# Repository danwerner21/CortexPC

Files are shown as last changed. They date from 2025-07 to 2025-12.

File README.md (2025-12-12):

# CortexPC

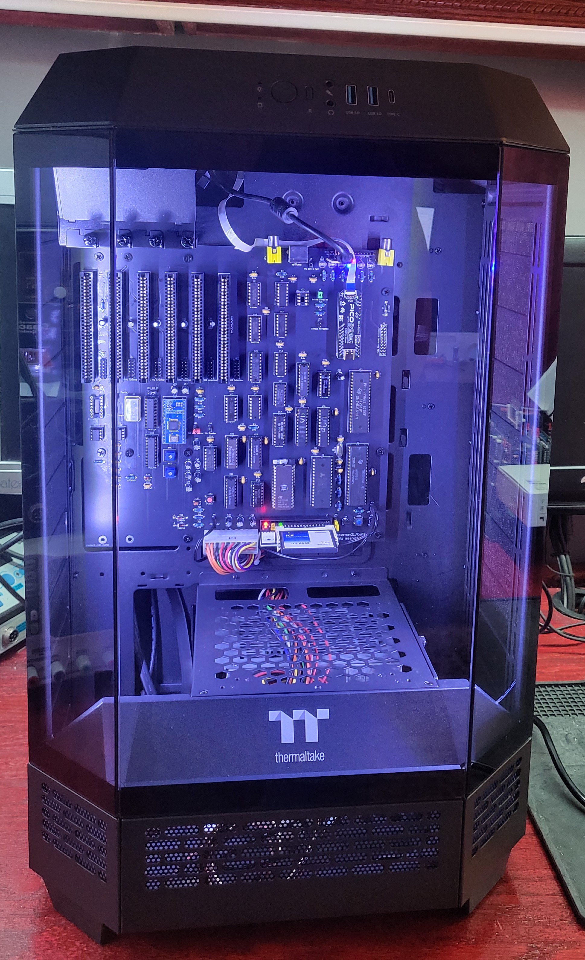
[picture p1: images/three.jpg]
CortexPC


This is an ATX format implimentation of the Mini-Cortex system by Paul Ruizendaal and Stuart Conner.  The Mini-Cortex system is a further development of a TMS 9995 breadboard project to produce a system similar to a Powertran Cortex, but using more modern components. The system is based around a TMS 9995 running at 3 MHz, with 32K byte EEPROM, and will use 512K bytes of RAM  accessed through a memory mapper. An on-board serial port and IDE interface exists on the card.  There is also provisions for a TMS9918 clone, a keyboard and some expansion slots -- these are not totally supported by the firmware at this time however.

The main EEPROM image provides a boot menu which enables the user to select between the EVMBUG system monitor from TI's TMS 9995 Evaluation Module, a port of the Powertran Cortex Power BASIC made for a TM 990 computer, the Marinchip Disk Executive (MDEX) operating system, and an implementation of V6 Unix including a C compiler.

[Much more information can be found at Stuart's site](https://www.stuartconner.me.uk/mini_cortex/mini_cortex.htm)

[Source code for the Cortex Version of Unix V6 and a ton more TI990 software (including cross development tools) can be found here on Dave Pitts' TI-990 web page.](https://www.cozx.com/dpitts/ti990.html)

## Memory Map
The memory map is shown in the table below.

```
Memory Address	Mapped To
>0000 - >7FFF	ROM when enabled, otherwise RAM
>8000 - >EFFF	RAM
>F000 - >F0FB	TMS 9995 internal RAM
>F0FC - >FDFF	RAM
>FE00 - >FE03	CF card ATA registers 
>FE08 - >FE08	SN76489 SOUND
>FE20 - >FE21	Video
>FE40 - >FE4F	Memory mapper registers 0-15 
>FE60 - >FE7F	SID Chip
>FE80 - >FEBF	Offboard IO (ports $80-$FF)
>FFF0 - >FFF9	RAM
>FFFA - >FFFF	TMS 9995 internal RAM

CRU Address	Mapped To
>0000 - >003F	TMS 9902 registers
>0040 - >007F	Control signal latch (further details here)
 	(Plus processor internal CRU bits)
    
(Note that in TI Speak ">" means Hexidecimal, so for the rest of us >FFFA is the same as $FFFA or 0xFFFA or FFFAH)
```
[for more information see Stuart's site](https://www.stuartconner.me.uk/mini_cortex/mini_cortex.htm)

## Creating CF card Image for MDEX and Unix

The CF card has to be newly formatted with an MBR (master boot record), a single partition formatted as FAT32, and a cluster size of 4096 bytes - the CF card needs to be at least 256 MB to support this. Not all brands/sizes of CF card seem to work - you may have more success with an older, low capacity card. A SanDisk 2.0GB card with a "SDCFB" marking on the back works well.

It can be problematic formatting a new card using Windows 10 as it does not always seem to write an MBR to the card. I use a formatting utility called Rufus [details and download here](https://rufus.ie/en/) with Boot selection==Non bootable, Partition Scheme==MBR, File System=FAT32, and Cluster Size= 4096 Bytes. Once the card is correctly formatted, use Windows to write the four files from the software folder ZIP filedirectly to the card.
[for more information see Stuart's site](https://www.stuartconner.me.uk/mini_cortex/mini_cortex.htm)

## Jumper Settings
```
  P6 - ATX Case Power Button
  JP1- ATX Case Reset Button
  JP3- SID Chip CS (Some SID replacement chips need 2-3, default 1-2)
  J21- Enable SID Audio Amp
  J20- SID Speaker Out
  J22- SN76489 Audio Amp
  J23- SN76489 Speaker Out
  J1 - F18A TANG NANO Connector 
  J4 - Serial Interrupt Enabled (Required for UNIX)
  J5 - TTL Serial Interface
  J6 - TTL Serial Power Enable
  JP2- Enable Keyboard Interface
  JP4- ATX Case IDE Led output
  JP5- IDE Power Enable (2-3 for VCC on IDE Pin 20)
  
```
## Powering up
The serial port on the TMS9995 board is configured for 9600 Baud, 7 data bits, even parity, one stop bit, no flow control.

The EVMBUG monitor and the boot loaders for MDEX and Unix, are stored on a single 32K byte EEPROM. The required application is selected from a boot menu. To display the boot menu, connect the board to a configured serial port on a PC, apply power then press any key.

You should then see:
```
  ___         _           ___  ___
 / __|___ _ _| |_ _____ _| _ \/ __|
| (__/ _ \ '_|  _/ -_) \ /  _/ (__
 \___\___/_|  \__\___/_\_\_|  \___|

TMS9995 COMPUTER SYSTEM
BIOS V1.0

PRESS 1 FOR EVMBUG MONITOR
PRESS 2 FOR MDEX
PRESS 3 FOR UNIX
```
To select a software application from the menu, press the corresponding numeric key.

## Useful Links
MDEX documentation is available on the site http://www.powertrancortex.com/documentation.html. The documentation and MDEX disks were recovered and made available by Dave Hunter, the owner of the www.powertrancortex.com site. Porting of the MDEX files to the Mini-Cortex was by Paul Ruizendaal. On the Mini-Cortex, the files are stored in two emulated disks on the CF card.

The first version of Unix ported was LSX Unix (https://www.mailcom.com/lsx/), which was designed to run with 40K byte RAM and two 256K byte floppies. LSX Unix was adapted from Unix V6 by Dr. Heinz Lycklama (https://www.60bits.net/msu/mycomp/terak/termubel.htm). This port has been further ported to the TI 990 minicomputer by Dave Pitts, who has also made improvements to the code build system.

[Dave Pitts' TI-990 web page.](https://www.cozx.com/dpitts/ti990.html)
[EVMBUG documentation](https://www.stuartconner.me.uk/tibug_evmbug/tibug_evmbug.htm#evmbug)

## Bugs/To Do
* No known bugs in V0.9
* Keyboard Firmware needs created and tested

## Troubleshooting

The first test image tests just the processor (TMS9995_test_1_eprom_image), the EPROM and the EPROM chip select logic. Program and fit the EPROM, power on, press the reset switch.  The CPU should execute a loop from ROM., then use the logic probe to check for a series of pulses on pin 20 of the EPROM every 2 seconds or so. 

If the first test passes, repeat with the second test image (TMS9995_test_2_eprom_image), which also tests the RAM and the RAM chip select logic. With the second test, a series of pulses should be seen on pin 20 of the EPROM every 6 seconds or so.

The third test image has two versions.   The first version configures the serial port to 9600 Baud, 7 bits/character, even parity, 2 stops bits, no flow control, and then loops continually sending the ASCII characters >21 ("!") to >7E .  This version tests most of the system including ROM and RAM.   The second version is a ROM only version. It also configures the serial port to 9600 Baud, 7 bits/character, even parity, 2 stops bits, no flow control, and then loops continually sending the ASCII characters >21 ("!") to >7E , but does not use any external RAM.

## Patches
* none needed for V0.9
 
## BOM
Reference|Value|Qty|Description
---------|-----|---|-----------
C1,C2,C3,C4,C5,C6,C7,C8,C9,C10,C11,C12,C13,C14,C15,C16,C17,C19,C21,C23,C25,C27,C29|0.1u|23|
C18,C20,C22,C24|10u|4|
C26|22u|1|
C28|47uF|1|
C30|1uF|1|Polarized capacitor
C31|10uF|1|Polarized capacitor
C32|0.1 uF|1|Unpolarized capacitor
C33|0.01 uF|1|Unpolarized capacitor
C34|100µF|1|
C35|0.1µF|1|
C40,C41|15pf|2|
D1|PWR|1|LED
D2|IDLE|1|LED
D3|MAP|1|LED
D5|1N5817|1|20V 1A Schottky Barrier Rectifier Diode, DO-41
D6|IDE ACT|1|LED
D8|Tx|1|LED
D9|Rx|1|LED
D10,D11|1N4148|2|100V 0.15A standard switching diode, DO-35
J1|F18A TANG NANO Connector|1|Generic connector, double row, 02x10, odd/even pin numbering scheme (row 1 odd numbers, row 2 even numbers), script generated (kicad-library-utils/schlib/autogen/connector/)
J2,J8,J11,J13,J15,J17|IRQ Selection|6|Generic connector, double row, 02x06, odd/even pin numbering scheme (row 1 odd numbers, row 2 even numbers), script generated (kicad-library-utils/schlib/autogen/connector/)
J3,J10,J12,J14,J16,J18|Bus_I_not_SA_8bit|6|8-bit ISA-PC bus connector
J4|Enable Serial Int|1|Generic connector, single row, 01x02, script generated
J5|TTL SERIAL 0|1|
J6|TTL SER 0 PWR|1|
J7|USER OUT|1|Generic connector, single row, 01x07, script generated
J9|AUDIO OUT|1|coaxial connector (BNC, SMA, SMB, SMC, Cinch/RCA, LEMO, ...)
J19|Parallel Keyboard IN|1|Generic connector, single row, 01x11, script generated
JP1|JUMPER|1|Generic connector, single row, 01x02, script generated (kicad-library-utils/schlib/autogen/connector/)
JP4|EXT IDE LED|1|
JP5|IDE PWR|1|
P1|14.31818 MHz CLK|1|
P4|8 BIT IDE (CF)|1|
P5|CONN_10X2|1|Generic connector, double row, 02x10, odd/even pin numbering scheme (row 1 odd numbers, row 2 even numbers), script generated (kicad-library-utils/schlib/autogen/connector/)
P6|POWER_SW|1|Generic connector, single row, 01x02, script generated (kicad-library-utils/schlib/autogen/connector/)
R1,R3,R6,R7,R11,R12,R13,R17|470|8|-- mixed values --
R2,R4,R8,R10,R14|10K|5|
R5|1000|1|Resistor
R9|10Ω|1|
R16,R18|10k|2|Resistor
SW1|RESET|1|Push button switch, generic, two pins
SW2|POWER|1|Push button switch, generic, two pins
U1|74LS14|1|
U2|74LS07|1|
U3|TMS9995-DIP_1|1|
U4|74LS04|1|
U5,U27|74LS74|2|-- mixed values --
U6|74LS112|1|
U7|SN76489|1|
U8|DS1233|1|
U9|SRAM_512K|1|512K x 8 Low Power CMOS RAM, DIP-32
U10|TMS9918 EMU|1|
U11,U30|GAL22V10|2|
U12,U13|74LS32|2|Quad 2-input OR
U14,U28,U29,U31|74LS244|4|Octal Buffer and Line Driver With 3-State Output, active-low enables, non-inverting outputs
U15|74LS138|1|
U17|74LS688|1|
U18|27C256|1|
U21|TMS9902A|1|
U22|74LS259|1|
U23|74LS612-DIP|1|
U25|74LS245|1|Octal BUS Transceivers, 3-State outputs
U26|74HCT14|1|Hex inverter schmitt trigger
Y1|12MHz|1|

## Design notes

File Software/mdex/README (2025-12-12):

Software originally from:  https://gitlab.com/marinchip/

INTRODUCTION

These are the recreated source files for the MDEX operating system. The drivers
are surviving from the 1980's and the kernel source was mostly recreated in
the mid-80's by Peter Buro. The recommenting was completed in 2024.

MARINCHIP DISC EXECUTIVE - MDEX

As John Walker was bootstrapping his software stack, he needed a simple OS.
This became MDEX. It is similar to early CP/M or RT11 in its structure. In
order to be forward compatible, the system call interface was chosen to be
a subset of the NOS/MT operating system that John was already designing.
This proved very successful: nearly all programs that run under NOS/MT also
run under MDEX.

The unintended result was that MDEX became more popular than NOS/MT, also
because it did not need a hard disk (NOS/MT can run from floppies, but is
comfortable with a hard disk).

Being only 8KB in size with a simple, easy to understand internal structure,
it is a good match for retro 9900 based projects, as it gives such a project
an instant software stack to work with. It was the first OS to run on the
mini-Cortex.

John Walker writes on his website: "MDEX (which was originally called
Sisyphus Junior) was written with the Univac assembler, downloaded and
tested on my S-100 prototype machine. Debugging was via the PROM monitor,
which allowed examining and changing registers and memory without the
need for a front panel. MDEX, the Assembler, Linker, Editor, and Debugger,
were all originally written on the Univac assembler in its syntax.

The [Marinchip] assembler, however, used the standard TI syntax for its
instructions. When I wrote of MDEX being rewritten as 'native', I was referring
to converting the syntax of the assembly code from that used by the Univac
cross-assembler to native TI syntax which my assembler used and moving the
development from the Univac to the 9900 machine itself. By some time in 1979,
all development had moved to the 9900 and the Univac was no longer used.

I had access to the Univac because I was working for a company that owned it
and used it moonlighting. I had to move development to the 9900 because I
couldn't quit my job and lose access to the Univac until I did so.

In parallel with this software development, Fred Camerer, who had joined the
company as an equal partner, redesigned my two-board S-100 prototype into the
single-board design which became the M9900 CPU. This was designed by hand and
drawn as a logic diagram, from which the board was laid out using red and blue
tape at 4X scale. Part of the final layout was done on my dining room table.

Once we got and debugged the first run of five printed circuit boards, I
replaced the two board wire wrapped prototype in my IMSAI chassis with the
first M9900 CPU. It was completely compatible from the software standpoint, but
also had the ability to use 16-bit memory through the handshake protocol Fred
Camerer invented, which eventually became part of the S-100 standard
(IEEE-696-1983). It also brought out the 9900's CRU peripheral interface to
unused pins on the S-100 bus (of which there were plenty), which allowed access
to the serial ports on the PROM/RAM and eventual Quad SIO cards."

BUILDING

The MDEX kernel is a single 2400 line assembler file. Its main parts are
the command loop, the system call library and the console line editor -
complemented by a few libraries for message formatting, memory management
and floating point emulation.

It has three device drivers: one for the console terminal, one for the
printer and one for the disk drives.

The combined kernel is built with the make.sh script in the root directory
of this repo.

RUNNING

The Cortex emulator can run MDEX. It needs to be provided with two floppy
disk images, mdex1.dsk and mdex2.dsk respectively. These will be drive
"1/" and dirve "2/" inside MDEX.

Two images are provided: the MDEX release disk ("1/") and the basic games
disk ("2/"). Other images of original 640KB MDEX disks (for instance from
the www.powertrancortex.com website) can be used instead, such as the
QBasic, Pascal and SPL compiler disks.

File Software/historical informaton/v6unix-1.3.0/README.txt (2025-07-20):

V6 Unix 1.3.0
Date: 2020/10/01

I. Introduction

The V6 Unix distribution supports the TI-990 line of minicomputers. The models
supported are 990/10, 990/10A and 990/12 with a minimum of 512K of memory.
Also, supported is the Powertran Cortex using the TI TMS9995 chip with extended
memory.

The devices support in the version:

   DISK      - Any 10MB or larger TILINE disk. Address >F800 interrupt 13.
   TAPE      - TILINE attached tape drive. Address >F880 interrupt 9.
   Printer   - Serial printer on CRU >60 interrupt 14.
   Console   - Serial terminals:
      TTYEIA: TTY/EIA Card:
         tty0 - CRU >0 interrupt 6
      TTY9902: TMS9902 console port:
         tty0 - 990/10A CRU >1700 interrupt 8, Cortex CRU >0 interrupt 4.
   Terminals   - Serial terminals:
      VDT911: 911 VDT, runs as a "glass" tty:
         tty1 - port 0, CRU >100 interrupt 10
         tty2 - port 1, CRU >120 interrupt 8
      TTY403: CI 403 serial multiplexor, Address >F980 interrupt 11:
         tty3 - port 0.
         tty4 - port 1.
         tty5 - port 2.
         tty6 - port 3.

II. Build the System

To build the V6 Unix you need to download and extract the source tarball:

   $ tar xzf v6unix-1.3.0-source.tar.gz
   $ cd v6unix

Then run make:

   $ make [MODEL=model] [DISK=disk] [CONSOLE=console] [MAXSIZE=maxsize]

Where:

   model   - TI990, TI990_10A, TI990_12 or TI_CTX, Default = TI990.
             TI990     - Standard TI-990.
             TI990_10A - /10A support, console port and Extended instructions.
             TI990_12  - /12 support, Extended instructions.
	     TI_CTX    - Powertran Cortex using a TMS9995 chip.

   disk    - DS10, DS25, DS50, DS80, DS200, DS300 or larger disk,
	     Default = DS50.

   console - TTYEIA or TTY9902, Default = TTYEIA.
             TTYEIA  - TTYEIA cards.
             TTY9902 - TMS9902 console port. Only on TI990_10A and TI_CTX.

   maxsize - Size of / filesystem in bytes. Default = 33024000 (64500 blocks).
             DS10 = 3643000 (7115 blocks)
	     DS25 = 19301000 (37697 blocks)

The swap area, 1024 blocks, limits the size of the / file system to 33024000
bytes or 64500 blocks. V6 Unix limits the size of filesystems to a mximum of
65535 blocks. On smaller devices the root partition on the primary device will
be the size of the device minus the swap area.

III. Run the System

To run the system as shown here you will need to download, build and install 
the sim990 simulator. The Powertran Cortex is not supported by sim990.

1. To run under sim990, with the default build, place the following into a
   configuration file (v6unix.cfg):

   a ce >0 6 TTY
   a pe >60 14 print.out
   a v0 >100 10 2011
   a v1 >120  8 2012
   a a30 >F980 11 LOOP
   a a31/t >F980 11 2013
   a a32/t >F980 11 2014
   a m0 >F880 9 NULL
   a d0 >F800 13 v6unix.dsk
   b d0

   The terminal tty0 is the console and the additional terminals tty1, tty2,
   tty4 and tty5 are accessible using telnet on ports 2011, 2012, 2013 and 2014.

   The terminals tty1 and tty2 are 911 VDTs. The terminals tty4 and tty5 are 
   CI403 connected serial terminals.

   The terminals have the login process started on them based upon the
   /etc/ttys file (man 5 ttys). As a default only the console (/dev/tty0) has
   a login process.

   tty3 is allocated to the network process as SLIP device sl0. The
   configuration file, above, is set to loopback. For a real serial connection
   you can configure the device for example:

   a a30/r >F980 11 /dev/tty1

2. Start sim990

   $ sim990 -msc 12 1m v6unix.cfg
   TI 990 simulator 3.5.6: /12 CPU 1024K

   Mem................1024KB
   Initialize Date/Time
      Year: 2020
     Month: 8
       Day: 6
      Hour: 8
    Minute: 49
   Thu Aug 06 08:49:00 2020
   Booting V6 Unix
   Network process running.

   login: 

3. Login

   Two accounts have been provided for user:

   Username: root	Password: root
   Username: guest	Password: guest 

   For example:

   login: guest
   Password: 
   ***********************************
   *   Running Unix V6 on a TI-990   *
   ***********************************

   $ ls
   hello.c        makefile       romans.l       
   $ make
   cc -o hello hello.c
   lex -t romans.l >romans.c
   cc -o romans romans.c -L/lib -lln
   $ hello
   Hello World!
   $ romans
   MMXIV IX
   2014 + 9 = 2023
   $ exit

   login:

IV. Disk Partitions

This implementation supports a maximum of 16 partitions of a maximum of 65535
blocks per partition. When the system is booted it probes the disk geometry and 
creates a table in the kernel of active drives and paritions. Then /dev entries
are created for each active disk and partition. The boot disk partition, if on
unit 0, is /dev/dsk0. Additional, as needed, partitions on the drive are
/dev/dsk0p1 through /dev/dsk0p15. On smaller disks you may only have the root
partition. This works out to a maximum supported disk size of 512MB.

For example on the default DS50 disk there are only two partitions:

   /dev/dsk0   - Root/boot partition (64500 blocks, 1024 blocks swap).
   /dev/dsk0p1 - 11836 blocks.

For a DS200 the partitions are:

   /dev/dsk0   - Root/boot partition (64500 blocks, 1024 blocks swap).
   /dev/dsk0p1 - 65535 blocks.
   /dev/dsk0p2 - 65535 blocks.
   /dev/dsk0p3 - 65535 blocks.
   /dev/dsk0p4 - 31368 blocks.

For a DS10 only the root partition, less the swap area.

   /dev/dsk0   - Root/boot partition (7115 blocks, 1024 blocks swap).

The mkfs program, /etc/mkfs, will probe the size of the partition, as default,
and create the filesystem to the maximum size for that partition. For example
on the default DS50 disk:

   # /etc/mkfs /dev/dsk0p1
   # /etc/mount /dev/dsk0p1 /mnt
   # df
   Filesystem    512B-blocks       Used  Available Use% Mount
   /dev/dsk0           64500       4107      60393   6% /
   /dev/dsk0p1         11836        222      11614   1% /mnt

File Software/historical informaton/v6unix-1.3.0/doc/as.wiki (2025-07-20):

<b>AN INTRODUCTION TO THE TI990 UNIX ASSEMBLER</b>

This document describes the usage and input syntax of the ancient Unix TI990 assembler <b>as</b>.
The details of the TI990 architecture are not described.
The input syntax of this assembler is generally similar to that of the original Ritchie PDP-11 assembler.
The actual code is a derivative of Richard Miller's assembler for the port of Unix to the Interdata 7/32.
This document is a derivative of the Ritchie file note on the Unix assembler. 

The <b>as</b> assembler is a rather ordinary assembler without macro capabilities.
It produces an output file that contains relocation information and a complete symbol table;
thus the output is acceptable to the Unix link-editor <b>ld</b>, which may be used to combine the outputs
of several assembler runs and to obtain object programs from libraries.
The output format has been designed so that if a program contains no unresolved references to external
symbols, it is executable without further processing.

<br>
<b>1. Usage</b>

The command line syntax for <b>as</b> as follows:
<verbatim>
  as [−u] [-l] [−o outfile] infile [,infile]...
</verbatim>
If the optional "−u" argument is given, all undefined symbols in the current assembly will be made
<i>undefined-external</i>. Also see the .globl directive below.
If the optional "-l" argument is given, a listing file is printed to the standard output.
The output of the assembler is by default placed on the file a.out in the current directory;
the optional "−o" flag causes the output to be placed on the named file.
If there were no unresolved external references, and no errors detected, the output file is marked executable;
otherwise, if it is produced at all, it is made non-executable.
The other arguments name files which are concatenated and assembled. Thus programs may be written in
several pieces and assembled together.

<br>
<br>
<b>2. Lexical conventions</b>

Assembler tokens include identifiers (alternatively, "symbols" or "names"), temporary symbols, constants, and operators.

<u>2.1 Identifiers</u>

An identifier consists of a sequence of alphanumeric characters (including period ".", underscore "_",
and tilde " ̃" as alphanumeric) of which the first may not be numeric. Only the first eight characters are significant.
When a name begins with a tilde, the tilde is discarded and that occurrence of the identifier generates a unique entry
in the symbol table which can match no other occurrence of the identifier. This feature is used by the C compiler to
place names of local variables in the output symbol table without having to worry about making them unique.

<u>2.2 Temporary symbols</u>

A temporary symbol consists of a single digit followed by "f" or "b". Temporary symbols are discussed fully in section 5.1.

<u>2.3 Constants</u>

Constants are 16 bit quantities and can have one of four forms:
  *  a constant starting with the sequence "0x" is a hexadecimal number constant.
  *  a constant starting with the digit "0" is an octal constant. A digit larger than 7 terminates the constant.
  *  a constant starting with one of the other digits (i.e. "1" through "9") is a decimal constant
  *  a constant starting with a single quote (') initiates a character constant.

Numeric constants can have any number of digits, but the value is truncated to the lower 16 bits of the resulting number.
The constant is interpreted as a two’s complement value: -1 and 65535 both denote a constant with 16 "1" bits.

A single-character constant consists of a quote followed by an ASCII character not a new-line, followed by another
single quote. Certain dual-character escape sequences are acceptable in place of the ASCII character to represent
new-line and other non-graphics (see String statements, section 5.5). The constant’s value has the code for the
given character in the least significant byte of the word and is null-padded on the left. It is permissible to have
a second ASCII character following the first, to make up a word sized constant. In that case the constant’s value has
the code for the first given character in the least significant byte and that for the second character in the most
significant byte. Character constants with either zero or more than 2 ASCII characters occuring between the opening
and closing quote constitute a syntax error.

<u>2.4 Operators</u>

There are several single character operators; see section 6.

<u>2.5 Blanks</u>

Blank and tab characters may be interspersed freely between tokens, but may not be used within tokens
(except character constants). A blank or tab is required to separate adjacent identifiers or constants not
otherwise separated.

<u>2.6 Comments</u>

The two character sequence "//" (slash-slash) introduces a comment, which extends through the end of the line on
which it appears. Comments are ignored by the assembler.

<br>
<b>3. Segments</b>

Assembled code and data fall into three segments: the text segment, the data segment, and the bss segment.

  *  The text segment is the one in which the assembler begins, and it is the one into which instructions
are typically placed. The UNIX system will, if desired, enforce the purity of the text segment of programs
by trapping write operations into it. Object programs produced by the assembler must be processed by the
link-editor <b>ld</b> (using its "−n" flag) if the text segment is to be write-protected. A single copy of
the text segment is shared among all processes executing such a program.

  *  The data segment is available for placing data or instructions which will be modified during execution.
Anything which may go in the text segment may also be put into the data segment. In programs with write-protected,
sharable text segments, data segment contains the initialized but variable parts of a program. If the text segment
is not pure, the data segment begins immediately after the text segment; if the text segment is pure, the data
segment begins at the lowest 8K byte boundary after the text segment.

  *  The bss segment may not contain any explicitly initialized code or data. The length of the bss segment
(like that of text or data) is determined by the high-water mark of the location counter within it. The bss segment
is actually an extension of the data segment and begins immediately after it. At the start of execution of a
program, the bss segment is set to 0. Typically the bss segment is set up by statements exemplified by
<verbatim>
lab: . = .+10
</verbatim>
The advantage in using the bss segment for storage that starts off empty is that the initialization information
need not be stored in the output file.

The assembler switches between the three segments through the pseudo statements <b>.text</b>, <b>.data</b> and
<b>.bss</b>, which are discussed in section 7.6, 7.7 and 7.8.

Each segment has its own location counter during assembly and the segments are relocated to their sequential
positions at the very end of the assembly process (and possibly again by the link-loader <b>ld</b>). See also
section 4, Location counter and section 5.4, Assignment statements.

<br>
<b>4. The location counter</b>

One special symbol, ".", refers to the location counter of the current segment. Its value at any time is
the offset within the appropriate segment of the start of the statement in which it appears. The location
counter may be assigned to, with the restriction that the current segment may not change.

<br>
<b>5. Statements</b>

A source program is composed of a sequence of statements. Statements are separated either by newlines or by
semicolons. There are five kinds of statements:
  *  null statements
  *  expression statements
  *  assignment statements
  *  string statements
  *  keyword statements.

Any kind of statement may be preceded by one or more labels.

<u>5.1 Labels</u>

There are two kinds of label: name labels and numeric labels. A name label consists of a name followed by
a colon (":"). The effect of a name label is to assign the current value and type of the location counter (".")
to the name. An error is indicated in the first pass if the name is already defined; an error is indicated in
subsequent passes if the (".") value assigned changes the definition of the label.

A numeric label consists of a digit 0 to 9 followed by a colon (":"). Such a label serves to define temporary
symbols of the form "<i>n</i>b" and "<i>n</i>f", where <i>n</i> is the digit of the label. As in the case of
name labels, a numeric label assigns the current value and type of "." to the temporary symbol. However, several
numeric labels with the same digit may be used within the same assembly. References of the form "<i>n</i>f" refer
to the first numeric label "<i>n</i>:" <u>f</u>orward from the reference;
"<i>n</i>b" symbols refer to the first "<i>n</i>:" label <u>b</u>ackward from the reference. This sort of temporary
label was introduced by Knuth in "The Art of Computer Programming, Vol I: Fundamental Algorithms". Such labels
tend to conserve both the symbol table space of the assembler and the inventive powers of the programmer.

<u>5.2 Null statements</u>

A null statement is an empty statement (which may, however, have labels). A null statement is ignored by the
assembler. Common examples of null statements are empty lines or lines containing only a label.

<u>5.3 Expression statements</u>

An expression statement consists of an arithmetic expression not beginning with a keyword. The assembler computes
its (16-bit) value and places it in the output stream, together with the appropriate relocation bits.

<u>5.4 Assignment statements</u>

An assignment statement consists of an identifier, an equals sign ( = ), and an expression. The value and type of
the expression are assigned to the identifier. It is not required that the type or value be the same in pass 2 as
in pass 1, nor is it an error to redefine any symbol by assignment.

Any external attribute of the expression is lost across an assignment. This means that it is not possible to declare
a global symbol by assigning to it, and that it is impossible to define a symbol to be offset from a non-locally
defined global symbol.

As mentioned, it is permissible to assign to the location counter ".". It is required, however, that the type of
the expression assigned be of the same type as ".", and it is forbidden to decrease the value of ".".
In practice, the most common assignment to "." has the form ". = . + n" for some number n; this has the effect
of generating n null bytes.

<u>5.5 String statements</u>

A string statement generates a sequence of bytes containing ASCII characters. A string statement consists of a double
quote <b>"</b> followed by a sequence of ASCII characters not including newline, followed by a closing double quote
<b>"</b>. Any of the ASCII characters may be replaced by a two-character escape sequence to represent certain
non-graphic characters, as follows:
<table>
<tr><td><u>Escape</u></td><td><u>Hex</u>&nbsp;&nbsp;&nbsp;</td><td><u>Meaning</u></td></tr></b>
<tr><td>\n</td><td>0x0a</td><td>newline</td></tr>
<tr><td>\r</td><td>0x0d</td><td>carriage return</td></tr>
<tr><td>\t</td><td>0x0b</td><td>horizontal tab</td></tr>
<tr><td>\v</td><td>0x0c</td><td>vertical tab</td></tr>
<tr><td>\0</td><td>0x00</td><td>null</td></tr>
</table>

All other characters following a \ represent themself, i.e. \\ denotes a single backslash and \" denotes a double quote.
The latter does not terminate the string, but becomes a character of the string. The same escape sequences may also be
used within singlea nd double-character constants (see section 2.3 above).

<u>5.6 Keyword statements</u>

Keyword statements are numerically the most common type, since machine instructions are of this sort. A keyword
statement begins with one of the many predefined keywords of the assembler; the syntax of the remainder depends on
the keyword. Section 8 discusses machine instructions and their syntax in more detail.

<br>
<b>6. Expressions</b>

An expression is a sequence of symbols representing a value. Its constituents are identifiers, constants,
temporary symbols, operators, and brackets. Each expression has a type.
All operators in expressions are fundamentally binary in nature; if an operand is missing on the left,
a 0 of absolute type is assumed. Arithmetic is two’s complement and has 16 bits of precision. All
operators have equal precedence, and expressions are evaluated strictly left to right; parentheses are
reserved for addressing modes and cannot be used for expression grouping.

<u>6.1 Expression operators</u>

The operators are:
<table>
<tr><td>+</td><td>addition</td></tr>
<tr><td>-</td><td>subtraction</td></tr>
<tr><td>*</td><td>multiplication</td></tr>
<tr><td>/</td><td>division</td></tr>
<tr><td>|</td><td>bitwise or</td></tr>
<tr><td>&</td><td>bitwise and</td></tr>
</table>
All operators work on 16 bit two's complement words and overflow is not detected.

<u>6.2 Types</u>

The assembler deals with a number of types of expressions. Most types are attached to keywords and used
to select the routine which treats that keyword. The types likely to be met explicitly are:
  *  <u>undefined</u>: Upon first encounter, each symbol is undefined. It may become undefined if it is
assigned an undefined expression. It is an error to attempt to assemble an undefined expression in pass 2;
in pass 1, it is not (except that certain keywords require operands which are not undefined).

  *  <u>undefined external</u>: A symbol which is declared <b>.globl</b> but not defined in the current
assembly is an undefined external. If such a symbol is declared, the link editor <b>ld</b> must be used to
load the assembler’s output with another routine that defines the undefined reference.

  *  <u>absolute</u>: An absolute symbol is defined ultimately from a constant. Its value is unaffected
by any possible future applications of the link-editor to the output file.

The value of a text symbol is measured with respect to the beginning of the text segment of the program. 
  *  <u>text</u>: The value of a text symbol is measured with respect to the beginning of the text segment
of the program. If the assembler output is link-edited, its text symbols may change in value since the
program need not be the first in the link editor’s output. Most text symbols are defined by appearing
as labels. At the start of an assembly, the value of "." is text 0.

  *  <u>data</u>: The value of a data symbol is measured with respect to the origin of the data segment of a program.
Like text symbols, the value of a data symbol may change during a subsequent link-editor run since previously
loaded programs may have data segments. After the first .data statement, the value of "." is data 0.

  *  <u>bss</u>: The value of a bss symbol is measured from the beginning of the bss segment of a program.
Like text and data symbols, the value of a bss symbol may change during a subsequent link-editor run,
since previously loaded programs may have bss segments. After the first .bss statement, the value of "." is bss 0.

  *  <u>external absolute, text, data, or bss</u>: Symbols declared .globl but defined within an assembly
as absolute, text, data, or bss symbols may be used exactly as if they were not declared .globl; however,
their value and type are available to the link editor so that the program may be loaded with others that
reference these symbols.

The assembler does not have a separate type for registers: these are refered to by an absolute value in
the range 0 to 15. The assembler predefines the symbols <b>r0</b> through to <b>r15</b> with these values
to make source code easier to read. As a consequence, one can refer to r3 as "r0+3".
<b>sp</b> is a synonym for <b>r15</b> and <b>bp</b> is a synonym for <b>r14</b>.

Each keyword known to the assembler has a type which is used to select the routine which processes the
associated keyword statement. The behavior of such symbols when not used as keywords is the same as if
they were absolute.

<u>6.3 Type propagation in expressions</u>

When operands are combined by expression operators, the result has a type which depends on the types of
the operands and on the operator. The rules involved are complex to state but were intended to be sensible
and predictable. For purposes of expression evaluation the important types are
  *  undefined
  *  absolute
  *  text
  *  data
  *  bss
  *  undefined external
  *  other

The combination rules are then:
  *  If one of the operands is undefined, the result is undefined.
  *  If both operands are absolute, the result is absolute. If an absolute is combined with one of
the "other types" mentioned above, the result has the other type.
  *  If two operands of "other type" are combined, the result has the numerically larger type
  *  An "other type" combined with an explicitly discussed type other than absolute acts like an absolute.

Further rules applying to particular operators are:
  *  "+": If one operand is text-, data-, or bss-segment relocatable, or is an undefined external,
the result has the postulated type and the other operand must be absolute.
  *  "−": If the first operand is a relocatable text-, data-, or bss-segment symbol, the second operand
may be absolute (in which case the result has the type of the first operand); or the second operand may
have the same type as the first (in which case the result is absolute). If the first operand is external
undefined, the second must be absolute. All other combinations are illegal.

<br>
<b>7. Pseudo-operations</b>

The keywords listed below introduce statements that generate data in unusual forms or influence the later
operations of the assembler. The meta notation "<nowiki>[stuff]...</nowiki>"
means that zero or more instances of the given stuff may appear. Also, boldface tokens are literals,
italic words are substitutable.

<b>7.1 .byte</b> <i>expression <nowiki>[ ,expression]...</nowiki></i>

The expressions in the comma-separated list are truncated to 8 bits and assembled in successive bytes. The
expressions must be absolute. This statement and the string statement above are the only ones that
assemble data one byte at at time.

<b>7.2 .even</b>

If the location counter "." is odd, it is advanced by one so the next statement will be assembled at a word
boundary.

<b>7.3 .if</b> <i>expression</i>

The <i>expression</i> must be absolute and defined in pass 1. If its value is nonzero, the <b>.if</b> is
ignored; if zero, the statements between the <b>.if</b> and the matching <b>.endif</b> (below) are ignored.
<b>.if</b> may be nested. The effect of <b>.if</b> cannot extend beyond the end of the input file in which
it appears.

<b>7.4 .endif</b>

This statement marks the end of a conditionally-assembled section of code. See <b>.if</b> above.

<b>7.5 .globl</b> <i><nowiki>name [, name]...</nowiki></i>

This statement makes the names external. If they are otherwise defined (by assignment or appearance as a
label) they act within the assembly exactly as if the <b>.globl</b> statement were not given; however, the link
editor <b>ld</b> may be used to combine this routine with other routines that refer these symbols.

Conversely, if the given symbols are not defined within the current assembly, the link editor can combine
the output of this assembly with that of others which define the symbols. As discussed in section 1, it is
possible to force the assembler to make all otherwise undefined symbols external.

<b>7.6 .text</b>

<b>7.7 .data</b>

<b>7.8 .bss</b>

These three pseudo-operations cause the assembler to begin assembling into the text, data, or bss segment
respectively. The location counter is made even, i.e. after sitching segment, an <b>.even</b> statement is
implied. Assembly starts in the text segment. It is forbidden to assemble any code or data into the
bss segment, but symbols may be defined and "." moved about by assignment.

<b>7.9 .comm</b> <i>name , expression</i>

Defines and external symbol of size <i>expression</i>. In effect, <i>name</i> behaves in the current assembly
just like an undefined external. However, the link-editor <b>ld</b> has been special-cased so that all external
symbols which are not otherwise defined, and which have a non-zero value, are defined to lie in the bss segment,
and enough space is left after the symbol to hold expression bytes. All symbols which become defined in this way
are located before all the explicitly defined bss-segment locations.

<br>
<b>8. Machine instructions</b>

The assembler implements all instructions of the TMS9995 processor and several synthetic instructions. The latter
can be thought of as built-in macro's.

<u>8.1 Instruction mnemonics</u>

All the standard mnemonics of the TMS9995 processor are supported. The mnemonics must be in lowercase in order
to be recognised, i.e. "lwpi" is an instruction mnemonic, "LWPI" is an undefined symbol.

<u>8.2 Operands</u>

The assembler uses a different operand syntax than the standard Texas Instruments syntax for the TI990. The
relationship is shown below:
<table>
<tr><td><b>Mode</b></td><td><b>as syntax</b></td><td><b>TI syntax</b></td><td><b>Example</b></td><tr>
<tr><td>register</td><td>rn</td><td>RN</td><td>mov r0,r1</td><tr>
<tr><td>indirect</td><td>(rn)</td><td>*RN</td><td>dec (r1)</td><tr>
<tr><td>auto increment&nbsp;&nbsp;&nbsp;</td><td>(rn)+</td><td>*RN+</td><td>clr (r1)+</td><tr>
<tr><td>direct</td><td>@name</td><td>@NAME</td><td>s r0,@var</td><tr>
<tr><td>indexed</td><td>@name(rn)&nbsp;&nbsp;&nbsp;&nbsp;</td><td>@NAME(RN)&nbsp;&nbsp;&nbsp;&nbsp;</td><td>mov @table(r1),r0</td><tr>
<tr><td>immediate</td><td>expr</td><td>expr</td><td>lwpi len+1</td><tr>
<tr><td>relative</td><td>expr</td><td>expr</td><td>jmp .+2</td><tr>
</table>

Note that an absolute expression evaluating to a number between 0 and 15 is acceptable whereever a register is
required and that names could be offset by an absolute constant. Relative expressions in jumps must be within
-128 to +127 words from "." in the current segment. Relative expressions in CRU instructions must be absolute
and lie between -128 and +127.

<u>8.3 Extended branch instructions</u>

The assembler accepts a set of synthetic instructions for conditional branches that work both with near (within
-128 to +127 words) and far (all other) destinations:
<table>
<tr><td><b>Mnemonic&nbsp;&nbsp;&nbsp;</b></td><td><b>Meaning</b></td></tr>
<tr><td>bjmp</td><td>branch or jump unconditionally</td></tr>
<tr><td>bjeq</td><td>branch or jump on equal</td></tr>
<tr><td>bjne</td><td>branch or jump on not equal</td></tr>
<tr><td>bjlt</td><td>branch or jump on signed less than</td></tr>
<tr><td>bjls</td><td>branch or jump on signed less or same</td></tr>
<tr><td>bjgt</td><td>branch or jump on signed greater</td></tr>
<tr><td>bjgs</td><td>branch or jump on signed greater or same</td></tr>
<tr><td>bjl</td><td>branch or jump on unsigned lower</td></tr>
<tr><td>bjle</td><td>branch or jump on unsigned lower or equal</td></tr>
<tr><td>bjh</td><td>branch or jump on unsigned higher</td></tr>
<tr><td>bjhe</td><td>branch or jump on unsigned higher or equal</td></tr>
</table>

These instructions are either implemented as one or two conditional jump instructions, or as the reverse
conditional jump(s) over an unconditional branch condition. The "bjmp" instruction expands to either "jmp" or
"b" depending on the destination distance.

<u>8.4 Other instructions</u>

The assembler accepts one special instruction mnemonic, "sys". This instruction takes a single, unadorned
argument and currently expands to a "xop 1" instruction:

  *  "sys 23" expands to "xop @23,1"

This instruction is used to trap into the operating system. It has been added a macro to make it easy to
vary the trap mechanism for various implementations of the TI990 architecture. An alternative trap
mechanism could work with external instructions.

<br>
<b>9. Errors</b>

When an input file cannot be read, its name followed by a question mark is typed and assembly ceases.
When syntactic or semantic errors occur, a diagnostic is typed out together with the line number and
the file name in which it occurred. Errors in pass 1 cause cancellation of pass 2.
The possible errors are:

  *  "Previously defined absolute value required"
  *  "Short branch out of range"
  *  "Illegal or missing opcode"
  *  "Illegal data in .bss segement"
  *  "EOF or END within .if"
  *  "Garbage character"
  *  "Word value too large"
  *  "Improper nesting of .if and .endif"
  *  "Missing label"
  *  "Multiply defined symbol"
  *  "Number syntax"
  *  "Cannot move location counter backwards"
  *  "Symbol value changed between passes"
  *  "Missing quote"
  *  "Relocation error"
  *  "Missing symbol"
  *  "Undefined symbol"
  *  "Illegal value (e.g. register >15)"
  *  "Syntax error"
  *  "Division by zero"
  *  "Too many numeric labels"

<br>
<b>10. Example</b>

The following assembler program prints out "Hello, world!" to the standard output on a Unix system.
<verbatim>
reset:	0xf000; start

start:	stwp	sp
	ai	sp,-6
	mov	@len,@4(sp)
	mov	@str,@2(sp)
	mov	@one,(sp)
	sys	4
	ai	sp,6
	idle

	.data
one:	1		// stdout
str:	1f		// &str
len:	strend - 1f	// len

1:	"Hello, world!\n"
	strend = .
</verbatim>

The assembler list output for the above program is:
<verbatim>
0000t                    00001  
0000t F000a 0004t        00002  reset:	0xf000; start
0004t                    00003  
0004t 02AFa              00004  start:	stwp	sp
0006t 022Fa FFFAa        00005  	ai	sp,-6
000At CBE0a 0028d 0004a  00006  	mov	@len,@4(sp)
0010t CBE0a 0026d 0002a  00007  	mov	@str,@2(sp)
0016t C7E0a 0024d        00008  	mov	@one,(sp)
001At 2C60a 0004a        00009  	sys	4
001Et 022Fa 0006a        00010  	ai	sp,6
0022t 0340a              00011  	idle
0024t                    00012  
0024t                    00013  	.data
0024d 0001a              00014  one:	1		// stdout
0026d 002Ad              00015  str:	1f		// &str
0028d 000Ea              00016  len:	strend - 1f	// len
002Ad                    00017  
002Ad 48656C6C6F2C2077a> 00018  1:	"Hello, world!\n"
0038d                    00019  	strend = .
0038d                    00020
</verbatim>

The suffix letter "t", "d" or "b" after the location denotes the segment that location is associated with.
The suffix letters for the assembled code denote the relocatability of that word:
  *  a = absolute, no relocation
  *  t = relocated with text segment
  *  d = relocated with data segment
  *  b = relacated with bss segment
  *  u = undefined
  *  U = undefined external
  
If the last word or byte value is followed by an angle bracket (">"), there are more words or bytes generated
for that particular line than shown.

The column preceding the source text in the listing is the (decimal) line number.

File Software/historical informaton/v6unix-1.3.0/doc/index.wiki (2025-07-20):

This repository contains a port of the "Ritchie C compiler" to the TI990 series processors, in particular the 9995 and 99105 chips. The port is currently fairly complete; only floating point operations remain unported. Other tool chain components (assembler, linker, etc.) are also provided.

The long term goal is to run ancient unix on these chips. As a first stepping stone on that journey, a port of the original 1983 version of the Xinu system has already been completed. The source for that is also in this repository.

"Ancient Unix" is a term refering to the research versions of the late 70's and early 80's, and typically includes all version intended for 16 bit processors. The last version of this lineage is 2.11BSD, which was maintained until the mid-90's. The source code for ancient unix is generally available under the 3-clause BSD license and can be downloaded from TUHS:
http://www.tuhs.org/

For a contemporary report on porting Unix and its C compiler to new hardware, see the paper [/doc/tip/doc/old-firstport.pdf|"The first Unix port"] by Richard Miller. Apparently it can be done in 6 months using only rudimentary tools! More recently, the BK Unix project has ported LSX Unix (a minimal edition based on Version 6) to a Russian single chip version of the pdp-11/02.

This C compiler is the original compiler for the C language and was written by Dennis Ritchie. It is probably one of the best 16-bit compilers available (along with BLISS-11). In part this compiler can work on such restricted hardware because it separates the compilation process in many steps:
<verbatim>
cc --+
     |
     +-- cpp   C preprocessor
     |
     +-- c0    Syntax and semantic analysis, intermediate code generation
     |
     +-- c1    Intermediate code to assembly conversion
     |
     +-- c2    Assembly level optimiser (optional)
     |
     +-- as    Assembler to object code conversion
     |
     +-- ld    Linker/loader, combine object files into single executable
</verbatim>
The cc program is nothing more than a simple orchestra conductor that hands out work to a series of specialized programs. The preprocessor and 3 compiler phases used in this repository builds on the version included with 2.11BSD and handles nearly all C89 constructs. The assembler is based on Richard Miller's assembler for the Interdata 7/32 and ld on the code in Unix Version 6.

The key part of porting the compiler is porting the 'c1' compiler phase. This phase is described by Dennis Ritchie himself in a paper called [/doc/tip/doc/old-ctour.pdf|"A tour of the C Compiler"]. Note that this document refers to the version of the compiler that was included with Version 6 Unix and predates the one in this repository, but it still gives a good introduction. There is more documentation about the 'c1' code [/doc/tip/doc/toc.wiki|here]

Enjoy!

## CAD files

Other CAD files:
Software/historical informaton/Cortex_BASIC_source/vdpdsr.obj
Software/historical informaton/Cortex_BASIC_source/text.obj
Software/historical informaton/Cortex_BASIC_source/relops.obj
Software/historical informaton/Cortex_BASIC_source/rndf.obj
Software/historical informaton/Cortex_BASIC_source/random.obj
Software/historical informaton/Cortex_BASIC_source/ticf.obj
Software/historical informaton/Cortex_BASIC_source/logops.obj
Software/historical informaton/Cortex_BASIC_source/mwdf.obj
Software/historical informaton/Cortex_BASIC_source/run.obj
Software/historical informaton/Cortex_BASIC_source/move.obj
Software/historical informaton/Cortex_BASIC_source/monitor.obj
Software/historical informaton/Cortex_BASIC_source/cvdb.obj
Software/historical informaton/Cortex_BASIC_source/def.obj
Software/historical informaton/Cortex_BASIC_source/dsr02.obj
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

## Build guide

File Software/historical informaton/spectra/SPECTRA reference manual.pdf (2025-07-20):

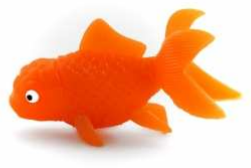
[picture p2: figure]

1 | Spectra 0.1.5 – August 2009

_____ _____ ______ _____ _______ _____
/ ____| __ \| ____/ ____|__ | __| __ \ | /\
| (___ | |__) | |__ | | | | | | |__) | | / \
\___ \| ___/| __|| | | | | | _ / | / /\ \
____) | | | | |___| |____ | | | | | \ \ / ____ \
|_____/|_| | |______\_____| |_| |_| \_\/_/ | \_\
by Retroclouds

## TMS9900 Arcade Game Library

## for the

## Texas Instruments TI-99/4A

## REFERENCE MANUAL

## August 2009

## version 0.1.5

## REVISION

Date | Author | Revision
August 1st 2009 | Filip Van Vooren (Retroclouds) | Initial version SPECTRA version 0.1.5 (“Small Fish”)

## TABLE OF CONTENTS

# Introduction

### What I need to know

Below you find some details regarding SPECTRA you definitely should know about before you start programming your next favourite assembler game.

### License

This program is free software: you can redistribute it and/or modify it under the terms of the GNU General Public License as published by the Free Software Foundation, either version 3 of the License, or at your option any later version.

This program is distributed in the hope that it will be useful, but WITHOUT ANY WARRANTY; without even the implied warranty of MERCHANTABILITY or FITNESS FOR A PARTICULAR PURPOSE. See the GNU General Public License for more details.

You should have received a copy of the GNU General Public License along with this program. If not, see <http://www.gnu.org/licenses/>.

### License EPSGMOD player

Below I’ve included Tursi’s conditions dated July 14

th 2009 for the usage of the EPSGMOD tracker in SPECTRA:

You may use my version of the EPSGMod tracker, and any future versions I release for the TI-99/4A and compatible machines, in your library, with
any license of your choice (including any version of the GPL), subject to the following conditions:
1) You must get permission from KonTechs - you'll find his contact form on the webpage I linked above. If you can't reach him let me know and I'll forward a note on your behalf. You may include this acceptance on my part.
2) This does not license KonTech's own code, tracker, or any property not created by myself personally or HarmlessLion LLC.
3) You keep a credit to both myself and KonTechs, with web links, in your distribution both in documentation and source.
4) It is always free to download and use your library, and to distribute software based on said library.
5) I have the right to cancel this permission for future releases of the
code, if I have to, by including a note in the distribution to that
effect.

I also got the permission from Martin Konrad (Kontechs) for the usage of Tursi’s EPSGMOD tracker in SPECTRA. I received the below at July 16th 2009:

You have my permission for including Tursi’s EPSGMOD-player in your distribution, as long as the distribution is free. But please inform me about further usages of the player. I’ve sent a copy of this to Tursi, too.

### How it all started

The idea for the implementation of SPECTRA was born while I was working on Pitfall!, my first homebrew game for the Texas Instruments TI-99/4A.

During that time I was studying the Colecovision disassembly of Pitfall! very closely and I learned that the game called some subroutines that are stored in the console’s built-in ROM. Doing some research in the internet revealed that the built-in Colecovision ROM contains a BIOS; in this case a collection of game routines called OS7.

Thanks to the wonderful work of Daniel Bienvenu who documented most of these subroutines, I was able to understand what they were actually for. Surprisingly the OS7 functions are not used that often in homebrew Colecovision games, as they are reported to be slow.

Nonetheless, it inspired me to start working on a similar library for the TI-99/4A. I wanted an open-source library that allows me to concentrate on the actual homebrew game without having to start writing all subroutines from scratch over and over again.

I believe in free software and therefore it is my wish that SPECTRA is free and stays free in the future. This is the reason I opted for distribution with a GPL license.

### One size doesn’t fit all

SPECTRA is perhaps a bit different compared to already existing libraries. First of all I believe in source code. As a matter of fact I don’t like libraries where I don’t have any access to the source code. For sure I’m not pretending to understand all, but at least I want to have the option to take a peek in the source code if something isn’t working the way I expect it.

So the concept behind SPECTRA is that instead of loading the full library, you just include the subroutines that you need for getting the job done. It will save you some memory….

The library is targeted for cross-development on a PC. Even on an old PC assembly times are so fast that I don’t see a big benefit in only using the already assembled object files. Actually there are some big benefits on programming TMS9900 assembly games on a PC. Besides the fact that you can always have your DEV environment with you, the biggest advantage is that there are actually some cool emulators around, with at least one having a good debugger. Last but not least I’m planning on writing a new TMS9900 cross-assembler especially for writing games on the TI-99/4A supporting SPECTRA.

### Compatibility

The source code in SPECTRA is compatible with Burrsofts’ Asm994A Assembler V3.008 This great cross-assembler for Windows is not part of the SPECTRA library, but can be obtained directly at BurrSoft (http://www.99er.net/win994a.shtml).

The assembler is part of the Win994A emulator package and is considered freeware by the author. For further details and verification please check the license conditions at the mentioned BurrSoft page.

### Serviceable parts inside

The library has been tested to some extend, but comes without any warranties whatsoever. There are still plenty of bugs inside and if you find any, let me know and I’ll try to fix them. Better still, why don’t you fix them yourself and send me the updated version.

This not only counts for corrections: I would like to see SPECTRA become a community project. So if you find this library useful, then why don’t you contribute by adding some new functionality. We can then all benefit from it.

Visit the project home page at sourceforge (http://spectra99,sourceforge.net) for obtaining the newest version. You can also report bugs there, discuss SPECTRA in the forum and bring in some new ideas.

### Graphics

Writing a homebrew game is not only about programming, a really big part has to do with implementing graphics and sound effects. For creating graphics I have bundled SPECTRA with a small utility called “Tile Studio Converter” that allows you to easily generate sprite and character patterns of graphics created with Tile Studio.

Tile Studio (http://tilestudio.sourceforge.net) by Wiering Software is a very powerful open source development utility for graphics of tile-based games.
This windows software is NOT included in SPECTRA, but is available for free via the mentioned web link.

### Sound

With the kind permission of both Tursi and Kontechs I have included a slightly modified version of Tursi’s EPSGMOD (http://www.harmlesslion.com) for playing sophisticated sounds and tunes on the TI-99/4A.

Basically the idea is that you create the tune using Kontechs Mod2PSG2 (http://mod2psg2.kontechs.de). Mod2PSG2 is a very powerful music tracker for the SN76489 sound chip that is used in the TI-99/4A, Colecovision, SEGA Master System, …
This windows software is NOT included in SPECTRA, but is available for free via the mentioned web link.

See section “Sound & Speech” for details about the player and refer to the license section for further details on the EPSGMOD usage conditions.

# Base

## BASE

### What I need to know

Below you find some details you definitely should know about before you start programming your next favourite assembler game.

### Required files

The idea is that you only include those parts of SPECTRA that are useful in your game implementation . However, there is one file called spectra_base.a99 that always must be included in your source code. Reason is that it contains a header section that is used for setting up memory and stack, has some basic equates, etc.
As such this file is a prerequisite for all of the subroutines in the library.

Below is the preferred order for including SPECTRA in your game source.

your_game_header.a99
your_game1.a99
your_game2.a99
….
spectra_base.a99 | Always required
spectra_memcpy.a99
spectra_vdp.a99
spectra_tiles.a99
spectra_sprites.a99 | Optional. Depends on your
| game requirements
spectra_timers.a99
spectra_epsgmod.a99
spectra_ctrl_virtkb.a99
your_game_end.a99

### Stack

All subroutines in SPECTRA are called via the branch-and-link (BL) instruction. When a subroutine is called, it first pushes the registers it is about to change on the stack. On subroutine exit they are then popped from the stack again by branching to the appropriate utility routines (POPRGx or POPRXx).
This means that your registers will NOT be destroyed after calling any of the subroutines in the library.
STACK equate | Now for sure you already know that there is no hardware stack pointer in a TMS9900 CPU. As a workaround the stack pointer is simulated by using one of the 16 registers in the workspace.
| In the default configuration SPECTRA uses register R8 as stack pointer.
| You can use another register for this purpose by changing the STACK equate in spectra_base.a99. However, keep in mind to store/restore the correct values when fiddling with this register.
| Be aware that the stack in SPECTRA grows from low memory towards high memory.
STKBUF equate | This equate must contain the address of the memory location that is at the bottom of the stack. The value for this equate depends on the used SPECTRA memory layout. When using the default configuration this will be BLOCK 4 in scratch-pad memory.
| By changing STKBUF in spectra_base.a99 you can decide where the stack will be allocated in memory.

Make sure that on program start STKBUF points to a memory area that is properly initialized. The stack size can grow to 64 bytes when using the default memory configuration.

### Memory layout

The memory layout used by SPECTRA is quite flexible. By default it uses all of scratchpad memory. However you could reconfigure it in such way that none or only part of the scratchpad memory is used. That could be helpful if you want to setup your own ISR hook.

Memory configuration is done in spectra_base.a99 and is basically divided in 5 blocks:

| Block 1: Contains the main workspace (R0-R15)
| Block 2: Contains all variables used by SPECTRA
| Block 3: Free for own use
| Block 4: Subroutine stack
| Block 5: Contains second workspace (R0-R15). Is normally not used but is available as workspace for your BLWP subroutines. Keep in mind however that block 4 can grow into block 5 so you will have to check subroutine dependencies first when using block 5 (*)

Note that blocks 1, 2 and 4 are crucial for SPECTRA to work properly.

SBLOC1
>8300 | BLOCK 1
| 1st workspace

32 bytes

SBLOC2
>8300 + >20 | BLOCK 2
SPECTRA variables

32 bytes

SBLOC3
>8300 + >40 | BLOCK 3

Free for own use
(128 bytes)

128 bytes

SBLOC4
>8300 + >C0 | BLOCK 4
STACK
(can extend into block 5!)

32-64 bytes (*)

SBLOC5
>8300 + >D0 | BLOCK 5
2nd workspace

32 bytes (*)

Below you find the memory header section as included in the file spectra_base.a99

*//////////////////////////////////////////////////////////////
* | SPECTRA SCRATCH-PAD MEMORY USAGE
*//////////////////////////////////////////////////////////////
SCRPAD | EQU | >8300 | ; | 256 bytes scratch-pad
SPCMEM | EQU | SCRPAD
SBLOC1 | EQU | SPCMEM | ; | \ Length | 32 | bytes
SBLOC2 | EQU | SPCMEM+>20 | ; | | Length | 32 | bytes
SBLOC3 | EQU | SPCMEM+>40 | ; | | Length | 128 | bytes | | -> FREE FOR OWN USE
SBLOC4 | EQU | SPCMEM+>C0 | ; | | Length | 32 | bytes | \ | -> SBLOC4 can extend
SBLOC5 | EQU | SPCMEM+>D0 | ; | / Length | 32 | bytes | / | to 64 bytes
*//////////////////////////////////////////////////////////////
* | BLOCK 1
*//////////////////////////////////////////////////////////////
WSSPC1 | EQU | SPCMEM | ; | 32: SPECTRA workspace 1
*//////////////////////////////////////////////////////////////
* | BLOCK 2
*//////////////////////////////////////////////////////////////
VIRTKB | EQU | SBLOC2 | ; | 2: Virtual keyboard
VDPREG | EQU | SBLOC2+2 | ; | 16: VDP shadow registers
VDPSTA | EQU | SBLOC2+18 | ; | 2: VDP shadow status register
VDPCOL | EQU | SBLOC2+20 | ; | 2: VDP screen columns
TCOUNT | EQU | SBLOC2+22 | ; | 2: Timer Tick counter
THIGH | EQU | SBLOC2+24 | ; | 2: Timer highest slot in use
OUTP0 | EQU | SBLOC2+26 | ; | 2: Return parameter 0
FUTU1 | EQU | SBLOC2+28 | ; | 2: RESERVED FOR FUTURE USE
FUTU2 | EQU | SBLOC2+30 | ; | 2: RESERVED FOR FUTURE USE
*//////////////////////////////////////////////////////////////
* | BLOCK 3
*//////////////////////////////////////////////////////////////
FREE | EQU | SBLOC3 | ; | 128: Free for own use
*//////////////////////////////////////////////////////////////
* | | | BLOCK 4 - 5
*//////////////////////////////////////////////////////////////
STKBUF | EQU | SBLOC4 | ; | 32: Stack (extends to 64!)
WSSPC2 | EQU | SBLOC5 | ; | 32: SPECTRA workspace 2

### Variables in block 2

Please keep in mind that the SPECTRA memory layout is subject to change in future versions. This particularly applies to the variables used in block 2 (SBLOC2).

EQUATE | SIZE (bytes) | Description / Used by …
VIRTKB | 2 | Virtual keyboard controller - Virtual keyboard status spectra_ctrl_keyb.a99
VDPREG | 16 | VDP shadow registers (VDP#R0-R7) spectra_vdp.a99, spectra_tiles.a99, spectra_sprites.a99
VDPSTA | 2 | VDP shadow status register spectra_vdp.a99, spectra_tiles.a99, spectra_sprites.a99
VDPCOL | 2 | Number of columns in a row spectra_vdp.a99, spectra_tiles.a99, spectra_sprites.a99
TCOUNT | 2 | Timer Manager - Internal tick counter spectra_timers.a99
THIGH | 2 | Timer Manager - Highest timer slot in use spectra_timers.a99
OUTP0 | 2 | Subroutine output parameter 0
FUTU1 | 2 | RESERVED FOR FUTURE USE
FUTU2 | 2 | RESERVED FOR FUTURE USE

## BASE

## POPRG(0-9)

### Pop registers & return to caller

Main Category: | RAM
File | spectra_base.a99
Keywords | RAM, LOW-LEVEL
Call format | MYTEST B @POPRG2
Input | -
Output | -
Stack usage | -

Description:

These routines pop the specified registers from the stack and then returns to the caller. It expects that the return address (R11) is at the bottom.

Note that –by default- STACK is an equate for R8.
See the “what I need to know – Stack” section for details on stack usage.

Example:

Suppose you have a subroutine MYTEST defined that changes R0-R2 and you want to make sure that when you call MYTEST upon return R0-R2 have their original values again.

MAIN | LI | R0,15
LI | R1,22
LI | R2,8
BL | @MYTEST | ; Upon return R0=15, R1=22 and R2=8
JMP | $ | ; Soft halt
MYTEST | INCT | STACK
MOV | R11,*STACK+ | ; Push R11 (return address)
MOV | R0,*STACK+ | ; Push R0
MOV | R1,*STACK+ | ; Push R1
MOV | R2,*STACK | ; Push R2
LI | R0,99
MOV | @MYVAR,R1
CLR | R2
B | @POPRG2 | ; Pop R2,R1,R0,R11 from stack and return
Remarks:

You don’t want to do this if you are changing too many registers. In that case a LWPI will be more effective.

## BASE

## POPRX(0-9)

### Pop registers & return to caller (R11 already set)

Main Category: | RAM
File | spectra_base.a99
Keywords | RAM, LOW-LEVEL
Call format | MYTEST B @POPRX2
Input | -
Output | -
Stack Usage | -

Description:

These routines are similar to the POPRG(0-9) subroutines in that they pop the specified registers from the stack and then returns to the caller.
This version expects that R11 is already set in the subroutine itself.
This is useful if passing parameters to the subroutine via DATA statements

Note that –by default- STACK is an equate for R8.
See the “what I need to know – Stack” section for details on stack usage.

Example:

Suppose you have a subroutine MYTEST defined that changes R0-R2 and you want to make sure that when you call MYTEST upon return R0-R2 have their original values again.

MAIN | LI | R0,15
LI | R1,22
LI | R2,8
BL | @MYTEST
DATA | 4711 | ; Upon return R0=15, R1=22 and R2=8
JMP | $ | ; Soft halt
MYTEST | INCT | STACK
MOV | R0,*STACK+ | ; Push R0
MOV | R1,*STACK+ | ; Push R1
MOV | R2,*STACK | ; Push R2
MOV | *R11+,R0 | ; Get 4711 from caller and put in R0
MOV | @MYVAR,R1
CLR | R2
B | @POPRX2 | ; Pop R2,R1,R0 from stack and return

Remarks:

You don’t want to do this if you are changing too many registers. In that case a LWPI will be more effective.

# Memory / Copy

## MEMORY/COPY

## FILMEM

### Fill RAM memory range with byte

Main Category: | RAM
File | spectra_memcpy.a99
Keywords | RAM, LOW-LEVEL, data-variant
Call format | MYTEST BL @FILMEM DATA P0,P1,P2
Input | P0 = Memory start address P1 = Memory end address P2 = LSB must contain byte to fill
Output | -
Stack Usage | 6 bytes (R0,R1,R2)

Description:

This routine is used to fill a memory range with the specified byte.

Example:

Fill memory >6000 until >7FFF with value >FF

MAIN | BL | @FILMEM
DATA | >6000,>7FFF,>00FF
JMP | $ | ; Soft halt

Remarks:

## MEMORY/COPY

## FILMEX

### Fill RAM memory range with byte (register variant)

Main Category: | RAM
File | spectra_memcpy.a99
Keywords | RAM, LOW-LEVEL, register-variant
Call format | MYTEST BL @FILMEM
Input | R0 = Memory start address R1 = Memory end address R2 = LSB must contain byte to fill
Output | -
Stack Usage

Description:

This routine is used to fill a memory range with the specified byte. Parameters are passed via registers.

Example:

Fill memory >6000 until >7FFF with value >FF

MAIN | LI | R0,>6000 | ; Start
| LI | R1,>7FFF | ; End
| LI | R2,>00FF
| BL | @FILMEM
| JMP | $ | ; Soft halt

Remarks:

NOT YET IMPLEMENTED

## MEMORY/COPY

## CPYM

### Copy ROM/RAM memory range

Main Category: | RAM
File | spectra_memcpy.a99
Keywords | RAM, LOW-LEVEL, data-variant
Call format | MYTEST BL @CPYM DATA P0,P1,P2
Input | P0 = Memory source address P1 = Memory target address P2 = Number of bytes to copy
Output | -
Stack Usage | 6 bytes (R0,R1,R2)

Description:

This routine is used to copy a ROM/RAM memory range to RAM. Parameters are passed via registers.

Example:

Copy 500 bytes from high-memory >A000 to low-memory >8000

MAIN | BL | @CPYM
DATA | >A000,>8000,500
JMP | $ | ; Soft halt
Remarks:

## MEMORY/COPY

## CPYMX

### Copy ROM/RAM memory range (register variant)

Main Category: | RAM
File | spectra_memcpy.a99
Keywords | RAM, LOW-LEVEL, register-variant
Call format | MYTEST BL @CPYMX
Input | R0 = Memory source address R1 = Memory target address R2 = Number of bytes to copy
Output | -
Stack Usage | 8 bytes (R0,R1,R2,R11)

Description:

This routine is used to copy a ROM/RAM memory range to RAM. Parameters are passed via registers.

Example:

Copy 500 bytes from high-memory >A000 to low-memory >8000

MAIN | LI | R0,>A000 | ; Start RAM
| LI | R1,>8000 | ; Start VDP RAM
| LI | R2,500
| BL | @CPYM
| JMP | $ | ; Soft halt

Remarks:

## MEMORY/COPY

## G2VDP

### Copy GROM memory range to VDP memory

Main Category: | GROM
File | spectra_memcpy.a99
Keywords | GROM, VDP, LOW-LEVEL, data-variant
Call format | MYTEST BL @G2VDP DATA P0,P1,P2
Input | P0 = GROM source address P1 = VDP target address P2 = Number of bytes to copy
Output | -
Stack Usage | 6 bytes (R0,R1,R2)

Description:

This routine is used to copy a memory range from GROM memory directly into VDP memory.

Example:

Copy 300 bytes from GROM >0200 to VDP >0000

MAIN | BL | @G2VDP
DATA | >0200,>0000,300
JMP | $ | ; Soft halt

Remarks:

This subroutine overwrites the current GROM address.

## MEMORY/COPY

## G2VDPX

### Copy GROM memory range to VDP memory (register variant)

Main Category: | GROM
File | spectra_memcpy.a99
Keywords | GROM, VDP, LOW-LEVEL, register-variant
Call format | MYTEST BL @G2VDPX
Input | R0 = GROM source address R1 = VDP target address R2 = Number of bytes to copy
Output | -
Stack usage | 6 bytes (R0,R1,R2)

Description:

This routine is used to copy a memory range from GROM memory directly into VDP memory. Parameters are passed via registers

Example:

Copy 300 bytes from GROM >0200 to VDP >0000

MAIN | LI | R0,>0200 | ; GROM start
| CLR | R1 | ; VDP start
| LI | R2,300
| BL | @G2VDPX
| JMP | $ | ; Soft halt

Remarks:

This subroutine overwrites the current GROM address.

## MEMORY/COPY

## G2MEM

### Copy GROM memory range to RAM memory

Main Category: | GROM
File | spectra_memcpy.a99
Keywords | GROM, RAM, LOW-LEVEL, data-variant
Call format | MYTEST BL @G2MEM DATA P0,P1,P2
Input | P0 = GROM source address P1 = RAM target address P2 = Number of bytes to copy
Output | -
Stack usage | 6 bytes (R0,R1,R2)

Description:

This routine is used to copy a memory range from GROM memory to RAM memory.

Example:

Copy 300 bytes from GROM >0200 to RAM >6000

MAIN | BL | @G2MEM
DATA | >0200,>6000,300
JMP | $ | ; Soft halt

Remarks:

This subroutine overwrites the current GROM address.

## MEMORY/COPY

## G2MEMX

### Copy GROM memory range to RAM memory (register variant)

Main Category: | GROM
File | spectra_memcpy.a99
Keywords | GROM, RAM, LOW-LEVEL, register-variant
Call format | MYTEST BL @G2MEMX
Input | R0 = GROM source address R1 = RAM target address R2 = Number of bytes to copy
Output | -
Stack usage | 6 bytes (R0,R1,R2)

Description:

This routine is used to copy a memory range from GROM memory to RAM memory. Parameters are passed via registers.

Example:

Copy 300 bytes from GROM >0200 to RAM >6000

MAIN | LI | R0,>0200 | ; GROM start
| LI | R1,>6000 | ; RAM start
| LI | R2,300
| BL | @G2MEMX
| JMP | $ | ; Soft halt

Remarks:

This subroutine overwrites the current GROM address.

# VDP low-level

## VDP LOW-LEVEL

## FVRAM

### Fill VDP memory with byte

Main Category: | VDP
File | spectra_vdp.a99
Keywords | VDP, LOW-LEVEL, data-variant
Call format | MYTEST BL @FVRAM DATA P0,P1,P2
Input | P0 = VDP start address P1 = Byte to fill P2 = Number of bytes to fill
Output | -
Stack usage | 8 bytes (R0,R1,R2,R11)

Description:

This routine fill the specified VDP range with the specified byte

Example:

Fill memory range VDP >0000 - >0300 with ASCII character 32.
This example clears the screen assuming that (VDP#2 PNT pointer is set to >00) and graphics mode 1 is active.
MAIN | BL | @FVRAM
DATA | >0000,>20,768
JMP | $ | ; Soft halt
Remarks:

## VDP LOW-LEVEL

## FVRAMX

### Fill VDP memory with byte (register variant)

Main Category: | VDP
File | spectra_vdp.a99
Keywords | VDP, LOW-LEVEL, register-variant
Call format | MYTEST BL @FVRAMX
Input | R0 = VDP start address R1 = Byte to fill R2 = Number of bytes to fill
Output | -
Stack usage | 8 bytes (R0,R1,R2,R11)

Description:

This routine fill the specified VDP range with the specified byte Parameters are passed via registers.

Example:

Fill memory range VDP >0000 - >0300 with ASCII character 32.
This example clears the screen assuming that VDP#2 PNT register is set to >00 and graphics mode 1 is active.
MAIN | CLR | R0 | ; VDP start
| LI | R1,>20 | ; ASCII character 32
| LI | R2,768 | ; Bytes to fill
| BL | @FVRAMX
| JMP | $ | ; Soft halt
Remarks:

## VDP LOW-LEVEL

## PVRAM

### Copy memory range to VDP memory

Main Category: | VDP
File | spectra_vdp.a99
Keywords | RAM, VDP, LOW-LEVEL, data-variant
Call format | MYTEST BL @PVRAM DATA P0,P1,P2
Input | P0 = VDP start address P1 = RAM/ROM start address P2 = Number of bytes to copy
Output | -
Stack usage | 6 bytes (R0,R1,R2)

Description:

This routine copies the specified memory range (RAM or ROM) to VDP memory. Same functionality as the VMBW command.

Example:

Copy 15 sprites (16x16 size) from RAM address with label FGHT1 to VDP >0400
This example assumes that VDP#6 SPT (Sprite Pattern Table) register is set to >80 and graphics mode 1 is active.
MAIN | BL | @PVRAM
DATA | >0400,FGHT1,15 * 32
JMP | $ | ; Soft halt
Remarks:
There is no PVRAMX routine. You have to use VMBW for this.

## VDP LOW-LEVEL

## VSBR

### Read single byte from VDP

Main Category: | VDP
File | spectra_vdp.a99
Keywords | RAM, VDP, LOW-LEVEL, register-variant
Call format | MYTEST BL @VSBR
Input | R0 = VDP source address
Output | R1 = MSB, the byte read from VDP
Stack usage | -

Description:

This routine reads a single byte from VDP memory and stores it in the Most-Significant Byte of register R1.

Parameters are passed via registers.

Example:

The below example reads the character displayed on row 0 column 0 from VDP screen table assuming that VDP#2 PNT (Pattern Name Table) register is set to >00
After the routine is executed the Most-Significant Byte of register R1 contains the character value.
MAIN | CLR | R0
BL | @VSBR | ; Upon return MSB of R1 contains character value
JMP | $ | ; Soft halt

Remarks:

Same functionality as in the Editor Assembler module.

## VDP LOW-LEVEL

## VSBW

### Write single byte to VDP

Main Category: | VDP
File | spectra_vdp.a99
Keywords | RAM, VDP, LOW-LEVEL, register-variant
Call format | MYTEST BL @VSBW
Input | R0 = VDP target address R1 = MSB, the byte to write to VDP
Output | -
Stack usage | 4 bytes (R0,R11)

Description:

This routine writes a single byte to VDP memory.
The byte to write must be set as Most-Significant Byte of register R1.

Parameters are passed via registers.

Example:

The below example writes the character A (>41) to row 0 column 0 in VDP screen table assuming that VDP#2 PNT (Pattern Name Table) register is set to >00

MAIN | CLR | R0 | ; VDP start
| LI | R1,>4100 | ; Hex value >41 (=ASCII 65) in MSB
| BL | @VSBW
| JMP | $ | ; Soft halt

Remarks:

Same functionality as in the Editor Assembler module.

## VDP LOW-LEVEL

## VMBR

### Read multiple bytes from VDP

Main Category: | VDP
File | spectra_vdp.a99
Keywords | RAM, VDP, LOW-LEVEL, register-variant
Call format | MYTEST BL @VMBR
Input | R0 = VDP source address R1 = RAM target address R2 = Number of bytes to read
Output | -
Stack usage | 8 bytes (R0,R1,R2,R11)

Description:

This routine reads the specified amount of bytes from VDP memory into RAM memory

Parameters are passed via registers.

Example:

The below example reads 10 characters from VDP screen table starting at row 0 column 0 assuming that VDP#2 PNT (Pattern Name Table) register is set to >00.
The bytes read will be stored in RAM memory in the memory buffer labelled MYBUFF.
MAIN | CLR | R0 | ; VDP start
| LI | R1,MYBUFF | ; buffer in RAM
| LI | R2,10 | ; amount of bytes to read
| BL | @VMBR
| JMP | $ | ; Soft halt
MYBUFF | BSS | 10 | ; Buffer in RAM for storing 10 chars
Remarks:

Same functionality as in the Editor Assembler module.

## VDP LOW-LEVEL

## VMBW

### Write multiple bytes to VDP

Main Category: | VDP
File | spectra_vdp.a99
Keywords | RAM, VDP, LOW-LEVEL, register-variant
Call format | MYTEST BL @VMBW
Input | R0 = VDP target address R1 = RAM/ROM source address R2 = Number of bytes to write
Output | -
Stack usage | 8 bytes (R0,R1,R2,R11)

Description:

This routine writes the specified amount of bytes from RAM/ROM memory to VDP memory.

Parameters are passed via registers.

Example:

The below example writes 11 characters from RAM address with label MYTXT to VDP screen table starting at row 0 column 0 assuming that VDP#2 PNT (Pattern Name Table) register is set to >00.

MAIN | CLR | R0 | ; VDP start
| LI | R1,MYTXT | ; Text in RAM/ROM
| LI | R2,11 | ; Number of bytes to write
| BL | @VMBW
| JMP | $ | ; Soft halt
MYTXT | TEXT | “HELLO WORLD”

Remarks:

Same functionality as in the Editor Assembler module.

## VDP LOW-LEVEL

## VWTR

### Write to VDP register

Main Category: | VDP
File | spectra_vdp.a99
Keywords | RAM, VDP, LOW-LEVEL, register-variant
Call format | MYTEST BL @VWTR
Input | R0 = MSB is the VDP target register LSB is the value to write
Output | -
Stack usage | 4 bytes (R0,R11)

Description:

This routine writes the value in the least-significant byte of R0 to the VDP write-only register addressed by the most-significant byte of R0.

Parameters are passed via registers.

Example:

The below example sets the SPT (Sprite Pattern Table) pointer in VDP#6 to address >3000.

MAIN | LI | R0,>0606 | ; Note that >06 * >800 = >3000
| MOV | R0,@VDPR6 | ; Sync shadow register
| BL | @VWTR
| JMP | $ | ; Soft halt

Remarks:

Same functionality as in the Editor Assembler module.

The SPECTRA library knows the concept of VDP shadow registers in RAM.
If you use VWTR you need to make sure the shadow registers are up-to-date as well.

For details check out functions LVDPSH (Load VDP shadow registers) and WVDPSH (Write shadow registers to VDP).

## VDP LOW-LEVEL

## LVDPSH

### Load VDP shadow registers in RAM with video mode table

Main Category: | VDP
File | spectra_vdp.a99
Keywords | RAM, VDP, LOW-LEVEL, register-variant
Call format | MYTEST BL @LVDPSH
Input | R0 = Address of video mode table
Output | -
Stack usage | 8 bytes (R0,R1,R2,R11)

Description:

The SPECTRA library knows the concept of VDP shadow registers in RAM.
They are basically a copy of the write-only VDP registers.
This concept allows some more flexibility (e.g. read register value or set certain bits in the copy).

The LVDPSH subroutine is used to load all shadow registers (@VDPREG0-@VDPREG7) with the values of the specified video mode table.

Additionally it writes the amount of columns in a row (32, 40, 64) to the memory location @VDPCOL and clears the shadow status register (@VDPSTA).

Note that LVDPSH itself does not dump the registers to the VDP. You have to use the WVDPSH subroutine for that.

See section “APPENDIX – Overview video mode tables” for the default video mode tables provided with SPECTRA.

See section “BASE – What I need to know” for details about SPECTRA memory layout.

Example:

The below example sets up the VDP for dealing with graphics mode 1. The table VMODE1 is already provided as part of the SPECTRA library (spectra_vdp.a99) and is included in this example for reference purposes only.

MAIN | LI | R0,VMODE1 | ; "graphics mode 1"
| BL | @LVDPSH | ; Load shadow registers
| BL | @WVDPSH | ; Write shadow registers to VDP
| JMP | $ | ; Soft halt
VMODE1 | DATA | >0000,>01E2,>0200,>030E,>0401,>0506,>0680,>0700,32
***************************************************************
* VDP#0 Control bits
* | bit 6=0: M3 | Graphics 1 mode
* | bit 7=0: Disable external VDP input
* VDP#1 Control bits
* | bit 0=1: 16K selection
* | bit 1=1: Enable display
* | bit 2=1: Enable VDP interrupt
* | bit 3=0: M1 \ Graphics 1 mode
* | bit 4=0: M2 /
* | bit 5=0: reserved
* | bit 6=1: 16x16 sprites
* | bit 7=0: Sprite magnification (1x)
* VDP#2 PNT (Pattern name table) | at >0000 | (>00 * >400)
* VDP#3 PCT (Pattern color table) | at >0380 | (>0E * >040)
* VDP#4 PDT (Pattern descriptor table) at >0800 | (>01 * >800)
* VDP#5 SAT (sprite attribute list) | at >0300 | (>06 * >080)
* VDP#6 SPT (Sprite pattern table) | at >0400 | (>80 * >008)
* VDP#7 Set Background color to black
*
* 32 Columns in a row
***************************************************************

Remarks:

## VDP LOW-LEVEL

## WVDPSH

### Write VDP shadow registers from RAM to VDP write-only registers

Main Category: | VDP
File | spectra_vdp.a99
Keywords | RAM, VDP, LOW-LEVEL, register-variant
Call format | MYTEST BL @LVDPSH
Input | R0 = Address of video mode table
Output | -
Stack usage | 8 bytes (R0,R1,R2,R11)

Description:

The SPECTRA library knows the concept of VDP shadow registers in RAM.
They are basically a copy of the write-only VDP registers. This concept allows some more flexibility (e.g. read register value or set certain bits in the copy).

The WVDPSH subroutine itself is used to dump all shadow registers (@VDPREG0-@VDPREG7) to the VDP write-only registers after they have been loaded from a video mode table by the LVDPSH subroutine.

See section “APPENDIX – Overview video mode tables” for the default video mode tables provided with SPECTRA.

See section “BASE – What I need to know” for details about SPECTRA memory layout.

Example:

The below example sets up the VDP for dealing with graphics mode 1. The table VMODE1 is provided as part of the SPECTRA library.

MAIN | LI | R0,VMODE1 | ; "graphics mode 1"
| BL | @LVDPSH | ; Load shadow registers
| BL | @WVDPSH | ; Write shadow registers to VDP
| JMP | $ | ; Soft halt
VMODE1 | DATA | >0000,>01E2,>0200,>030E,>0401,>0506,>0680,>0700,32

Remarks:

## VDP LOW-LEVEL

## VDPADR

### Calculate VDP table start address

Main Category: | VDP
File | spectra_vdp.a99
Keywords | RAM, VDP, LOW-LEVEL, register-variant
Call format | MYTEST BL @VDPADR DATA P0
Input | P0 = Table identifier
Output | @OUTP0 = VDP address of table
Stack usage | 10 bytes (R0,R1,R2,R3,R11)

Description:

This subroutine calculates the start address of the specified table based on the value stored in the corresponding VDP shadow register and returns it in the memory location OUTP0.

Please refer to subroutines LVDPSH and WVDPSH for details about what shadow registers are.

Below are the valid values (equates) available for input register R0:

GETPNT | (Pattern name table)
GETPCT | (Pattern color table)
GETPDT | (Pattern descriptor table)
GETSAT | (Sprite attribute table)
GETSPT | (Sprite pattern table)

Example:

The below example determines the start address of the Pattern descriptor table and then copies 10 character patterns to that table, starting with character 0

MAIN | BL | @VDPADR | ; Get start address of Pattern descriptor table
DATA | GETPDT | ; Result is in @OUTP0
MOV | @OUTP0,R0
LI | R1,DIGITS
LI | R2,10*8 | ; For displaying score
BL | @VMBW
JMP | $ | ; Soft halt
DIGITS | BYTE | >00,>1C,>22,>63,>63,>63,>22,>1C | ; 0
BYTE | >00,>18,>38,>18,>18,>18,>18,>7E | ; 1

Remarks:

## VDP LOW-LEVEL

## VIDOFF

### Disable screen display

Main Category: | VDP
File | spectra_vdp.a99
Keywords | RAM, VDP, LOW-LEVEL, register-variant
Call format | MYTEST BL @VIDOFF
Input | -
Output | -
Stack usage | -

Description:

This subroutine sets bit 1 in VDP shadow register #1 to 0 which means that the VDP stops displaying the screen image and opens a permanent window (interval) for CPU access.

Note that VIDOFF only sets the VDP shadow register, you still need to write it to the VDP using the WVDPSH subroutine or a similar command.

You normally use this command at the start of a game if a new screen is to be displayed once it is completely built.

Example:

The below example loads video mode1, disables the screen display and writes the shadow registers to VDP. Then you have a permanent window for accessing VDP memory. Finally the screen display is enabled again by VIDON and with writing all shadow registers to the VDP.

MAIN | LI | R0,VMODE1 | ; "graphics mode 1"
| BL | @LVDPSH | ; Load shadow registers
| BL | @VIDOFF | ; Disable screen display
| BL | @WVDPSH | ; Write shadow registers to VDP
| .... | | ; Your VDP commands here
| BL | @VIDON | ; Enable screen display
| BL | @WVDPSH | ; Write shadow registers to VDP
| JMP | $ | ; Soft halt

Remarks:

In performance crucial code, you can achieve the same by doing an inline:

SZCB @BIT1,@VDPR1 ; bit 1=0 (Disable screen display)

## VDP LOW-LEVEL

## VIDON

### Enable screen display

Main Category: | VDP
File | spectra_vdp.a99
Keywords | RAM, VDP, LOW-LEVEL, register-variant
Call format | MYTEST BL @VIDON
Input | -
Output | -
Stack usage | -

Description:

This subroutine sets bit 1 in VDP shadow register #1 to 1 which means that the VDP starts displaying the screen image again. This closes the permanent window (interval) that was available for CPU access (see VIDOF subroutine)

Note that VIDON only sets the VDP shadow register, you still need to write it to the VDP using the WVDPSH subroutine or a similar command.

You normally use this command at the start of a game if a new screen is to be displayed once it is completely built.

Example:

The below example loads video mode1, disables the screen display and writes shadow registers to VDP. Then you have an unlimited window for doing all your VDP stuff . Finally the screen display is enabled again by VIDON and with writing all shadow registers to the VDP.

MAIN | LI | R0,VMODE1 | ; "graphics mode 1"
| BL | @LVDPSH | ; Load shadow registers
| BL | @VIDOFF | ; Disable screen display
| BL | @WVDPSH | ; Write shadow registers to VDP
| .... | | ; Your VDP commands here
| BL | @VIDON | ; Enable screen display
| BL | @WVDPSH | ; Write shadow registers to VDP
| JMP | $ | ; Soft halt

Remarks:

In performance crucial code, you can achieve the same by doing an inline:

SOCB @BIT1,@VDPR1 ; bit 1=1 (Enable screen display)

## VDP LOW-LEVEL

## XY2OF

### Calculate screen offset of X/Y character position

Main Category: | VDP
File | spectra_vdp.a99
Keywords | RAM, VDP, LOW-LEVEL, register-variant
Call format | MYTEST BL @XY2OF
Input | R0 = X Column (0-31, 0-39 for text-mode) R1 = Y row (0-23) or R0 = MSB X Column (0-31, 0-39 for text-mode) LSB Y row (0-23)
Output | @OUTP0 = Calculated screen offset
Stack usage | 10 bytes (R0,R1,R2,R3,R11)

Description:

This subroutine calculates the VDP screen offset based on the provided XY coordinates by using the formula offset = (ROWS * @VDPCOL + COL)

Note that the memory location @VDPCOL holds the numbers of columns in a row and is normally set by the @LVDPSH subroutine.

Be aware that you must add the PNT base address to the offset yourself to get the proper VDP target address.

Example:

The below example puts the text ‘HELLO WORLD’ at row 4, column 11 assuming that the Pattern Name Table (PNT) is located at address >0000.

MAIN | LI | R0,>0A03 | ; X=11 Y=4
| BL | @XY2OF | ; Result is in @OUTP0
| MOV | @OUTP0,R0
| LI | R1,HELLO
| LI | R2,11 | ; Text length
| BL | @VMBW
| JMP | $ | ; Soft halt
HELLO | TEXT | ‘HELLO WORLD’

Remarks:

# VDP Sprites

## VDP SPRITES – MEMORY SETUP

### What I need to know

Below you find some information that may be helpful when using sprites in SPECTRA.

### Copy of Sprite Attribute Table in RAM (Shadow SAT)

Before using the SPECTRA sprite functionality, you need to allocate 128 bytes of RAM. This is required for maintaining a work copy of the Sprite Attribute Table (SAT). Basically it allows you to easily do sprite manipulation in memory and then dump the SAT to the VDP with a single call (PUTSAT).

Label | RAMSAT
Size | 128 bytes
Remarks | Allocate in scratch-pad for optimal speed

For most sprite handling subroutines you can specify the address of the shadow SAT. For easy sprite manipulation it is advised to define the shadow SAT with the label RAMSAT. It will allow you to use the pre-defined sprite equates (See reference table).

It is advised to store the shadow SAT in scratch-pad RAM for getting optimal speed.

Example 1:

In the main program you define that SPECTRA will be using 128 bytes of scratch-pad memory for maintaining a work copy of the Sprite Attribute Table.

RAMSAT | EQU | >8340 | ; 128 bytes in scratch-pad RAM

Example 2:

If scratch-pad memory is not available for use, you would need to allocate it in normal memory, e.g. high-memory

RAMSAT | BSS | 128 | ; 128 bytes in RAM

Remarks:

SPECTRA has a set of equates (SPR1-SPR32) that allows easy sprite manipulation in memory.

SPR1 | EQU | RAMSAT | ; Sprite 1
SPR2 | EQU | RAMSAT+4 | ; Sprite 2
SPR3 | EQU | RAMSAT+8 | ; Sprite 3
SPR4 | EQU | RAMSAT+12 | ; Sprite 4
SPR5 | EQU | RAMSAT+16 | ; Sprite 5
SPR6 | EQU | RAMSAT+20 | ; Sprite 6
SPR7 | EQU | RAMSAT+24 | ; Sprite 7
SPR8 | EQU | RAMSAT+28 | ; Sprite 8
……
SPR29 | EQU | RAMSAT+112 | ; Sprite 29
SPR30 | EQU | RAMSAT+116 | ; Sprite 30
SPR31 | EQU | RAMSAT+120 | ; Sprite 31
SPR32 | EQU | RAMSAT+124 | ; Sprite 32

Format of Sprite Attribute Table Entry:

BYTE 0 | BYTE 1 | BYTE 2 | BYTE 3
Vertical position | Horizontal position | Sprite name pointer | Color & Early clock flag

## VDP SPRITES

## PUTSAT

### Write shadow SAT (Sprite Attribute Table) from RAM to VDP memory

Main Category: | VDP
File | spectra_sprites.a99
Keywords | RAM, VDP, LOW-LEVEL, SPRITE, register-variant
Call format | MYTEST BL @PUTSAT
Input | R0=VDP target address or >FFFF if address must be calculated R1=Address of shadow SAT in RAM/ROM R2=Address of sprite order table in RAM/ROM or >FFFF for default 0..31 order
Output | -
Stack usage | 8 bytes (R0,R1,R2,R11)

Description:

For increased speed and more easy sprite manipulation, SPECTRA can use one or more shadow SAT tables in memory. The goal is to minimize the amount of read & writes from/to the VDP by first doing the appropriate manipulation in memory and then doing a block write to VDP.

You have to set R0 with the SAT address in VDP or you let the system calculate the address by setting R0 to >FFFF. In that case the VDP SAT address is automatically calculated, based on the value in VDP shadow register VDPR5.

SPECTRA expects you to define a shadow SAT (128 bytes) in RAM. It is advised that this memory gets the label RAMSAT. So normally you would do a “LI R1,RAMSAT” first.

If R2 is set to >FFFF then the SAT will be written using the default sprite order 0..31
If you want to use a rotating custom sprite order table (32 bytes), e.g. for avoiding invisible 5th sprite, you can do so by setting R2 to the address of that table.

Example:

The next example, assumes that you have a game cartridge with a SAT dumped in ROM at address >6200. The example basically does the following steps:

| Setup graphics mode 1
| Load shadow SAT in RAM from SAT stored in a game ROM.
| Put sprite 5 at Y=100,X=30
| Dump shadow SAT to VDP using the default sprite order 0..31

RAMSAT | BSS | 128
MAIN | LI | R0,VMODE1 | ; "graphics mode 1"
| BL | @LVDPSH | ; Load shadow registers
| BL | @WVDPSH | ; Dump it to the VDP
| BL | @CPYM
| DATA | >6200,RAMSAT,32*4 | ; Put sprites from ROM in shadow SAT
| LI | R0,>641E
| MOV | R0,@SPR5 | ; Set Y=100, X=30
| SETO | R0 | ; Let SPECTRA calculate VDP SAT address
| LI | R1,RAMSAT
| SETO | R1 | ; >FFFF - No sprite order table
| BL | @PUTSAT
| JMP | $ | ; Soft halt
Remarks:

There is no custom sprite order table provided with SPECTRA. You have to set it up yourself.

## VDP SPRITES

## SPRORD

### Initialize sprite order table to default sprite order 0..31

Main Category: | VDP
File | spectra_sprites.a99
Keywords | RAM, VDP, SPRITE, register-variant
Call format | MYTEST BL @SPRORD
Input | R0=Address of sprite order table in RAM
Output | -
Stack usage | 8 bytes (R0,R1,R2,R11)

Description:

When writing the shadow SAT to VDP memory using the PUTSAT subroutine one can set the order in which the entries are written. This allows you to for example have a rotating sprite list for avoiding an invisible 5th sprite, however this comes with the cost of “flickering”.

There is no sprite order table provided with SPECTRA, you have to set it up yourself (32 bytes).

The SPRORD subroutine fills the sprite order table with the values 0..31 which in other words is the default sprite order

Example:

The below example assumes that shadow SAT RAMSAT is already is setup and that it needs to be written to VDP with default sprite order 0..31, but this time with possibility of having rotating sprite order.

VDPSAT | EQU | >0300
MAIN | LI | R0,MYORDR
| BL | @SPRORD | ; Setup Sprite Order Table with values 0..31
| LI | R0,VDPSAT
| LI | R1,RAMSAT
| LI | R2,MYORDR | ; Custom Sprite Order Table
| BL | @PUTSAT
| JMP | $ | ; Soft halt
MYORDR | BSS | 32 | ; Custom sprite order

Remarks:

There is no custom sprite order table provided with SPECTRA. You have to set it up yourself .

## VDP SPRITES

S8X8

### Sprites with 8 x 8 pattern

Main Category: | VDP
File | spectra_sprites.a99
Keywords | RAM, VDP, SPRITE
Call format | MYTEST BL @S8X8
Input | -
Output | -
Stack usage | -

Description:

This subroutine resets bit 6 in VDP shadow register #1 to 0 which means that the sprite size is 8 x 8. In other words you need 8 bytes for defining a sprite pattern.

Note that S8X8 only set the VDP shadow register, you still need to write it to the VDP using the WVDPSH subroutine or a similar command.

Example:

The below example loads video mode1, set sprite size to 8x8 and sets all VDP read-only registers.

MAIN | LI | R0,VMODE1 | ; "graphics mode 1"
| BL | @LVDPSH | ; Load shadow registers
| BL | @8X8 | ; Set sprite size 8x8
| BL | @WVDPSH | ; Write shadow registers to VDP
| JMP | $ | ; Soft halt

Remarks:

In performance crucial code, you can achieve the same by doing an inline:

SZCB | @PLS2+1,@VDPR1 ; bit 6=0 (Sprite size 8x8)
| BL | @WVDPSH | ; Write shadow registers to VDP

## VDP SPRITES

S16X16

### Sprites with 16 x 16 pattern

Main Category: | VDP
File | spectra_sprites.a99
Keywords | RAM, VDP, SPRITE
Call format | MYTEST BL @S16X16
Input | -
Output | -
Stack usage | -

Description:

This subroutine sets bit 6 in VDP shadow register #1 to 1 which means that the sprite size is 16 x 16. In other words you need 32 bytes for defining a sprite pattern.

Note that S16X16 only sets the VDP shadow register, you still need to write it to the VDP using the WVDPSH subroutine or a similar command.

Example:

The below example loads video mode1, set sprite size to 16x16 and sets all VDP write-only registers.

MAIN | LI | R0,VMODE1 | ; "graphics mode 1"
| BL | @LVDPSH | ; Load shadow registers
| BL | @16X16 | ; Set sprite size 16X16
| BL | @WVDPSH | ; Write shadow registers to VDP
| JMP | $ | ; Soft halt

Remarks:

In performance crucial code, you can achieve the same by only dumping VDP shadow register 1 after doing an inline:

SOCB @PLS2+1,@VDPR1 ; bit 6=1 (Sprite size 16x16)

## VDP SPRITES

## SMAG1X

### Sprite magnification 1X

Main Category: | VDP
File | spectra_sprites.a99
Keywords | RAM, VDP, SPRITE
Call format | MYTEST BL @SMAG1X
Input | -
Output | -
Stack usage | -

Description:

This subroutine resets bit 7 in VDP shadow register #1 to 0 which means that the sprite magnification is 1. In other words sprites are not magnified..

Note that SMAG1X only sets the VDP shadow register, you still need to write it to the VDP using the WVDPSH subroutine or a similar command.

Example:

The below example loads video mode1, set sprite magnification to 1X and sets all VDP write-only registers.

MAIN | LI | R0,VMODE1 | ; "graphics mode 1"
| BL | @LVDPSH | ; Load shadow registers
| BL | @SMAG1X | ; Set sprite magnification 1X
| BL | @WVDPSH | ; Write shadow registers to VDP
| JMP | $ | ; Soft halt

Remarks:

In performance crucial code, you can achieve the same by only dumping VDP shadow register 1 after doing an inline:

SZCB @BIT7,@VDPR1 ; bit 7=0 (Sprite magnification 1x)

## VDP SPRITES

## SMAG2X

### Sprite magnification 2X

Main Category: | VDP
File | spectra_sprites.a99
Keywords | RAM, VDP, SPRITE
Call format | MYTEST BL @SMAG2X
Input | -
Output | -
Stack usage | -

Description:

This subroutine sets bit 7 in VDP shadow register #1 to 1 which means that the sprite magnification is 2x. In other words sprites are twice the size they would normally be

Note that SMAG2X only sets the VDP shadow register, you still need to write it to the VDP using the WVDPSH subroutine or a similar command.

Example:

The below example loads video mode1, set sprite magnification to 2X and sets all VDP write-only registers.

MAIN | LI | R0,VMODE1 | ; "graphics mode 1"
| BL | @LVDPSH | ; Load shadow registers
| BL | @SMAG2X | ; Set sprite magnification 2X
| BL | @WVDPSH | ; Write shadow registers to VDP
| JMP | $ | ; Soft halt

Remarks:

In performance crucial code, you can achieve the same by only dumping VDP shadow register 1 after doing an inline:

SOCB @BIT7,@VDPR1 ; bit 7=1 (Sprite magnification 2x)

## VDP SPRITES

## SPRITE

### Create new sprite

Main Category: | VDP
File | spectra_sprites.a99
Keywords | RAM, VDP, SPRITE
Call format | MYTEST BL @SPRITE
Input | R0=Pointer to sprite table entry in ROM/RAM ----------------------------------------------------------------------------------------------Format for sprite table entry: DATA P0,P1,P2,P3,P4 P0=VDP target address for entry in VDP SAT or shadow SAT P1=MSB is Y pixel position LSB is X pixel position P2=MSB is sprite character code LSB is sprite colour P3=ROM/RAM source address of sprite pattern data P4=Address of subroutine to call via BL @statement.
Output | -
Stack usage | ????

Description:

This subroutine is used to create a new sprite.

MSB (Most Significant Byte) of P1 is the Y pixel position LSB (Least Significant Byte) of P2 is the X pixel position

MSB of P2 is the sprite character code
LSB of P2 is the sprite colour.

P3 is a pointer to the memory location that holds the sprite pattern data.
Set P3 to >0000 (equate NULL) if no pattern data is to be defined.

You can set P4 with the address of the subroutine that initializes the control logic for this particular sprite. Normally this subroutine is then used to do things like variable initialisation, set sprite order & create a timer slot using (BL @MKSLOT) for handling the sprite animation (movement, etc.).
Set P4 to >0000 (equate NULL) if no setup subroutine needs to be called.

## VDP SPRITES

Example:

Assuming that location SCORP1 holds the pattern data for a scorpion, the below example will load the pattern data (character >A4) and put a white scorpion sprite on screen at Y position >A2 and X position >80. It then calls the subroutine MYSUB using (BL @MYSUB)

MAIN | LI | R0,ABC | ; Sprite table entry
| BL | @SPRITE | ; Put sprite on screen
| JMP | $ | ; Soft halt
MYSUB | CLR | @BLABLA | ; Do something
| RET | | ; Exit
ABC | DATA | VDPSAT+40,>A280,>A40F,SCORP1,MYSUB

Remarks:

# VDP Tiles & Patterns

## VDP TILES & PATTERNS

## FILLSCR

### Fill screen with character

Main Category: | VDP
File | spectra_tiles.a99
Keywords | RAM, VDP, TILES, PATTERNS
Call format | MYTEST BL @FILLSCR
Input | R0=Character to fill
Output | -
Stack usage | 8 bytes (R0,R1,R2,R11)

Description:

Fill the screen with the character specified in R0.

The subroutine uses the VDPADR subroutine to determine the address of the PNT table. Uses memory location @VDPCOL (columns in a row) which is set by the LVDPSH subroutine. In other words, it also works in text mode, etc.

Example:

Fill the screen with letter A.

MAIN | LI | R0,65 | ; ASCII of letter A
| BL | @FILLSCR | ; Fill screen
| JMP | $ | ; Soft halt
Remarks:

## VDP TILES & PATTERNS

## FIBOX

### Fill rectangular area with character

Main Category: | VDP
File | spectra_tiles.a99
Keywords | RAM, VDP, TILES, PATTERNS
Call format | MYTEST BL @FIBOX DATA P0,P1,P2,P3,P4
Input | P0 = Upper left corner X P1 = Upper left corner Y P2 = Width P3 = Height P4 = Character to fill
Output | -
Stack usage | 8 bytes (R0,R1,R2,R11)

Description:

Fill the rectangular screen area (box) with the character specified in P4.

The subroutine uses the VDPADR subroutine to determine the address of the PNT table. Uses memory location @VDPCOL (columns in a row) which is set by the LVDPSH subroutine. In other words, it also works in text mode, etc.

A right screen-column boundary check is done to prevent that the box spans the right and left part of the screen.

Example:

Fill a box with the letter ‘A’. The box is 15 columns wide and 4 rows long and is positioned at row 8 column 10.

MAIN | BL | @FIBOX
DATA | 10,8,15,4,65 ; Fill box with letter A
JMP | $ | ; Soft-halt

Remarks:

## VDP TILES & PATTERNS

## FIBOXX

### Fill rectangular area with character (register variant)

Main Category: | VDP
File | spectra_tiles.a99
Keywords | RAM, VDP, TILES, PATTERNS
Call format | MYTEST BL @FIBOXX
Input | R0 = Upper left corner X R1 = Upper left corner Y R2 = Width R3 = Height R4 = Character to fill
Output | -
Stack usage | 8 bytes (R0,R1,R2,R11)

Description:

Fill the rectangular screen area (box) with the character specified in P4.
Parameters are passed via registers.

The subroutine uses the VDPADR subroutine to determine the address of the PNT table. Uses memory location @VDPCOL (columns in a row) which is set by the LVDPSH subroutine. In other words, it also works in text mode, etc.

A right screen-column boundary check is done to prevent that the box spans the right and left part of the screen.

Example:

Fill a box with the letter ‘A’. The box is 15 columns wide and 4 rows long and is positioned at row 8 column 10.

MAIN | LI | R0,10 | ; left corner X
| LI | R1,8 | ; left corner Y
| LI | R2,15 | ; width
| LI | R3,4 | ; height
| LI | R4,65 | ; letter ‘A’
| BL | @FIBOXX | ; Fill box with letter A
| JMP | $ | ; Soft-halt

Remarks:

## VDP TILES & PATTERNS

## PUTTX

### Put length-byte prefixed string on screen

Main Category: | VDP
File | spectra_tiles.a99
Keywords | RAM, VDP, TILES, PATTERNS
Call format | MYTEST BL @PUTTX DATA P0,P1,P2 ----------------------------------------------------------------------------------------------MYTEST BL @PUTTX DATA P0,P1
Input | P0 = X column (0-31, 0-39, ...) P1 = Y column (0-23) P2 = Pointer to string ----------------------------------------------------------------------------------------------P0 = MSB (X column 0-31, 0-39, ...) LSB (Y column 0-23) P1 = Pointer to string
Output | -
Stack usage | 8 bytes (R0,R1,R2,R3)

Description:

Display string specified in P2 on screen at column P0 and row P1.
Display string specified in P1 on screen at column (HI-byte P0) and row (LO-byte P0).

The first byte of the string to display must contain the string length.

The subroutine uses the VDPADR subroutine so it knows where the PNT table is in VDP memory. No need to add offset.

Example:

Assuming that the video mode table is already setup, this example displays the text HELLO WORLD on row 12, column 10.

MAIN | BL | @PUTTX
DATA | >0A0C,TXT1 ; X=10 Y=12
JMP | $ | ; Soft-halt
TXT1 | BYTE | 11
TEXT | ‘HELLO WORLD’
Remarks:

## VDP TILES & PATTERNS

## MIRRV

### Mirror tile/sprite patterns in RAM memory buffer around vertical axis

Main Category: | VDP
File | spectra_tiles.a99
Keywords | RAM, VDP, TILES, PATTERNS
Call format | MYTEST BL @MIRRV DATA P0,P1,P2
Input | P0 = Pointer to pattern data in RAM P1 = Number of bytes to mirror P2 = ‘SWAP’ or ‘NOSWAP’
Output | -
Stack usage | 16 bytes (R0,R1,R2,R3,R4,R5,R6,R7)

Description:

Mirror tile/sprite patterns in RAM around the vertical axis.

P0 is a pointer to the memory location in RAM that is holding the actual pattern data.

P1 is the number of bytes that need to be mirrored.

P2 should be set to the pre-defined equates SWAP or NOSWAP.
SWAP means that the pattern sequence 0123 will be swapped to 2301.
This is useful for mirroring sprites having 16 x 16 pattern.

Note that this subroutine overwrites the original patterns while mirroring.

Example:

Assuming that the video mode table is already setup, this example mirrors the sprite patterns of a 16x16 space ship (SHIP) around the vertical axis. In this example the space ship is made out of 3 overlapping sprites (one 16x16 sprite for each colour, 3 * 32 bytes = 96 bytes). Finally the sprite pattern data gets dumped to the VDP by the @PVRAM subroutine.

MAIN | BL | @CPYM
DATA | SHIP,RAMBUF,96 | ; Copy sprite patterns to RAM
BL | @MIRRV
DATA | RAMBUF,96,SWAP | ; Mirror patterns around vertical axis
BL | @PVRAM
DATA | >0400,RAMBUF,96 | ; Dump the pattern data to the VDP
JMP | $ | ; Soft-halt
RAMBUF | BSS | 96 | ; Work buffer
SHIP | BYTE | >00,>01,>01,>01,>01,>01,>00,>00 | ; RED
BYTE | >00,>00,>08,>19,>3D,>01,>01,>00
BYTE | >00,>00,>00,>80,>80,>80,>C0,>C0
BYTE | >40,>40,>F0,>B8,>8C,>80,>00,>00
.... | ; GREEN
.... | ; WHITE

# Sound & Speech

## SOUND & SPEECH

## EPSGMD

### Setup memory for playing EPSGMOD tune

Main Category: | SOUND
File | spectra_epsgmod.a99
Keywords | RAM, SOUND, EPSGMOD
Call format | MYTEST BL @EPSGMD
Input | R0 = Address of tune
Output | -
Stack usage | 8 bytes (R0,R1,R2,R11)

Description:

This subroutine is the interface to the built-in EPSGMOD player from Tursi (http://www.harmlesslion.com). The version included in SPECTRA is slightly modified so that the player runs as a task (PSGTCK) along with your game tasks. Other than that no modifications were done.

Note that the actual player requires 128 bytes of RAM which are allocated in spectra_epsgmod.a99

Basically the idea is that you create the tune using Kontechs Mod2PSG2 (http://mod2psg2.kontechs.de). Mod2PSG2 is a very powerful music tracker for the SN76489 sound chip that is used in the TI-99/4A, Colecovision, SEGA Master System, …
This windows software is NOT included in SPECTRA, but is available for free via the mentioned web link.

After exporting the tune from Mod2PSG2, you can use the included PERL conversion utility for generating the required BYTE source statements you then include in your source code. PERL itself is a well-known open source script programming language that you can download from http://www.perl.org

Don’t forget to start the PSGTCK controller that is responsible for playing the tune (see example for details).

Example:

The below example is taken from Time Pilot, my new homebrew game for the TI-99/4A. It assumes that the byte data with label SND1 was already exported from the MOD2PSG2 Tracker and converted using the little PERL conversion utility.

MAIN | ....
MOV | @PLS2,@THIGH ; Highest slot in use
BL | @MKSLOT
DATA | 0,2,KBSCAN | ; Controller 0 - Keyboard
BL | @MKSLOT
DATA | 1,1,PSGTCK | ; Controller 1 - Play PSG sound
LI | R0,TUNE
BL | @EPSGMD | ; Setup memory for playing tune
B | @TMGR | ; Start Task Scheduler
*************************************************************** * Game introduction tune
********@*****@************************************************ SND1 BYTE >0D,>00,>FF,>00,>08,>80,>00,>08,>80,>00,>08,>80 BYTE >00,>08,>80,>00,>FF,>80,>FF,>00,>08,>80,>00,>08 BYTE >FF,>80,>FF,>00,>08,>80,>00,>08,>80,>00,>08,>80 ...

Conversion utility:

You can use the below PERL script for converting the exported tune from the Mod2PSG2 tracker into assembly BYTE statements:

open (FH,"<","your_file.epsgmod") | || die("Couldn't open file!\n");
binmode(FH) | || die("Don't know but something went wrong\n");
my $cnt | = 0;
my $label = ' | BYTE ';
my $data | = '';
while (read(FH,$buf,2)) {
if ($cnt % 6 == 0) {
$data .= "\n$label";
} else {
$data .= ",";
}
my $val = sprintf("%04X", unpack("n",$buf)); $data .= ">" . substr($val,0,2) . ","; $data .= ">" . substr($val,2,2);
#printf ("%X",unpack("n",$buf));

$cnt++;
};
print "RUNSIZ EQU ", $cnt, "\n"; print "RUN $data\n";
close(FH);

Remarks:

See the license section for the conditions on using the EPSGMOD player in your game.
Also big thanks to Tursi and Kontechs for their permission on including the player.

Note that an optimized version of the EPSGMOD player and a decent conversion utility is planned for the next release of SPECTRA.

# Timers

## TIMERS

### What I need to know

Below you find some information that may be helpful when creating tasks in SPECTRA.

### Timer table

The timer table is used by the Timer Manager (TMGR) for executing subroutines at a specified interval. It is the game programmers’ responsibility to allocate the amount of required memory and to assign the label TIMER to it.

A timer table consists of 1 to X timer slots. See Timer slot format for further details. Make sure to set the SPECTRA memory location @THIGH to the number of the highest slot in use.

Label | TIMER
Size | Depends on amount of slots to use. 1 slot requires 8 bytes.
Remarks | THIGH must contain the number of the highest slot in use

Example:

Allocate 20 timer slots in your main program.

TIMER | BSS | 160 | ; Space for 20 timer slots
MAIN | LI | R0,19
| MOV | R0,@THIGH | ; Highest slot in use

### Timer slot format

A timer slot consists of 8 bytes (4 words) and the initial setup is normally done by using the MKSLOT subroutine. However manual manipulation is also easily possible and often useful when changing certain slot aspects on-the-fly.

BYTE 0-1 | BYTE 2-3 | BYTE 4-5 | BYTE 6-7
Interval (Target tick count) | Controller (address of routine to call) | Internal tick counter | Private area (available for personal use)
Interval | Determines at what interval the slot should be fired. This interval must be specified in ticks per second.
| On an American TI-99/4A console there are 60 ticks per second. On an European TI-99/4A console there are 50 ticks per second.

Controller | This is the address of the subroutine that will be called by the Timer Manager when the slot is fired. In SPECTRA such subroutine is called a “controller”. The Timer Manager calls the controller using the BL @xxx statement.
Internal counter | Is an internal counter used by the timer manager to keep track about when the slot should be fired. Do not modify.
Private Area | This area is available for personal use. You would normally use this area to store some flags related to your controller, as a pointer to a memory area you allocate, etc.

### Highest slot in use

The timer manager TMGR must know how many slots it needs to handle. Therefore the SPECTRA library has a memory location @THIGH that must contain the number of the highest slot in use.
See section “SPECTRA – memory layout” for the exact location of @THIGH.

Example:

Set highest slot in use to 4 (which is the 5th slot)

MAIN | LI | R0,4
| MOV | R0,@THIGH | ; Highest slot in use

### Equates for accessing timer slots

For doing easy slot manipulation SPECTRA delivers a set of equates in spectra_timers.a99 for accessing 20 timer slots:

TSLOTx | Byte 0-1 : Timer interval (byte 0-1) of specified slot
TSUBx | Byte 2-3 : Controller address of specified slot
TPRVx | Byte 6-7 : Private area of specified slot

* x=number between 0 and 19

Example:

Assuming you have a controller ZBLNK that runs in slot 10, the below example will use the private area of that slot to store a game counter, cycling from 0-3.

ZBLNK | INC | @TPRV10 | ; Increase counter (private variable slot 10)
C @TPRV10,@PLS3
| JNE | ZBLNKZ
| CLR | @TPRV10 | ; Reset counter (private variable slot 10)
ZBLNKZ | RET

## TIMERS

## MKSLOT

### Allocate specified timer slot

Main Category: | TIMERS
File | spectra_timers.a99
Keywords | RAM, TIMERS, ANIMATIONS
Call format | MYTEST BL @MKSLOT DATA P0,P1,P2
Input | P0 = Slot number P1 = Run slot every P1 ticks P2 = Controller (subroutine to call via BL @P2 when slot is fired)
Output | -
Stack usage | 8 bytes (R0,R1,R2,R11)

Description:

This subroutine is used for allocating the specified timer slot.

P0 is the slot number to use. The amount of available slots is determined by the size of the slot table in RAM memory. See section “Timer layout” and the timer manager subroutine TMGR for details.

P1 determines the interval at which the task scheduler should run the subroutine specified in parameter P2. The value for the interval is defined in ticks per second.

On an American TI-99/4A console there are 60 ticks per second. On an European TI-99/4A console there are 50 ticks per second.

P2 contains the address of the subroutine to call via BL @P2 when the slot is fired.
We call this type of subroutine a “controller”.

Note that the MKSLOT subroutine only allocates the timer, it does not process it.
Processing of all timer slots is done by the timer manager, so you have to make sure that it is running. See subroutine TMGR for details.

Example:

See TMGR – Timer Manager

Remarks:

Spectra already provides some basic controllers. See section “Default Controllers” for further details.

## TIMERS

## TMGR

### Timer Manager – the Spectra task scheduler

Main Category: | TIMERS
File | spectra_timers.a99
Keywords | RAM, TIMERS, ANIMATIONS
Call format | MAIN B @TMGR
Input | -
Output | -
Stack usage | 0 bytes

Description:

This subroutine is used for running the timer manager, the task scheduler that is provided with SPECTRA. It should be called after doing the program initialisation (setting up memory, allocating timer slots, etc).

TMGR acts as the main loop of your program and requires that VDP interrupts are disabled, so it first does a “LIMI 0”. The subroutine then basically synchronizes with the VDP by continuously checking the interrupt flag (BIT0) of the VDP status register.

If the flag is switched on (VDP memory access window open), the subroutine will first save a copy of the VDP status in the VDP status shadow register @VDPSTA and will then loop over all defined slots.
For each slot it first updates the internal counter TCOUNT, compares with the target interval defined in the slot and if it matches it calls the corresponding subroutine via BL @xxxx.

Make sure that you always properly initialize the TIMER table with >00 value. If you have junk in the table it can happen that the Timer Manager interprets it as a slot that needs to be fired and locks up.

You also need to set @THIGH to the highest slot currently in use.

See the MKSLOT subroutine for details on allocating a new timer slot.
See section “TIMERS – MEMORY SETUP” for details on the timer memory structure.

Be aware that an American TI-99/4A console (9918VDP) there are 60 ticks (interrupts) per second. On an European TI-99/4A console (9928VDP) there are 50 ticks (interrupts) per second.

Example:

The below example uses a controller to fill the screen with a character and sets the border colour. It starts with an interval of 1 second and then gets faster until it resets to an interval of 1 second again. Each time the controller is fired, it fills with the next character and next border colour.

********@*****@*********************@**************************
| IDT | 'TI'
| TITL | 'TEST1'
| DEF | SFIRST, SLAST, SLOAD
| AORG | >A000 | ; High-memory. Use >6000 for super-cart
SFIRST | EQU | $
SLOAD | EQU | $
TIMER | EQU | >8340 | ; Allocate timer table in scratchpad memory
***************************************************************
* Main program
********@*****@*********************@**************************
MAIN | LWPI | WSSPC1 | ; Load main workspace
| LIMI | 0
| LI | STACK,STKBUF | ; Setup simulated stack
| BL | @FILMEM
| DATA | >8320,>83FF,>00 | ; Clear scratchpad memory (except workspace)
*--------------------------------------------------------------
* VDP setup
*--------------------------------------------------------------
| LI | R0,VMODE1 | ; "graphics mode 1"
| BL | @LVDPSH | ; Load shadow registers
| LI | R0,>0700 | ; Background "black"
| MOV | R0,@VDPR7 | ; Put in shadow register 7
| BL | @VIDOFF | ; Disable screen updates
| BL | @WVDPSH | ; Write shadow registers to VDP
| LI | R0,32
| BL | @FILSCR | ; Clear screen
| BL | @VIDON | ; Enable screen updates again
| BL | @WVDPSH | ; Write shadow registers to VDP
*--------------------------------------------------------------
* Setup controller
*--------------------------------------------------------------
| CLR | @THIGH | ; Highest slot is 0
| BL | @MKSLOT
| DATA | 0,60,ZCYCLE
| MOV | @CHAR,@TPRV0 | ; Store in private area slot 0
| B | @TMGR | ; Start task scheduler

*--------------------------------------------------------------
* Controller: Cycle screen background *--------------------------------------------------------------
ZCYCLE | INCT | STACK
| MOV | R11,*STACK+
| MOV | R0,*STACK+
| MOV | R1,*STACK | ; Just push/pop some registers for testing
*--------------------------------------------------------------
* Fill screen with character *--------------------------------------------------------------
| INC | @TPRV0 | ; char = char + 1
| MOV | @TPRV0,R0
| CI | R0,143 | ; Character with ASC
| JLE | ZCYCLF
| MOV | @CHAR,@TPRV0 | ; Reset character in private area slot 0
ZCYCLF | BL | @FILSCR | ; Fill screen with character
*--------------------------------------------------------------
* Cycle screen background
*--------------------------------------------------------------
| MOV | @VDPR7,R0
| BL | @VWTR | ; Write shadow register
| INC | R0 | ; Increase color
| CI | R0,>070F | ; Last color reached ?
| JLE | ZCYCLG
| LI | R0,>0700 | ; Reset color
ZCYCLG | MOV | R0,@VDPR7 | ; Sync shadow register
| DECT | @TSLT0 | ; interval = interval - 2
| JNE | ZCYCLH
| LI | R0,60 | ; Reset interval
| MOV | R0,@TSLT0 | ; Update interval
ZCYCLH | B | @POPRG1
CHAR | DATA | 32 | ; White space - ASCII 32

# Default Controllers

## DEFAULT CONTROLLERS

## KBSCAN

### Scan the virtual TI-99/4A keyboard

Main Category: | TIMERS
File | spectra_ctrl_keyb.a99
Keywords | RAM, KEYBOARD, CONTROLLER
Call format | MYTEST BL @MKSLOT DATA P0,P1,KBSCAN
Input | P0 = Slot number P1 = Repeat interval
Output | @VIRTKB
Stack usage | 8 bytes (R11,R0,R1,R2)

Description:

This controller implements a simple virtual TI-99/4A game keyboard. It basically scans the keyboard and joystick 1 and maps the result as bit flags on a virtual keyboard mask.

The controller stores the resulting bit-flags in the memory word @VIRTKB.
See section SPECTRA memory layout for details on memory location.

Benefit is that your game controller does not specifically need to check both keyboard and joystick. If you for example press ‘S’ on the keyboard, it reacts the same as if you pull joystick 1 to the left. They will both set the bit for the virtual key ‘KLEFT’ in @VIRTKB to 1.

Note that this controller does not support all keys, but does handle enough for supporting an arcade game.
The controller itself also checks for FNCTN-QUIT and exits to the TI-99/4A title screen when pressed.

The controller needs a 6 byte memory buffer for storing the keyboard/joystick column results. Be default this is @RAMBUF

Example:

The below example starts the keyboard controller and a game controller that checks for up and down.

MAIN | ...
| BL | @MKSLOT
| DATA | 0,2,KBSCAN | ; Setup virtual-keyboard controller
| BL | @MKSLOT
| DATA | 1,2,GAME | ; Setup your game controller
| MOV | @PLS1,@THIGH | ; Highest slot is 1
| B | @TMGR | ; Start task scheduler
*--------------------------------------------------------------* Controller: Check game moves *--------------------------------------------------------------
GAME | INCT | STACK
| MOV | R0,*STACK
| MOV | @VIRTKB,R0 | ; Get virtual keyboard
| COC | KUP,R0 | ; ‘E’ pressed or joystick 1 moved up ?
| JNE | GAME1 | ; No, continue checking
| ... | | ; Yes, your stuff here
GAME1 | COC | @KDN,R0 | ; ‘X’ pressed or joystick 1 moved down ?
| B | @POPRG0 | ; Exit

### Overview @VIRTKB flags

Below are the bit flags currently used by the @VIRTKB memory word (see section “SPECTRA – memory layout” for RAM location of this word.

BIT | Description | Meaning
0 | Left | 0=no 1=yes
1 | Right | 0=no 1=yes
2 | Up | 0=no 1=yes
3 | Down | 0=no 1=yes
4 | Space / Fire / Q | 0=no 1=yes
5 | ALPHA LOCK down | 0=no 1=yes
6 | Pause | 0=no 1=yes
7 | -not used- | 0=no 1=yes
8 | REDO | 0=no 1=yes
9 | BACK | 0=no 1=yes
10 | QUIT | 0=no 1=yes
11 | -not used- | 0=no 1=yes
12 | -not used- | 0=no 1=yes
13 | -not-used- | 0=no 1=yes
14 | -not-used- | 0=no 1=yes
15 | -not-used- | 0=no 1=yes

### Equates for controller

Below is an overview of the equates that are delivered with the KBSCAN controller.
They can be used for doing bit comparison against @VIRTKB.
Equate | Virtual key | Real keyboard | Joystick 1 | BIT in @VIRTKB | Equate value
KLFT | left | S | Left | 0 | >8000
KRGT | Right | D | Right | 1 | >4000
KUP | Up | E | Up | 2 | >2000
KDN | Down | X | Down | 3 | >1000
KUPLFT | Up and left | E+S | Up and left | 2 and 0 | >A000
KUPRGHT | Up and right | E+D | Up and right | 2 and 1 | >6000
KDNLFT | Down and left | X+S | Down and left | 3 and 0 | >9000
KDNRGT | Down and right | X+D | Down and right | 3 and 1 | >5000
KFIRE | Fire | Q or space | Fire | 4 | >800
KALPHA | Alpha lock down | Alpha lock down | - | 5 | >400
KPAUSE | Pause | P | - | 6 | >200
KREDO | REDO | 8 | - | 8 | >80
KBACK | BACK | 9 | - | 9 | >40
KQUIT | Quit | FCTN + 0 | - | 10 | >20

### TI-99/4A keyboard 8x8 matrix

Below is an overview of the keyboard mapping that can be checked by reading the 6 byte memory buffer @RAMBUF.

### Keyboard 8x8 matrix: If 0 then key is down Keyboard 8x8 matrix: If 0 then key is down

COLUMN | 0 | 1 | 2 | 3 | 4 | 5 | 6 | 7
+---------------------------------+------+
ROW 7 | | | = | . | , | M | N | / | JS1 JS2 | Fire |
ROW 6 | | SPACE | L | K | J | H | ; | JS1 JS2 | Left |
ROW 5 | | ENTER | O | I | U | Y | P | JS1 JS2 | Right|
ROW 4 | | | 9 | 8 | 7 | 6 | 0 | JS1 JS2 | Down |
ROW 3 | | FCTN | 2 | 3 | 4 | 5 | 1 | JS1 JS2 | Up | |
ROW 2 | | SHIFT | S | D | F | G | A | +------|
ROW 1 | | CTRL | W | E | R | T | Q | |
ROW 0 | | | X | C | V | B | Z | |
+----------------------------------------+

See MG smart programmer 1986
September/Page 15 and November/Page 6

Remarks:

It is advised that the virtual keyboard runs as slot 0. You can then implement your game controller as slot 1 and all game animations as separate controllers starting slot 2.
To pause the game you would just check @VIRTKB for KPAUSE. If it is pressed you then do some preparation (e.g. mute sound chip), set @THIGH to slot 1 and all animations will stop.

See section “TIMERS – Memory setup” for details on @THIGH.

# Appendix

### Overview video mode tables

Below you find the list of default video mode tables provided in the file spectra_vdp.a99 See section “VDP LOW LEVEL” for details on shadow register usage

Mode | PNT VDP#2 | PCT VDP#3 | PDT VDP#4 | SAT VDP#5 | SPT VDP#6 | FG/BG VDP#7 | COL | Description
VMODE1 | >0000 | >0380 | >0800 | >0300 | >0400 | -/Black | 32 | Graphics mode 1
VMODET | >0000 | >0380 | >0800 | >0300 | >0400 | White/ Black | 40 | Text mode

PNT = Pattern Name Table
PCT = Pattern Color Table
PDT = Pattern Descriptor Table SAT = Sprite Attribute Table
SPT = Sprite Pattern Table

************************************************************** * ROM: VDP graphics mode 1 (values for shadow registers) ********@*****@*********************@************************** * VDP#0 Control bits
* | bit 6=0: M3 | Graphics 1 mode
* | bit 7=0: Disable external VDP input
* VDP#1 Control bits
* | bit 0=1: 16K selection
* | bit 1=1: Enable display
* | bit 2=1: Enable VDP interrupt
* | bit 3=0: M1 \ Graphics 1 mode
* | bit 4=0: M2 /
* | bit 5=0: reserved
* | bit 6=1: 16x16 sprites
* | bit 7=0: Sprite magnification (1x)
*
* VDP#2 PNT (Pattern name table) | at >0000 | (>00 * >400)
* VDP#3 PCT (Pattern color table) | at >0380 | (>0E * >040)
* VDP#4 PDT (Pattern descriptor table) at >0800 | (>01 * >800)
* VDP#5 SAT (sprite attribute list) | at >0300 | (>06 * >080)
* VDP#6 SPT (Sprite pattern table) | at >0400 | (>80 * >008)
* VDP#7 Set background color to black ***************************************************************
VMODE1 | DATA | >0000,>01E2,>0200,>030E,>0401,>0506,>0680,>0700,32

*************************************************************** * ROM: VDP text mode (values for shadow registers) ********@*****@*********************@************************** * VDP#0 Control bits
* | bit 6=0: M3 | Graphics 1 mode
* | bit 7=0: Disable external VDP input
* VDP#1 Control bits
* | bit 0=1: 16K selection
* | bit 1=1: Enable display
* | bit 2=1: Enable VDP interrupt
* | bit 3=1: M1 \ TEXT MODE
* | bit 4=0: M2 /
* | bit 5=0: reserved
* | bit 6=1: 16x16 sprites
* | bit 7=0: Sprite magnification (1x)
*
* VDP#2 PNT (Pattern name table) | at >0000 | (>00 * >400)
* VDP#3 PCT (Pattern color table) | at >0380 | (>0E * >040)
* VDP#4 PDT (Pattern descriptor table) at >0800 | (>01 * >800)
* VDP#5 SAT (sprite attribute list) | at >0300 | (>06 * >080)
* VDP#6 SPT (Sprite pattern table) | at >0400 | (>80 * >008)
* VDP#7 Set foreground color to white/Background color to black ***************************************************************
VMODET | DATA | >0000,>01F2,>0200,>030E,>0401,>0506,>0680,>07F0,40

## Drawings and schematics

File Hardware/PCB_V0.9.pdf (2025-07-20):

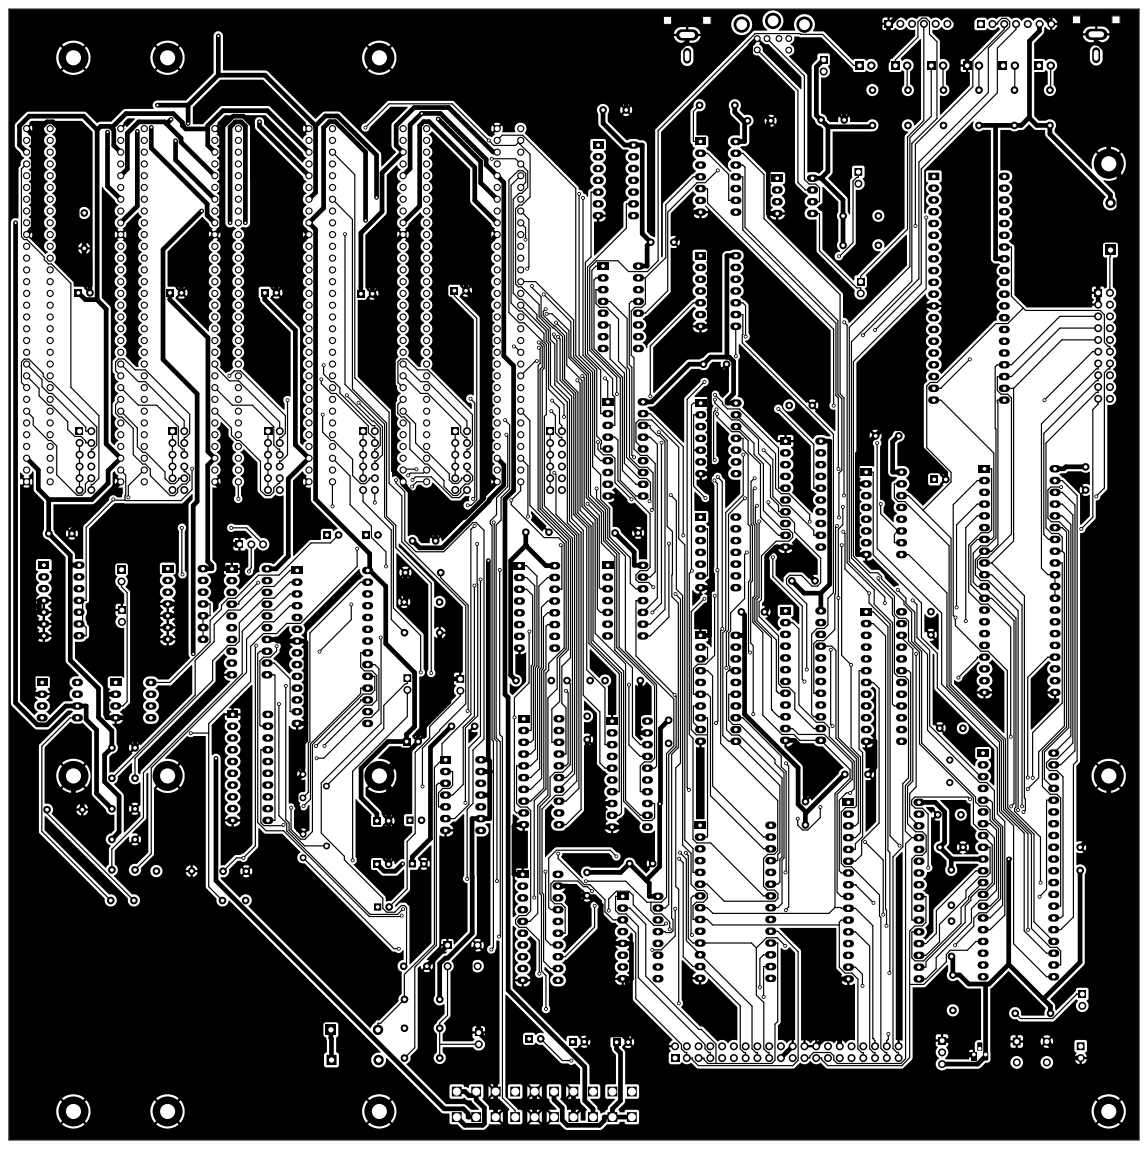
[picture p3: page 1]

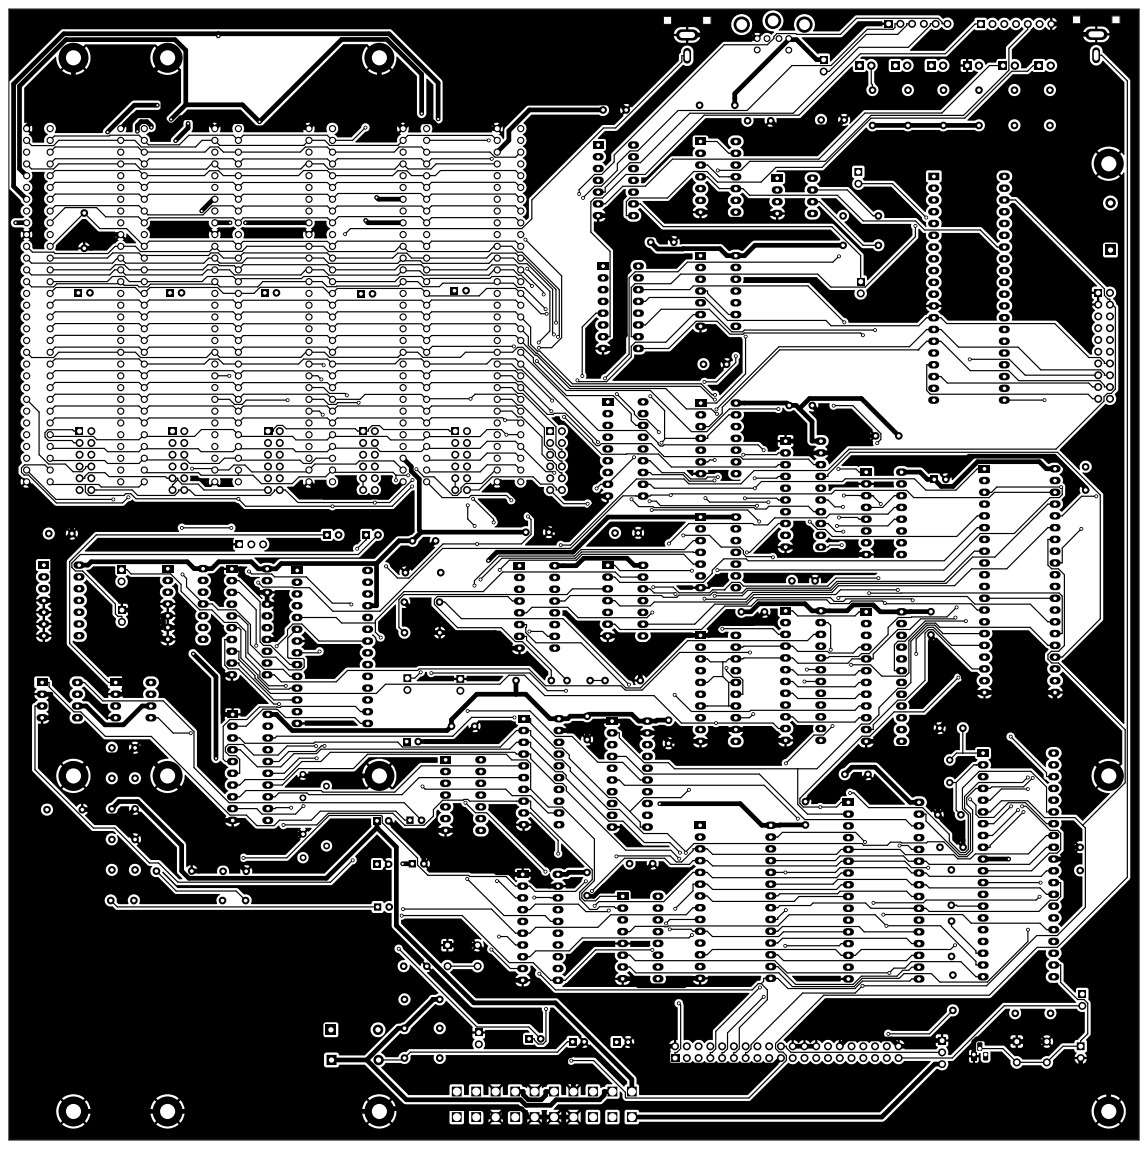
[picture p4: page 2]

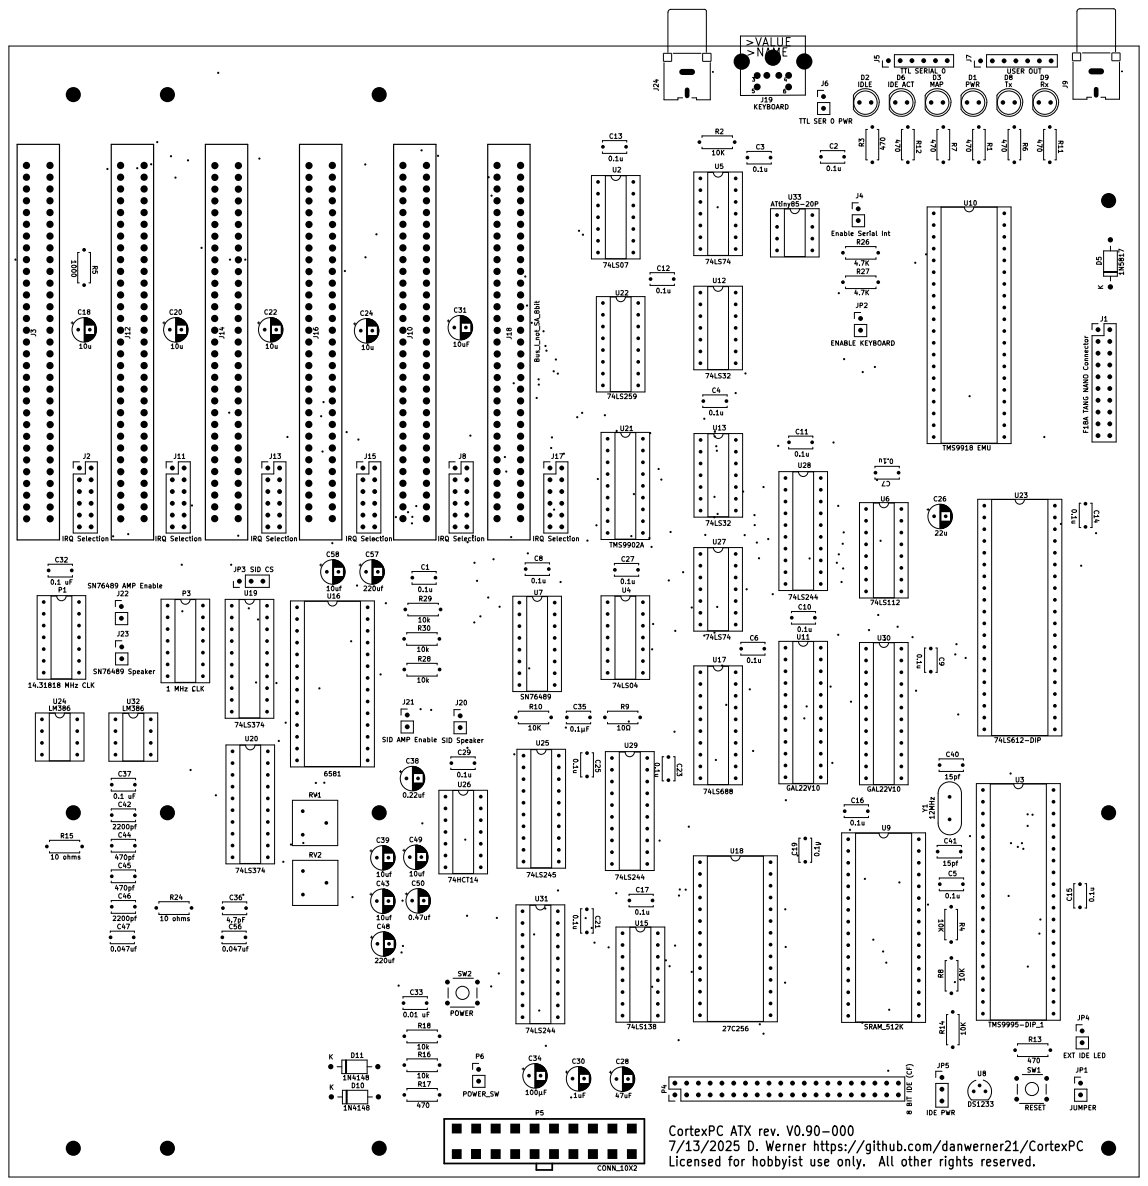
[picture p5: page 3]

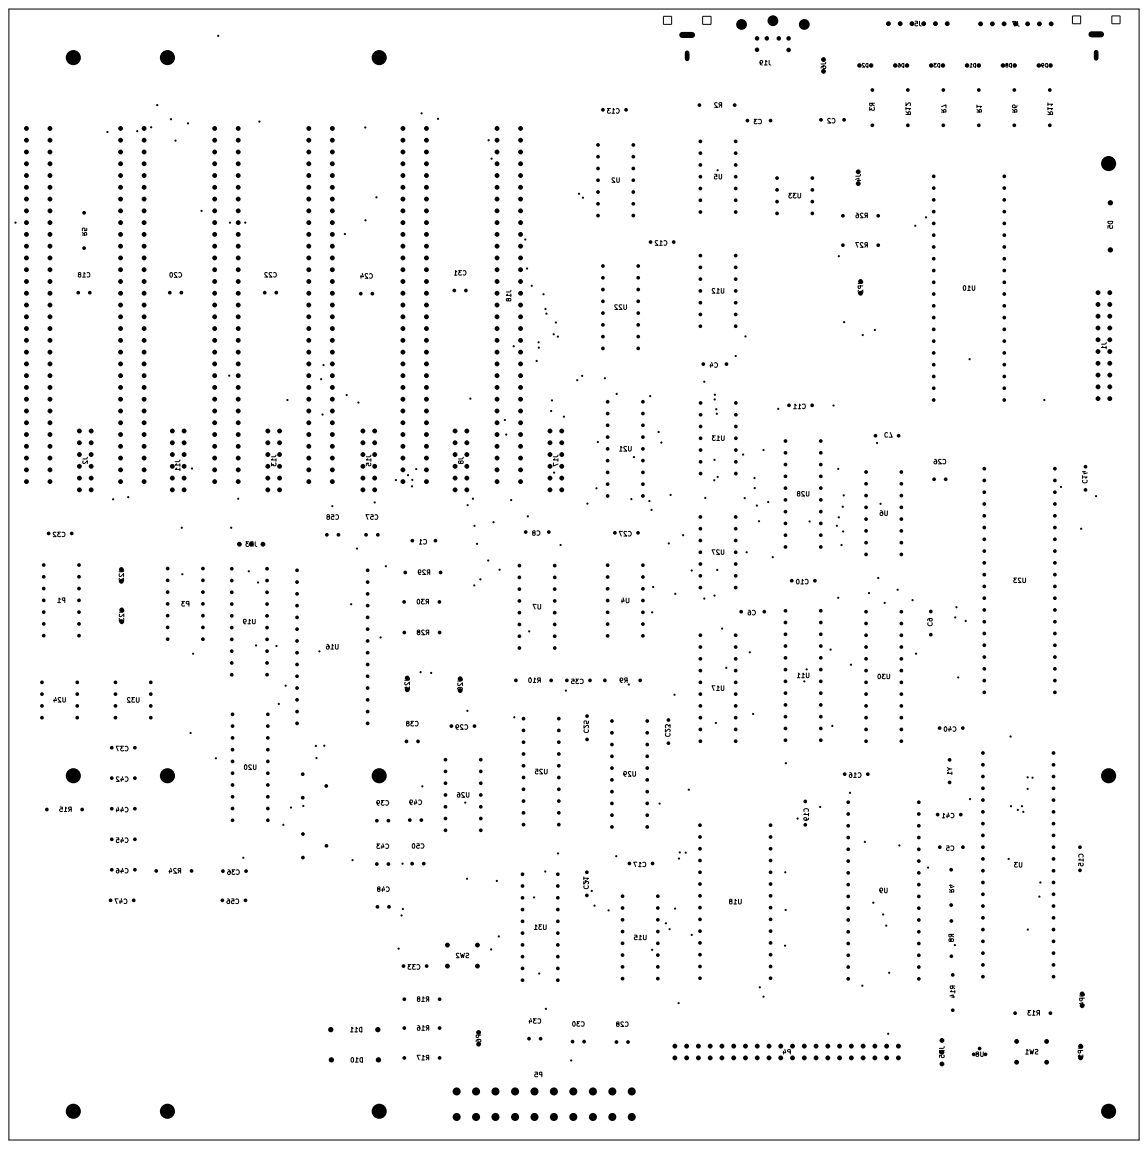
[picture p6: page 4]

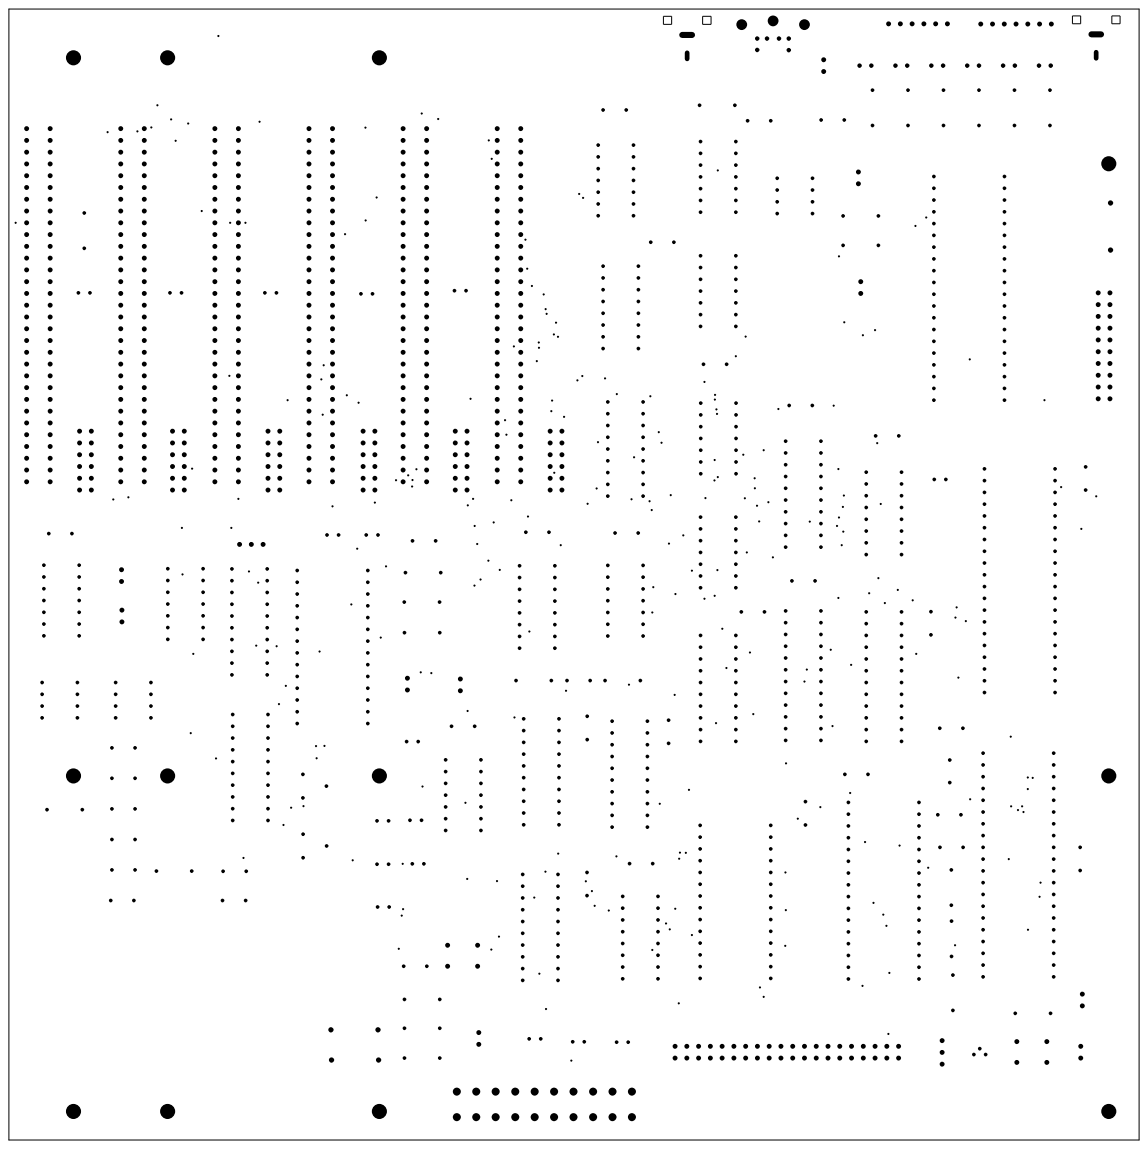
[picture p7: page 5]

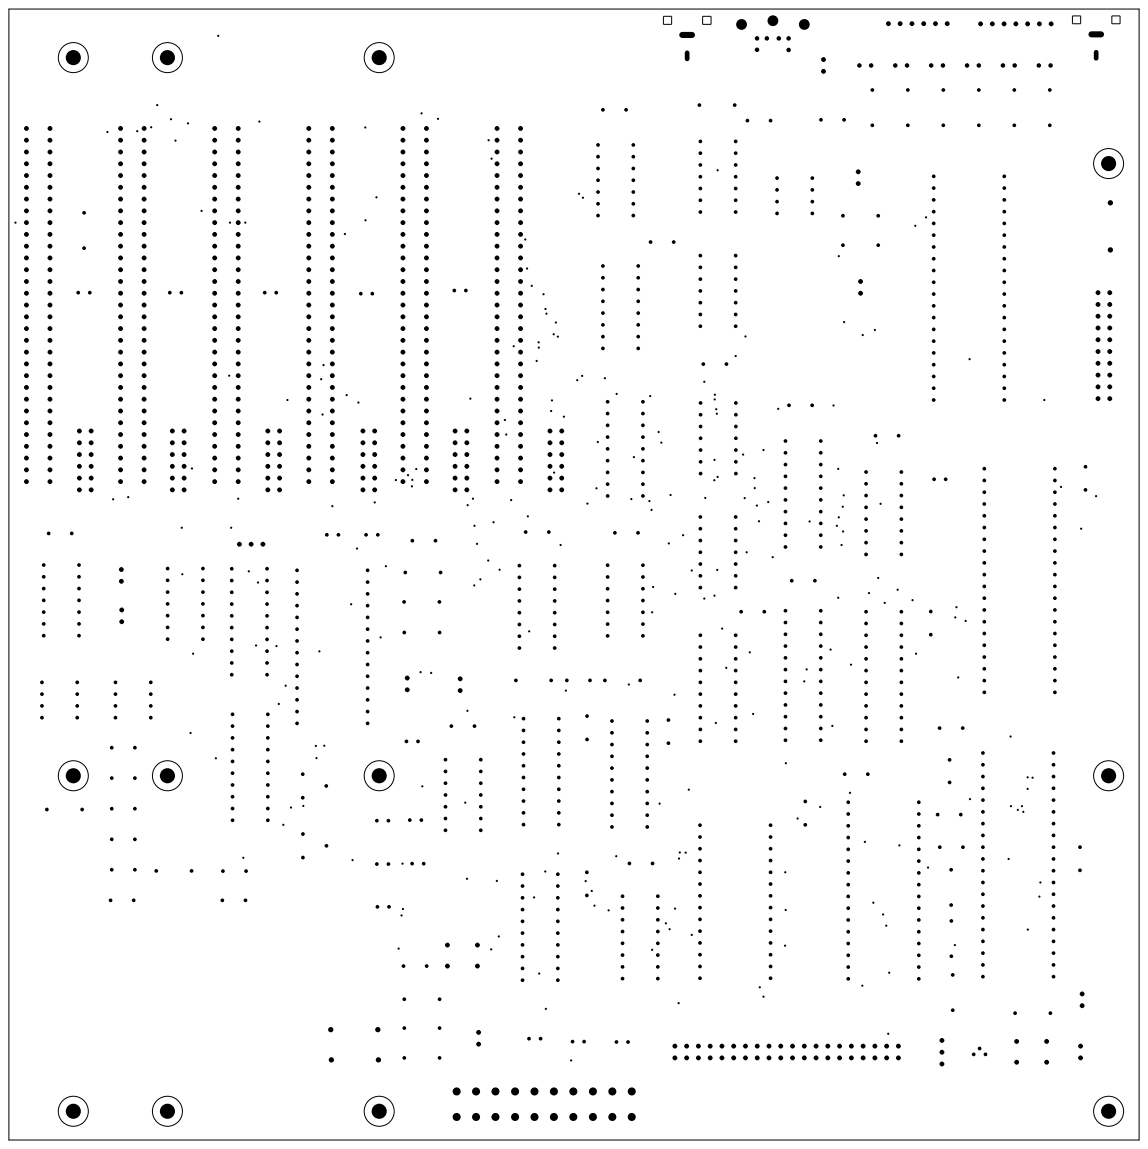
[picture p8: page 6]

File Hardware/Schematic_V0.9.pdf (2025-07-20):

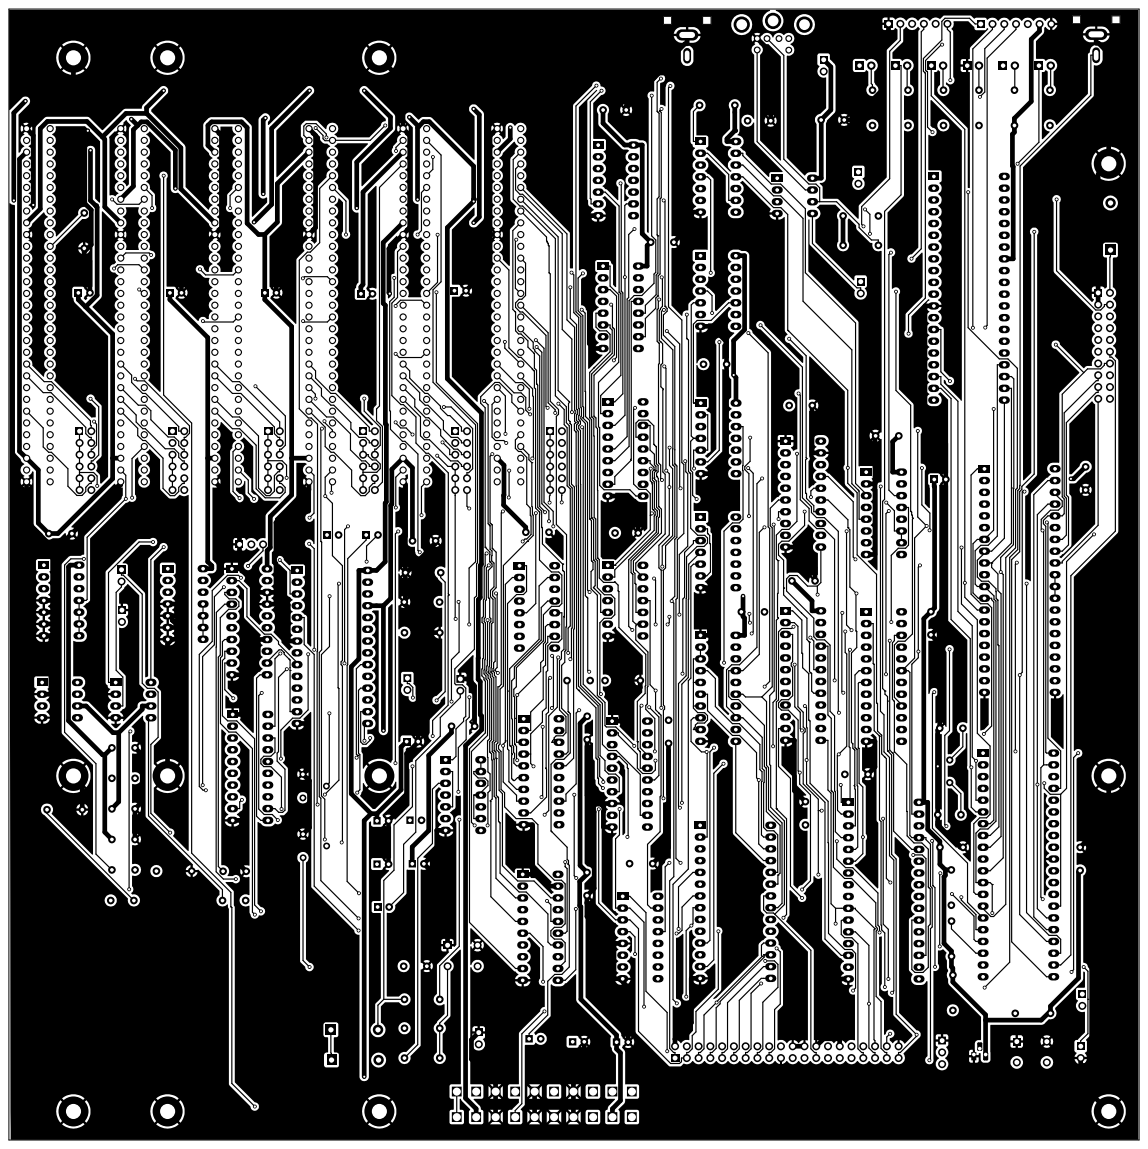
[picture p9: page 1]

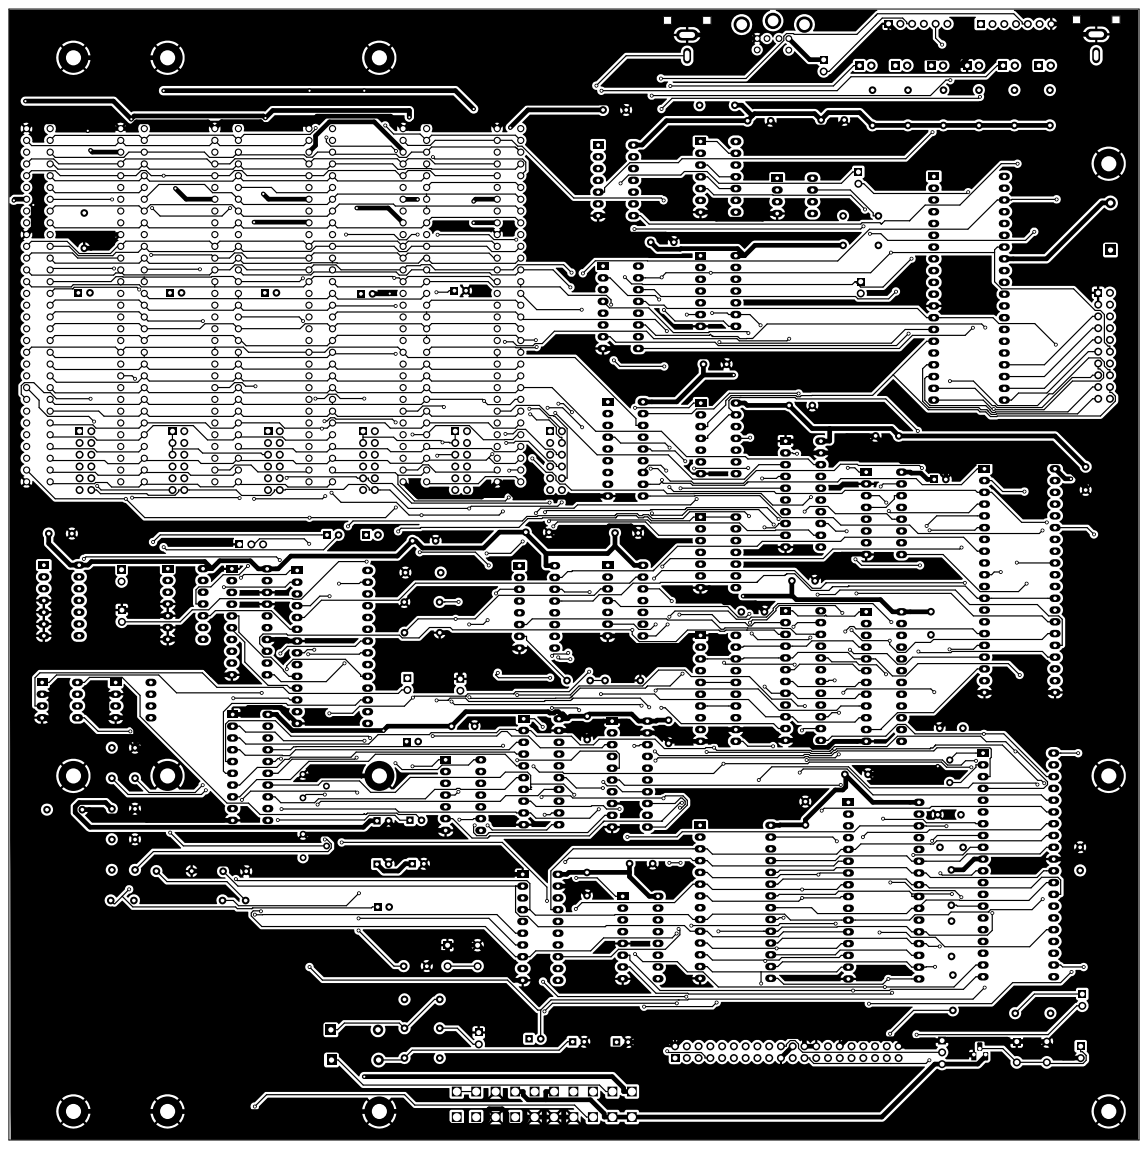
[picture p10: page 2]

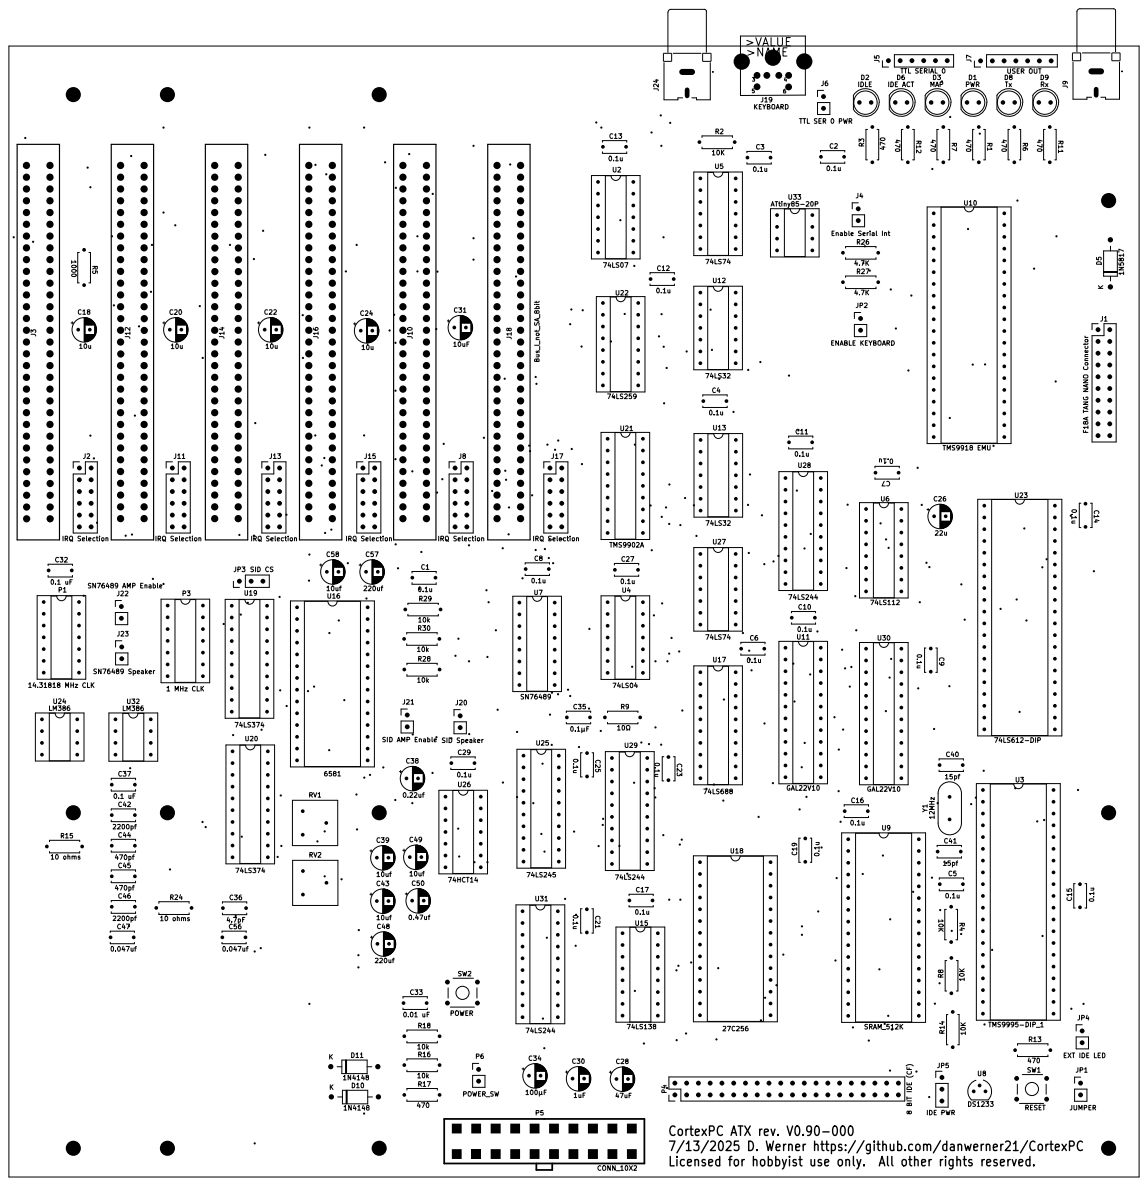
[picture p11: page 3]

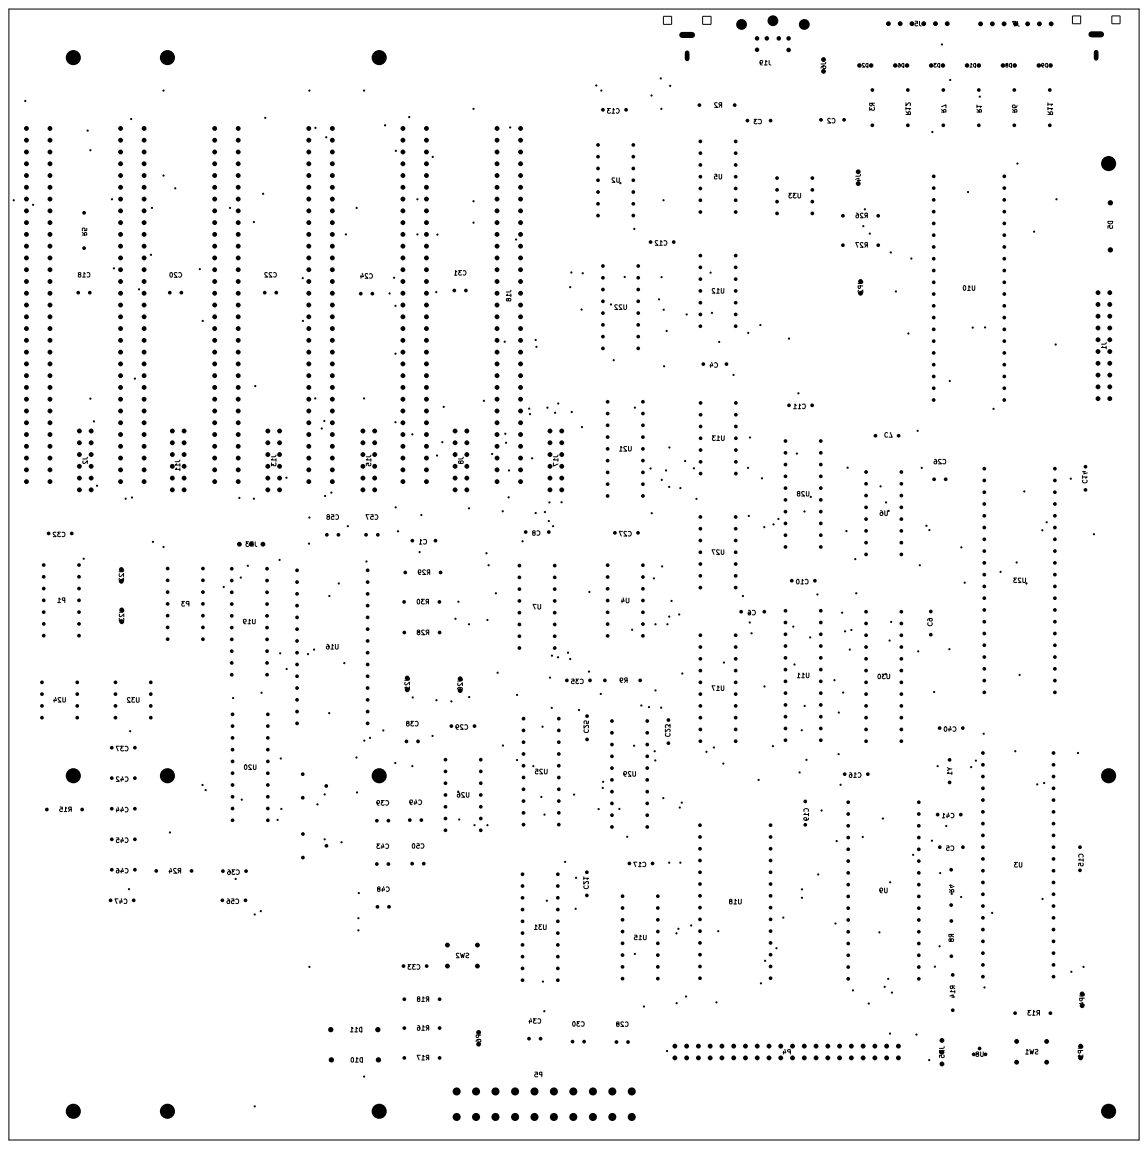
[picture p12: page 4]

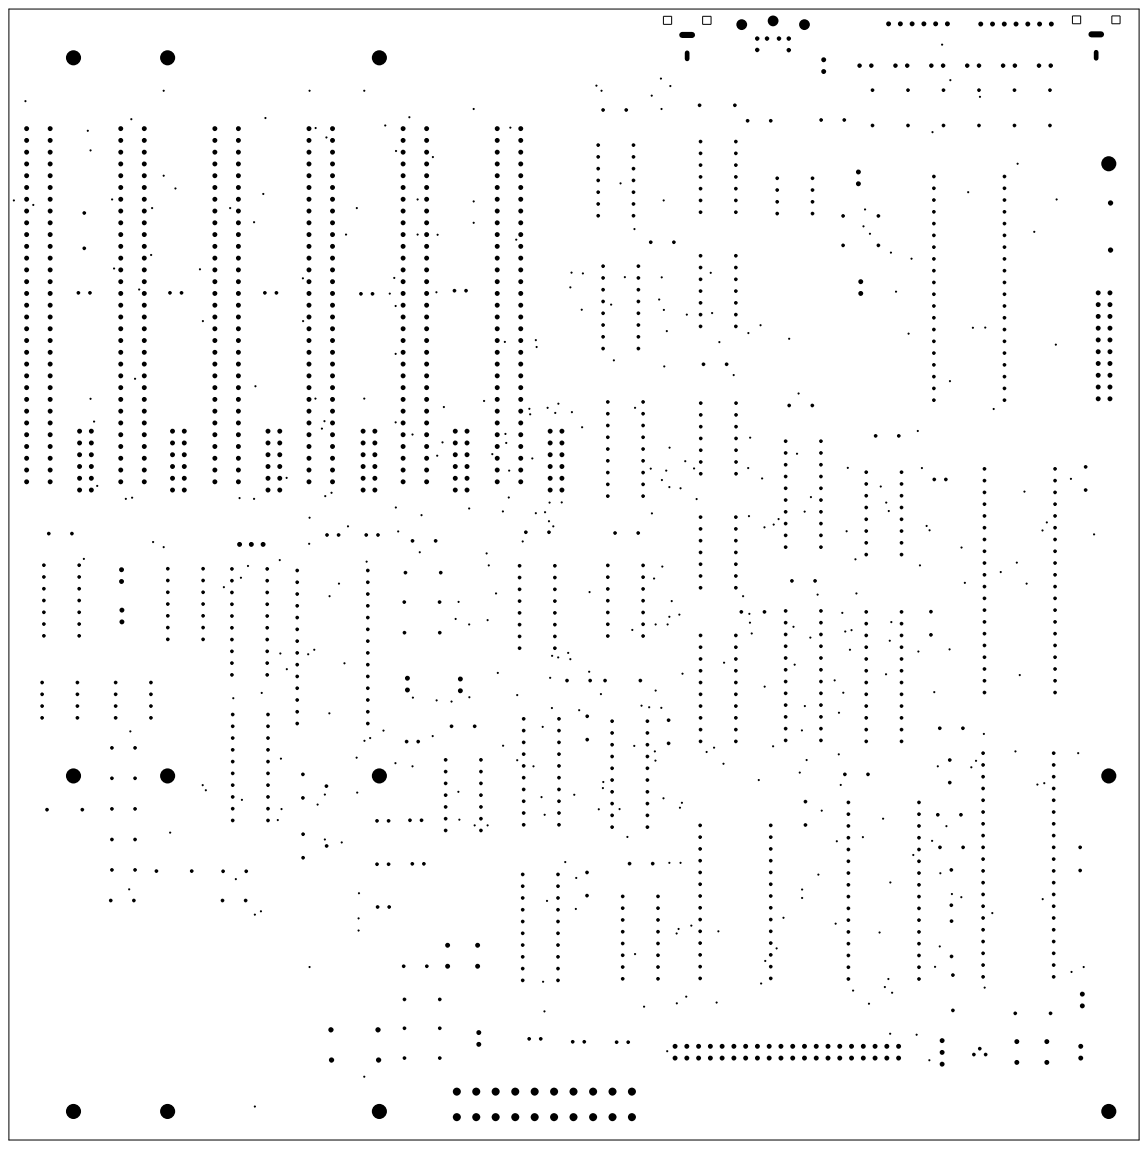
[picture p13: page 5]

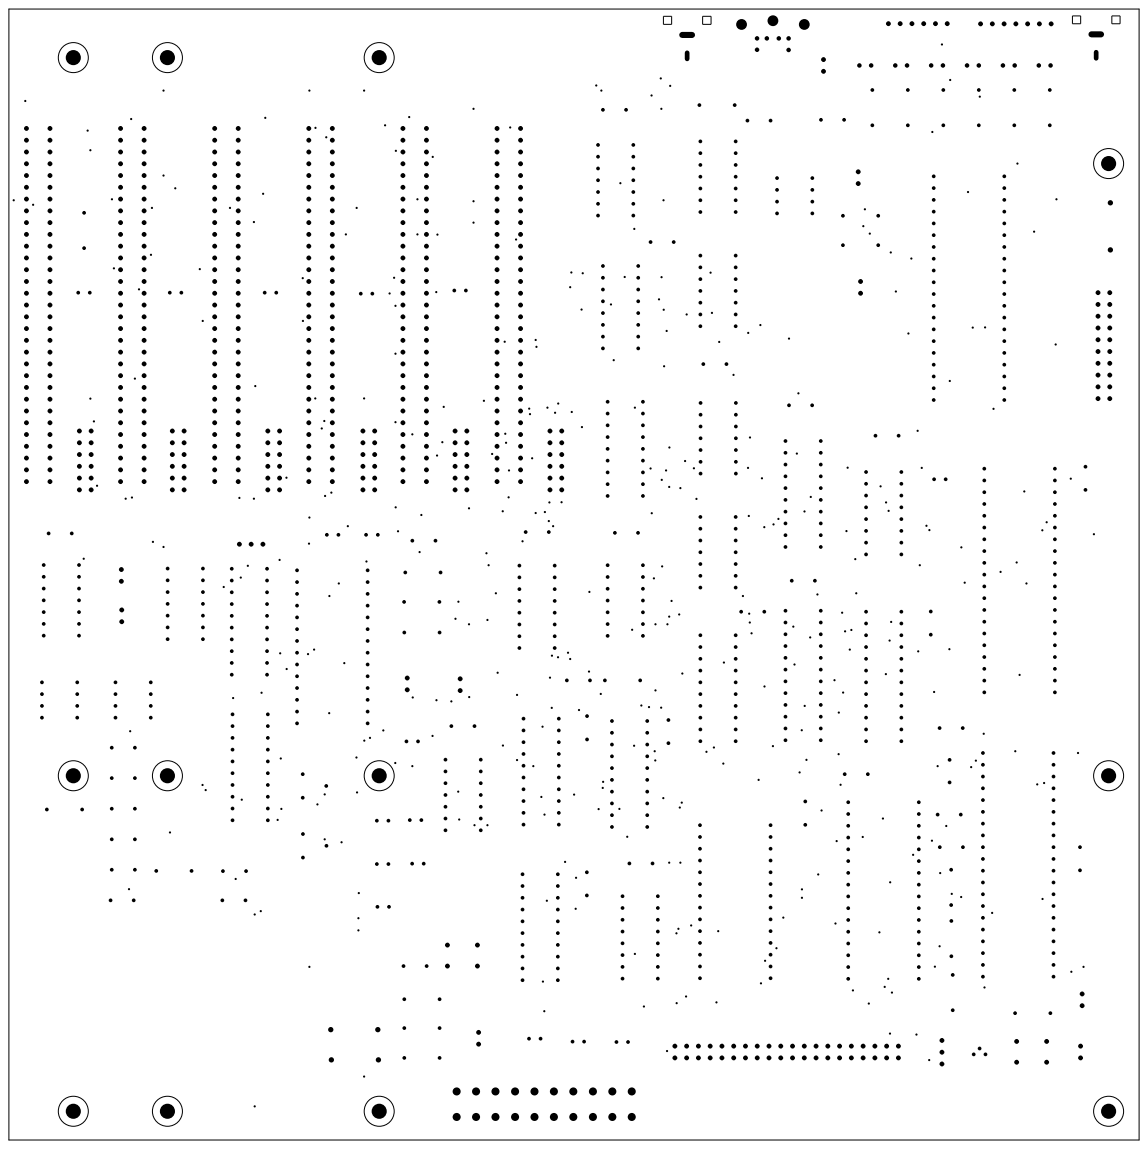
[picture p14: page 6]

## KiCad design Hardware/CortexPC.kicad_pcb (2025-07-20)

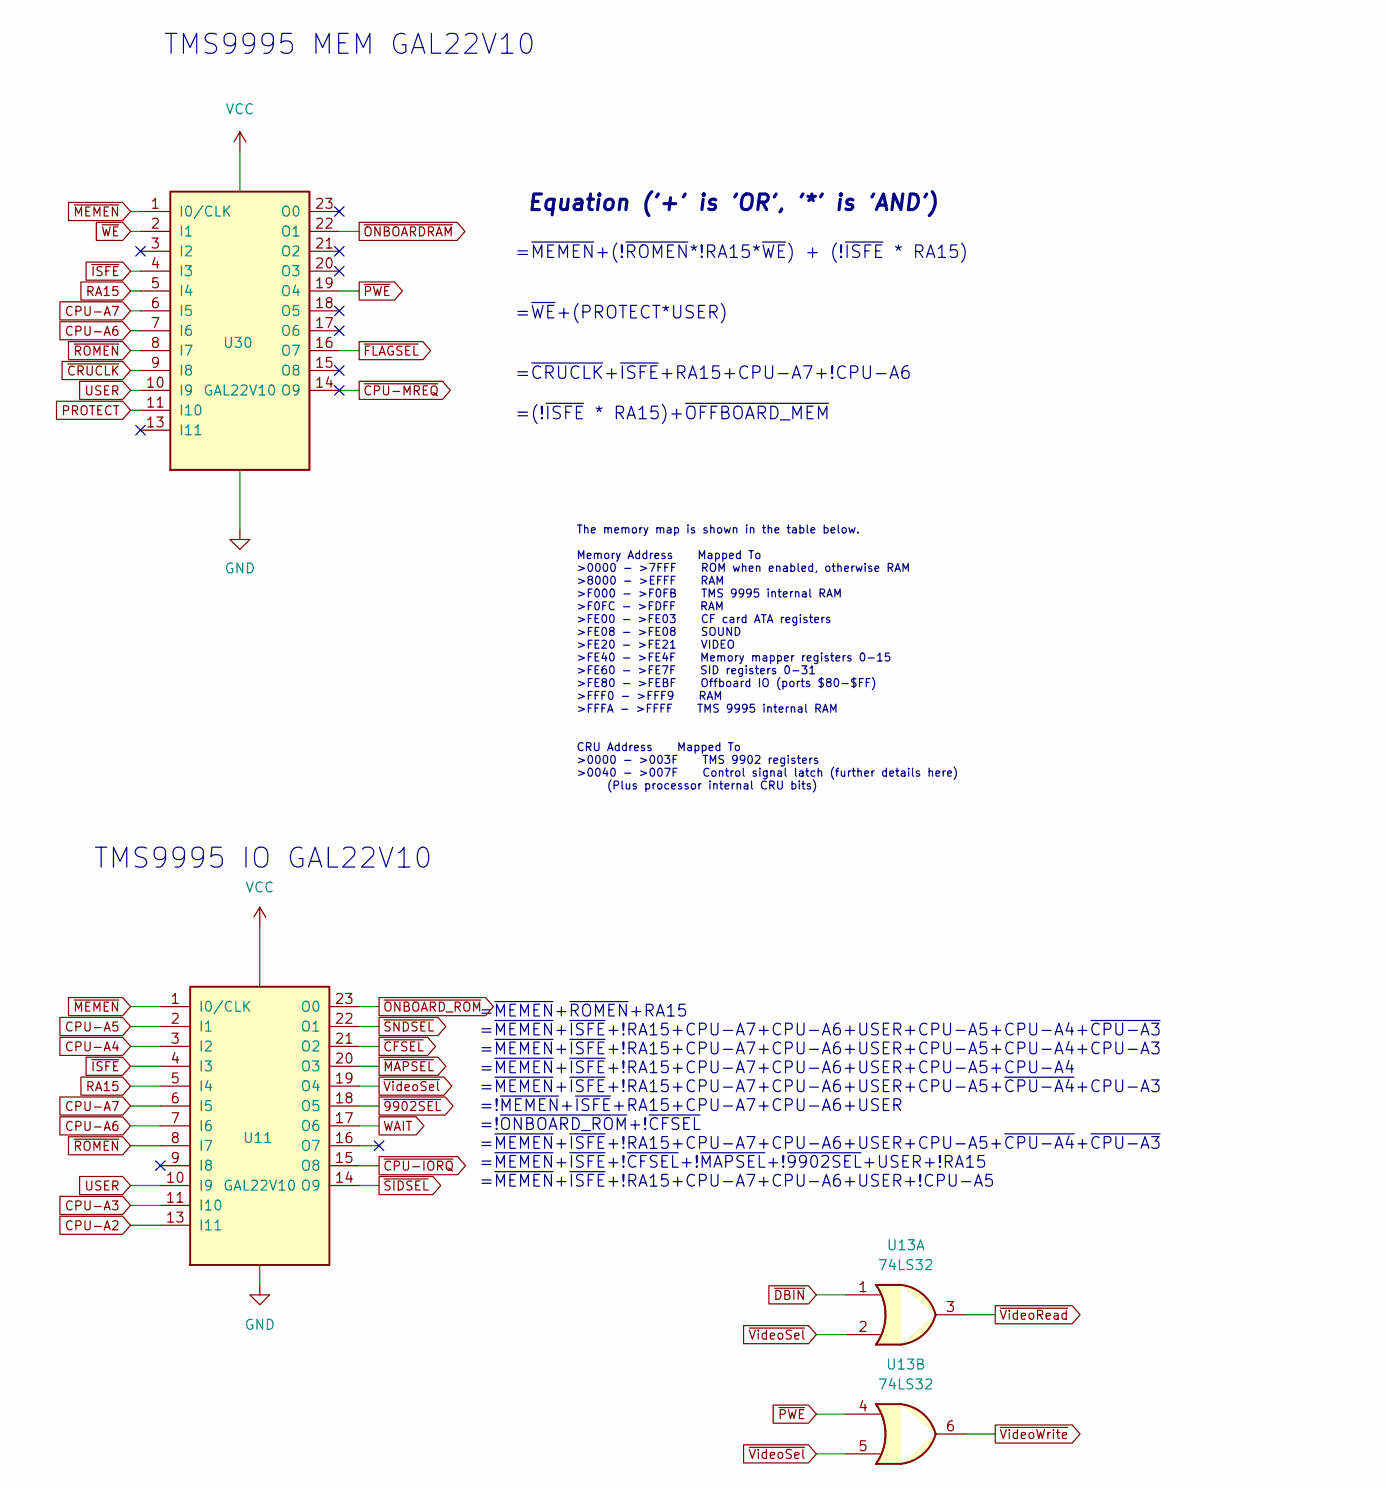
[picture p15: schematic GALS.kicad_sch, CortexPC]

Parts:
U11, U30: GAL22V10; STD_DDW_DIP24_Skinny
U13: 74LS32; STD_DDW_DIP14

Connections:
CPU-A2: U11.13 (I11); also elsewhere on the board
CPU-A3: U11.11 (I10); also elsewhere on the board
CPU-A4: U11.3 (I2); also elsewhere on the board
CPU-A5: U11.2 (I1); also elsewhere on the board
CPU-A6: U11.7 (I6), U30.7 (I6); also elsewhere on the board
CPU-A7: U11.6 (I5), U30.6 (I5); also elsewhere on the board
GND: U11.12 (GND), U30.12 (GND); also elsewhere on the board
PROTECT: U30.11 (I10); also elsewhere on the board
RA15: U11.5 (I4), U30.5 (I4); also elsewhere on the board
USER: U11.10 (I9), U30.10 (I9); also elsewhere on the board
VCC: U11.24 (VCC), U30.24 (VCC); also elsewhere on the board
WAIT: U11.17 (O6); also elsewhere on the board
~9902SEL: U11.18 (O5); also elsewhere on the board
~CFSEL: U11.21 (O2); also elsewhere on the board
~CPU-IORQ: U11.15 (O8); also elsewhere on the board
~CPU-MREQ: U30.14 (O9)
~CRUCLK: U30.9 (I8); also elsewhere on the board
~DBIN: U13.1; also elsewhere on the board
~FLAGSEL: U30.16 (O7); also elsewhere on the board
~ISFE: U11.4 (I3), U30.4 (I3); also elsewhere on the board
~MAPSEL: U11.20 (O3); also elsewhere on the board
~MEMEN: U11.1 (I0/CLK), U30.1 (I0/CLK); also elsewhere on the board
~ONBOARDRAM: U30.22 (O1); also elsewhere on the board
~ONBOARD_ROM: U11.23 (O0); also elsewhere on the board
~PWE: U13.4, U30.19 (O4); also elsewhere on the board
~ROMEN: U11.8 (I7), U30.8 (I7); also elsewhere on the board
~SIDSEL: U11.14 (O9); also elsewhere on the board
~SNDSEL: U11.22 (O1); also elsewhere on the board
~VideoRead: U13.3; also elsewhere on the board
~VideoSel: U11.19 (O4), U13.2, U13.5
~VideoWrite: U13.6; also elsewhere on the board
~WE: U30.2 (I1); also elsewhere on the board

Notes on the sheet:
=~{MEMEN}+(!~{ROMEN}*!RA15*~{WE}) + (!~{ISFE} * RA15) =~{WE}+(PROTECT*USER) =~{CRUCLK}+~{ISFE}+RA15+CPU-A7+!CPU-A6 =(!~{ISFE} * RA15)+~{OFFBOARD_MEM}
Equation ('+' is 'OR', '*' is 'AND')
TMS9995 MEM GAL22V10
The memory map is shown in the table below. Memory Address Mapped To >0000 - >7FFF ROM when enabled, otherwise RAM >8000 - >EFFF RAM >F000 - >F0FB TMS 9995 internal RAM >F0FC - >FDFF RAM >FE00 - >FE03 CF card ATA registers >FE08 - >FE08 SOUND >FE20 - >FE21 VIDEO >FE40 - >FE4F Memory mapper register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
TMS9995 IO GAL22V10
=~{MEMEN}+~{ROMEN}+RA15 =~{MEMEN}+~{ISFE}+!RA15+CPU-A7+CPU-A6+USER+CPU-A5+CPU-A4+~{CPU-A3} =~{MEMEN}+~{ISFE}+!RA15+CPU-A7+CPU-A6+USER+CPU-A5+CPU-A4+CPU-A3 =~{MEMEN}+~{ISFE}+!RA15+CPU-A7+CPU-A6+USER+CPU-A5+CPU-A4 =~{MEMEN}+~{ISFE}+!RA15+CPU-A7+CPU-A6+USER+CPU-A5+~{CPU-A4}+CPU-A3 =!~{MEMEN}+~{ISFE}+R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

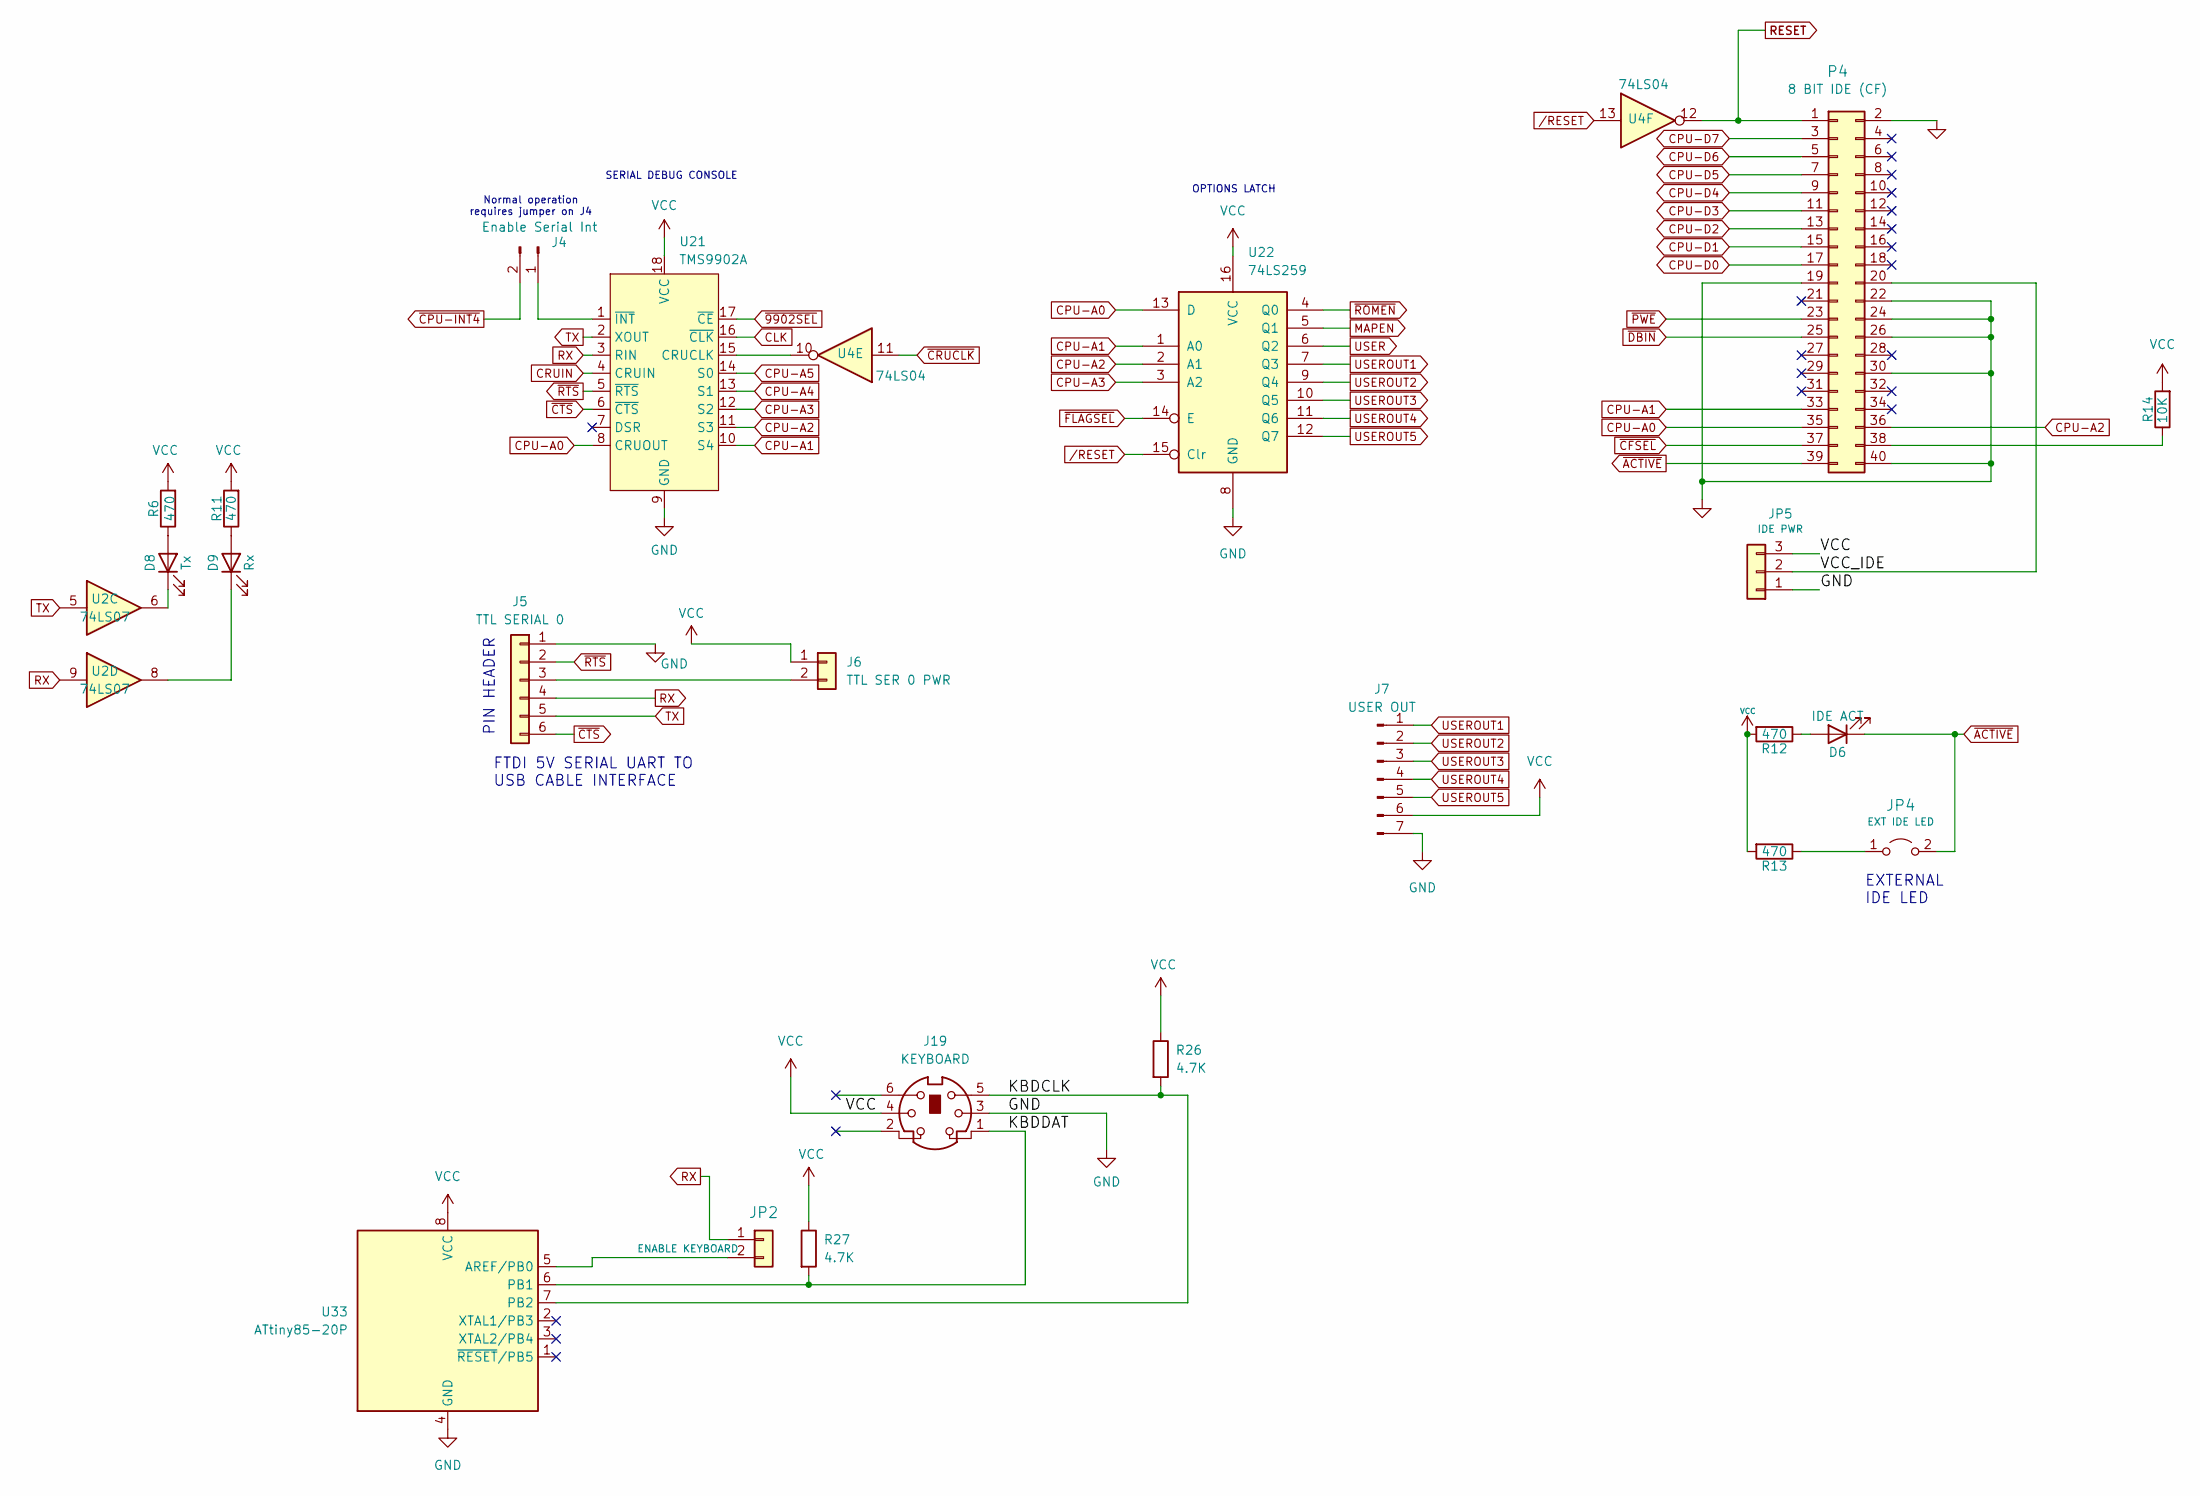
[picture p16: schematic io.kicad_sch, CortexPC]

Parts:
D6: IDE ACT; STD_DDW_LED5
D8: Tx; STD_DDW_LED5
D9: Rx; STD_DDW_LED5
J4: Enable Serial Int; STD_DDW_PINHEAD_V_1x02
J5: TTL SERIAL 0; STD_DDW_PINHEAD_V_1x06
J6: TTL SER 0 PWR; STD_DDW_PINHEAD_V_1x02
J7: USER OUT; STD_DDW_PINHEAD_V_1x07
J19: KEYBOARD; PS2_DIN
JP2: ENABLE KEYBOARD; STD_DDW_PINHEAD_V_1x02
JP4: EXT IDE LED; STD_DDW_PINHEAD_V_1x02
JP5: IDE PWR; STD_DDW_PINHEAD_V_1x03
P4: 8 BIT IDE (CF); STD_DDW_PINHEAD_V_2x20
R6, R11, R12, R13: 470; STD_DDW_RESISTOR
R14: 10K; STD_DDW_RESISTOR
R26, R27: 4.7K; STD_DDW_RESISTOR
U2: 74LS07; STD_DDW_DIP14
U4: 74LS04; STD_DDW_DIP14
U21: TMS9902A; STD_DDW_DIP18
U22: 74LS259; STD_DDW_DIP16
U33: ATtiny85-20P; STD_DDW_DIP8

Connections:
/IO/KBDCLK: J19.5, R26.2, U33.7 (PB2)
/IO/KBDDAT: J19.1, R27.2, U33.6 (PB1)
/IO/VCC_IDE: JP5.2, P4.20
CLK: U21.16 (~CLK); also elsewhere on the board
CPU-A0: P4.35, U21.8 (CRUOUT), U22.13 (D); also elsewhere on the board
CPU-A1: P4.33, U21.10 (S4), U22.1 (A0); also elsewhere on the board
CPU-A2: P4.36, U21.11 (S3), U22.2 (A1); also elsewhere on the board
CPU-A3: U21.12 (S2), U22.3 (A2); also elsewhere on the board
CPU-A4: U21.13 (S1); also elsewhere on the board
CPU-A5: U21.14 (S0); also elsewhere on the board
CPU-D0: P4.17; also elsewhere on the board
CPU-D1: P4.15; also elsewhere on the board
CPU-D2: P4.13; also elsewhere on the board
CPU-D3: P4.11; also elsewhere on the board
CPU-D4: P4.9; also elsewhere on the board
CPU-D5: P4.7; also elsewhere on the board
CPU-D6: P4.5; also elsewhere on the board
CPU-D7: P4.3; also elsewhere on the board
CRUIN: U21.4 (CRUIN); also elsewhere on the board
GND: J5.1, J7.7, J19.3, JP5.1, P4.2, P4.19, P4.22, P4.24, P4.26, P4.30, P4.40, U21.9 (GND), U22.8 (GND), U33.4 (GND); also elsewhere on the board
MAPEN: U22.5 (Q1); also elsewhere on the board
unnamed: D6.2 (A), R12.1
unnamed: D8.2 (A), R6.1
unnamed: D8.1 (K), U2.6
unnamed: D9.2 (A), R11.1
unnamed: D9.1 (K), U2.8
unnamed: J4.1, U21.1 (~INT)
unnamed: J5.3, J6.2
unnamed: JP2.2, U33.5 (AREF/PB0)
unnamed: JP4.1 (A), R13.1
unnamed: P4.38, R14.1
unnamed: U4.10, U21.15 (CRUCLK)
RESET: P4.1, U4.12; also elsewhere on the board
RX: J5.4, JP2.1, U2.9, U21.3 (RIN)
TX: J5.5, U2.5, U21.2 (XOUT)
USER: U22.6 (Q2); also elsewhere on the board
USEROUT1: J7.1, U22.7 (Q3)
USEROUT2: J7.2, U22.9 (Q4)
USEROUT3: J7.3, U22.10 (Q5)
USEROUT4: J7.4, U22.11 (Q6)
USEROUT5: J7.5, U22.12 (Q7)
VCC: J6.1, J7.6, J19.4, JP5.3, R6.2, R11.2, R12.2, R13.2, R14.2, R26.1, R27.1, U21.18 (VCC), U22.16 (VCC), U33.8 (VCC); also elsewhere on the board
/RESET: U4.13, U22.15 (Clr); also elsewhere on the board
~9902SEL: U21.17 (~CE); also elsewhere on the board
~ACTIVE: D6.1 (K), JP4.2 (B), P4.39
~CFSEL: P4.37; also elsewhere on the board
~CPU-INT4: J4.2; also elsewhere on the board
~CRUCLK: U4.11; also elsewhere on the board
~CTS: J5.6, U21.6 (~CTS)
~DBIN: P4.25; also elsewhere on the board
~FLAGSEL: U22.14 (E); also elsewhere on the board
~PWE: P4.23; also elsewhere on the board
~ROMEN: U22.4 (Q0); also elsewhere on the board
~RTS: J5.2, U21.5 (~RTS)

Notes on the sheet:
Normal operation requires jumper on J4
PIN HEADER
FTDI 5V SERIAL UART TO USB CABLE INTERFACE
EXTERNAL IDE LED
SERIAL DEBUG CONSOLE
OPTIONS LATCH

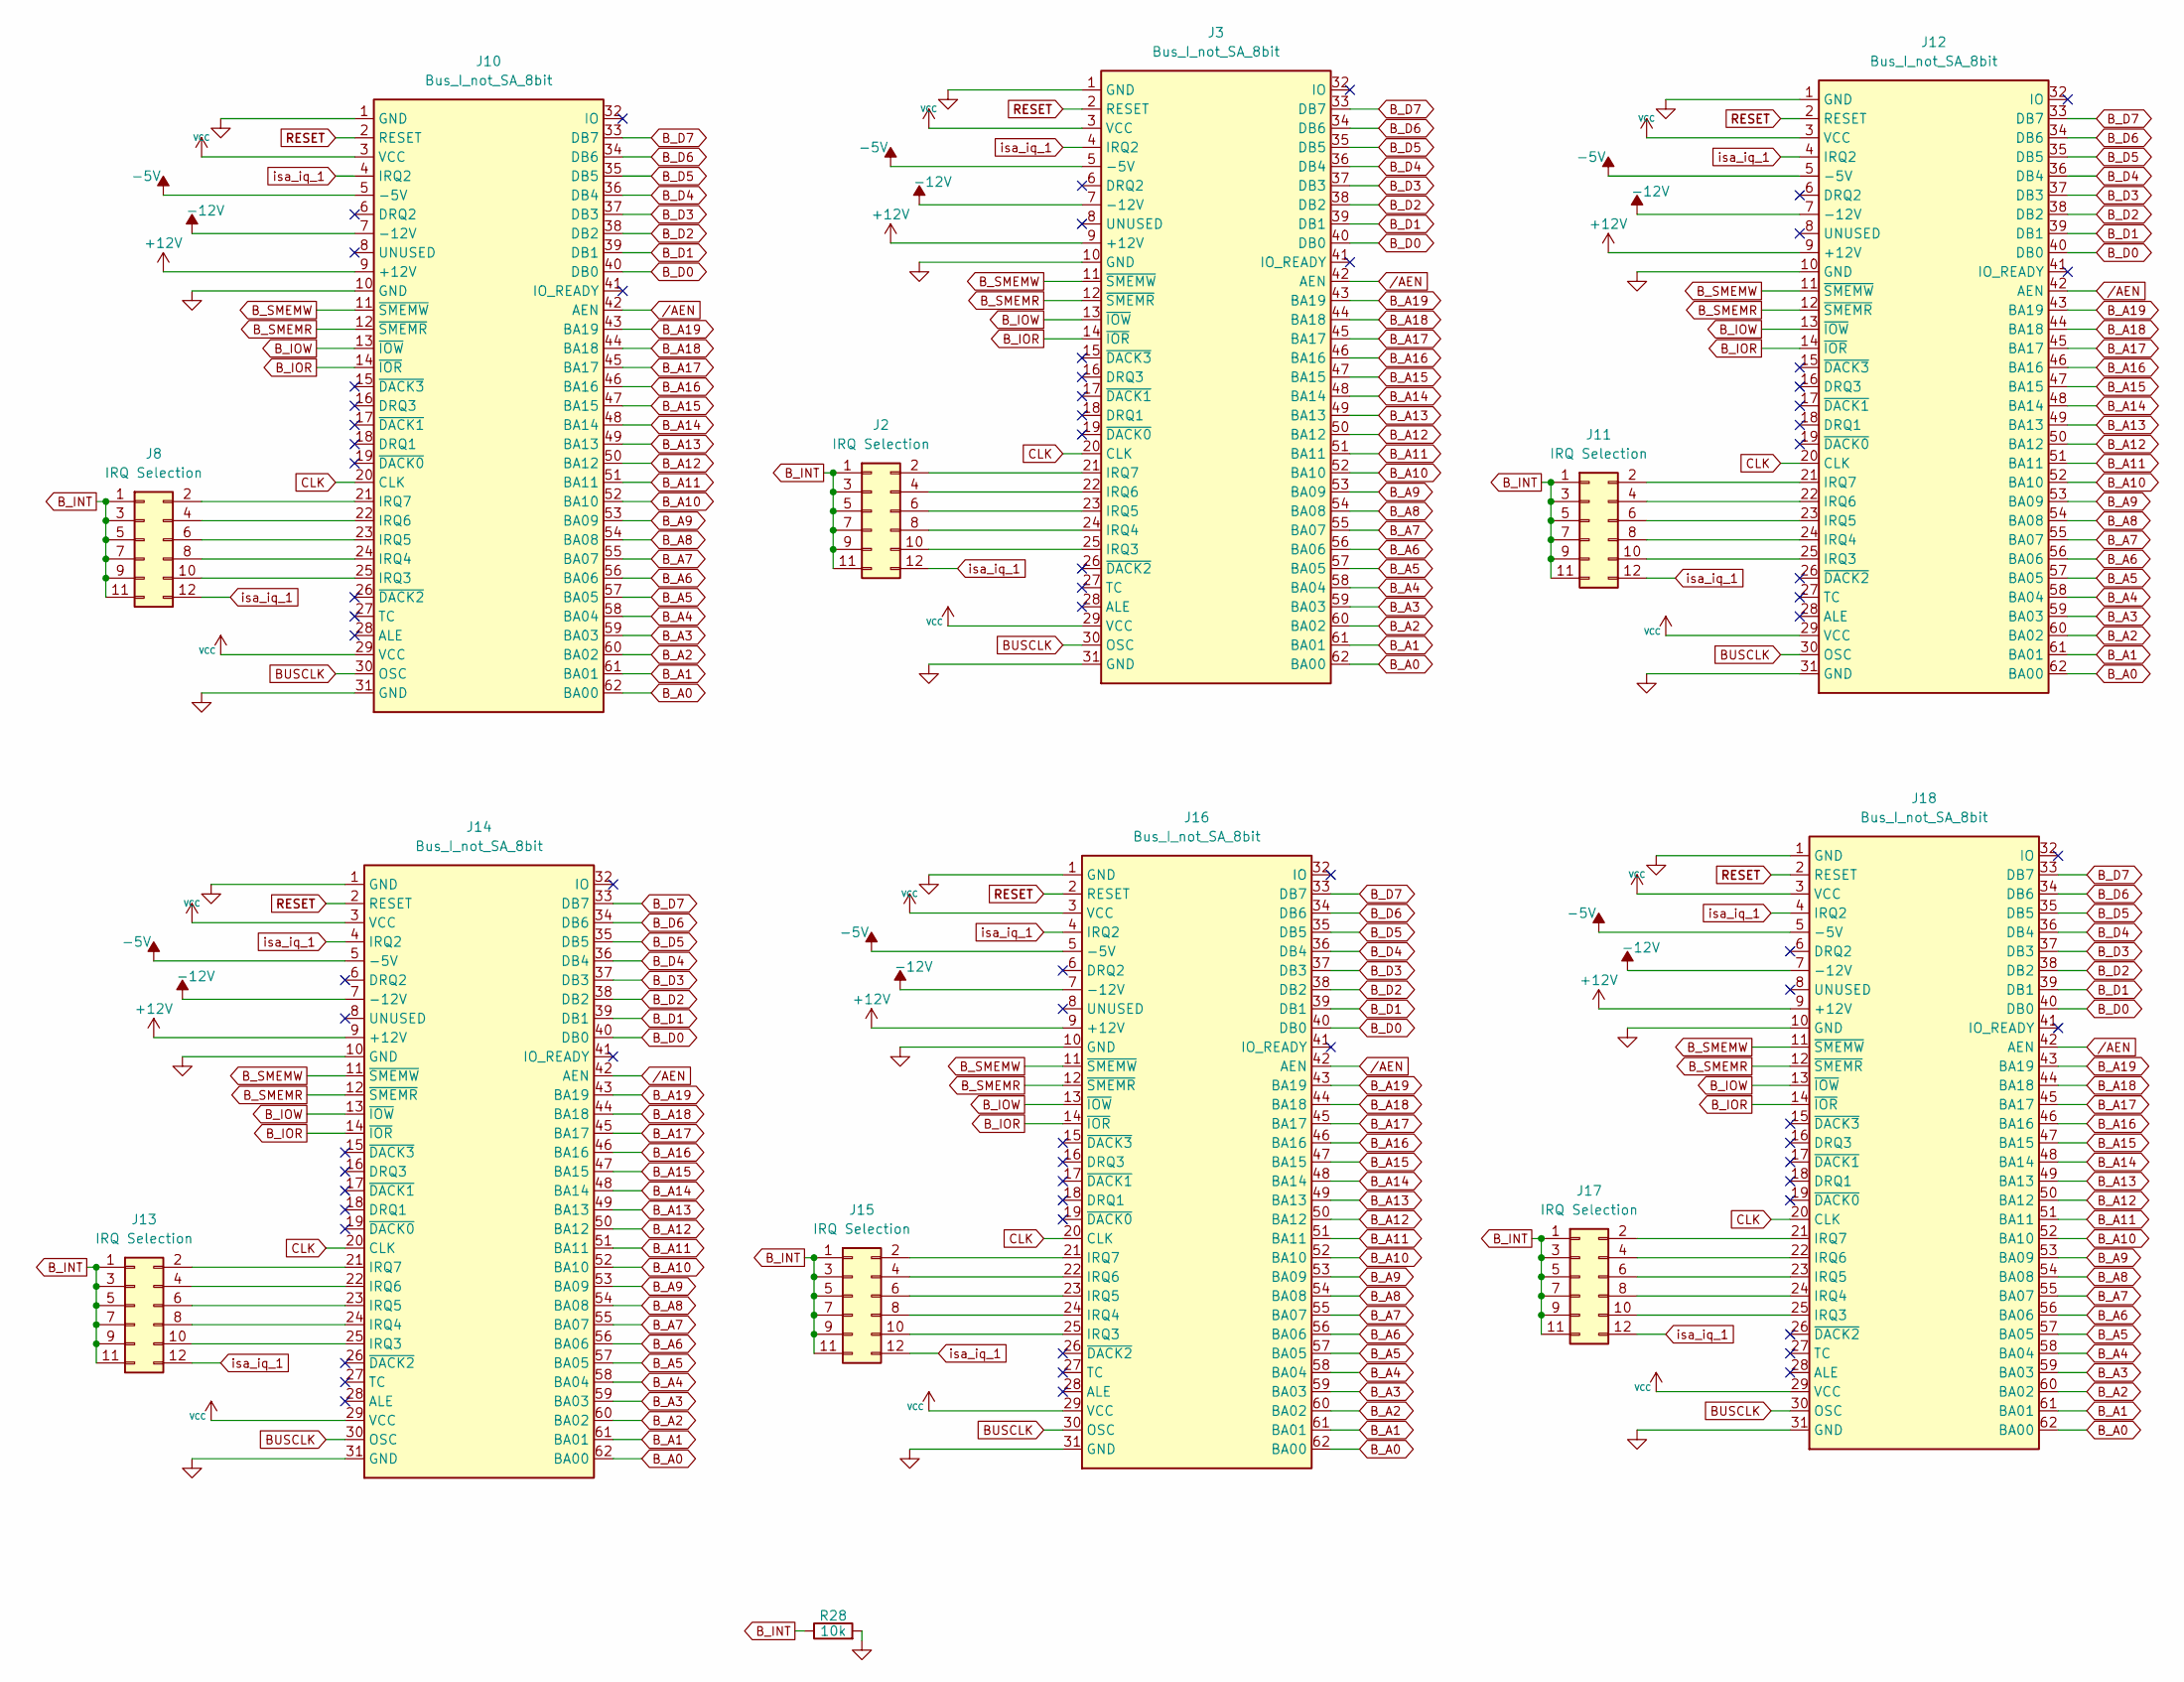
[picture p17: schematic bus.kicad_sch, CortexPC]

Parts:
J2, J8, J11, J13, J15, J17: IRQ Selection; STD_DDW_PINHEAD_V_2x06
J3, J10, J12, J14, J16, J18: Bus_I_not_SA_8bit; BUSPC_HOST
R28: 10k; STD_DDW_RESISTOR

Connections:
+12V: J3.9 (+12V), J10.9 (+12V), J12.9 (+12V), J14.9 (+12V), J16.9 (+12V), J18.9 (+12V); also elsewhere on the board
-5V: J3.5 (-5V), J10.5 (-5V), J12.5 (-5V), J14.5 (-5V), J16.5 (-5V), J18.5 (-5V); also elsewhere on the board
-12V: J3.7 (-12V), J10.7 (-12V), J12.7 (-12V), J14.7 (-12V), J16.7 (-12V), J18.7 (-12V); also elsewhere on the board
BUSCLK: J3.30 (OSC), J10.30 (OSC), J12.30 (OSC), J14.30 (OSC), J16.30 (OSC), J18.30 (OSC); also elsewhere on the board
B_A0: J3.62 (BA00), J10.62 (BA00), J12.62 (BA00), J14.62 (BA00), J16.62 (BA00), J18.62 (BA00); also elsewhere on the board
B_A1: J3.61 (BA01), J10.61 (BA01), J12.61 (BA01), J14.61 (BA01), J16.61 (BA01), J18.61 (BA01); also elsewhere on the board
B_A2: J3.60 (BA02), J10.60 (BA02), J12.60 (BA02), J14.60 (BA02), J16.60 (BA02), J18.60 (BA02); also elsewhere on the board
B_A3: J3.59 (BA03), J10.59 (BA03), J12.59 (BA03), J14.59 (BA03), J16.59 (BA03), J18.59 (BA03); also elsewhere on the board
B_A4: J3.58 (BA04), J10.58 (BA04), J12.58 (BA04), J14.58 (BA04), J16.58 (BA04), J18.58 (BA04); also elsewhere on the board
B_A5: J3.57 (BA05), J10.57 (BA05), J12.57 (BA05), J14.57 (BA05), J16.57 (BA05), J18.57 (BA05); also elsewhere on the board
B_A6: J3.56 (BA06), J10.56 (BA06), J12.56 (BA06), J14.56 (BA06), J16.56 (BA06), J18.56 (BA06); also elsewhere on the board
B_A7: J3.55 (BA07), J10.55 (BA07), J12.55 (BA07), J14.55 (BA07), J16.55 (BA07), J18.55 (BA07); also elsewhere on the board
B_A8: J3.54 (BA08), J10.54 (BA08), J12.54 (BA08), J14.54 (BA08), J16.54 (BA08), J18.54 (BA08); also elsewhere on the board
B_A9: J3.53 (BA09), J10.53 (BA09), J12.53 (BA09), J14.53 (BA09), J16.53 (BA09), J18.53 (BA09); also elsewhere on the board
B_A10: J3.52 (BA10), J10.52 (BA10), J12.52 (BA10), J14.52 (BA10), J16.52 (BA10), J18.52 (BA10); also elsewhere on the board
B_A11: J3.51 (BA11), J10.51 (BA11), J12.51 (BA11), J14.51 (BA11), J16.51 (BA11), J18.51 (BA11); also elsewhere on the board
B_A12: J3.50 (BA12), J10.50 (BA12), J12.50 (BA12), J14.50 (BA12), J16.50 (BA12), J18.50 (BA12); also elsewhere on the board
B_A13: J3.49 (BA13), J10.49 (BA13), J12.49 (BA13), J14.49 (BA13), J16.49 (BA13), J18.49 (BA13); also elsewhere on the board
B_A14: J3.48 (BA14), J10.48 (BA14), J12.48 (BA14), J14.48 (BA14), J16.48 (BA14), J18.48 (BA14); also elsewhere on the board
B_A15: J3.47 (BA15), J10.47 (BA15), J12.47 (BA15), J14.47 (BA15), J16.47 (BA15), J18.47 (BA15); also elsewhere on the board
B_A16: J3.46 (BA16), J10.46 (BA16), J12.46 (BA16), J14.46 (BA16), J16.46 (BA16), J18.46 (BA16); also elsewhere on the board
B_A17: J3.45 (BA17), J10.45 (BA17), J12.45 (BA17), J14.45 (BA17), J16.45 (BA17), J18.45 (BA17); also elsewhere on the board
B_A18: J3.44 (BA18), J10.44 (BA18), J12.44 (BA18), J14.44 (BA18), J16.44 (BA18), J18.44 (BA18); also elsewhere on the board
B_A19: J3.43 (BA19), J10.43 (BA19), J12.43 (BA19), J14.43 (BA19), J16.43 (BA19), J18.43 (BA19); also elsewhere on the board
B_D0: J3.40 (DB0), J10.40 (DB0), J12.40 (DB0), J14.40 (DB0), J16.40 (DB0), J18.40 (DB0); also elsewhere on the board
B_D1: J3.39 (DB1), J10.39 (DB1), J12.39 (DB1), J14.39 (DB1), J16.39 (DB1), J18.39 (DB1); also elsewhere on the board
B_D2: J3.38 (DB2), J10.38 (DB2), J12.38 (DB2), J14.38 (DB2), J16.38 (DB2), J18.38 (DB2); also elsewhere on the board
B_D3: J3.37 (DB3), J10.37 (DB3), J12.37 (DB3), J14.37 (DB3), J16.37 (DB3), J18.37 (DB3); also elsewhere on the board
B_D4: J3.36 (DB4), J10.36 (DB4), J12.36 (DB4), J14.36 (DB4), J16.36 (DB4), J18.36 (DB4); also elsewhere on the board
B_D5: J3.35 (DB5), J10.35 (DB5), J12.35 (DB5), J14.35 (DB5), J16.35 (DB5), J18.35 (DB5); also elsewhere on the board
B_D6: J3.34 (DB6), J10.34 (DB6), J12.34 (DB6), J14.34 (DB6), J16.34 (DB6), J18.34 (DB6); also elsewhere on the board
B_D7: J3.33 (DB7), J10.33 (DB7), J12.33 (DB7), J14.33 (DB7), J16.33 (DB7), J18.33 (DB7); also elsewhere on the board
B_INT: J2.1, J2.3, J2.5, J2.7, J2.9, J2.11, J8.1, J8.3, J8.5, J8.7, J8.9, J8.11, J11.1, J11.3, J11.5, J11.7, J11.9, J11.11, J13.1, J13.3, J13.5, J13.7, J13.9, J13.11, J15.1, J15.3, J15.5, J15.7, J15.9, J15.11, J17.1, J17.3, J17.5, J17.7, J17.9, J17.11, R28.1; also elsewhere on the board
B_IOR: J3.14 (~IOR), J10.14 (~IOR), J12.14 (~IOR), J14.14 (~IOR), J16.14 (~IOR), J18.14 (~IOR); also elsewhere on the board
B_IOW: J3.13 (~IOW), J10.13 (~IOW), J12.13 (~IOW), J14.13 (~IOW), J16.13 (~IOW), J18.13 (~IOW); also elsewhere on the board
B_SMEMR: J3.12 (~SMEMR), J10.12 (~SMEMR), J12.12 (~SMEMR), J14.12 (~SMEMR), J16.12 (~SMEMR), J18.12 (~SMEMR); also elsewhere on the board
B_SMEMW: J3.11 (~SMEMW), J10.11 (~SMEMW), J12.11 (~SMEMW), J14.11 (~SMEMW), J16.11 (~SMEMW), J18.11 (~SMEMW); also elsewhere on the board
CLK: J3.20 (CLK), J10.20 (CLK), J12.20 (CLK), J14.20 (CLK), J16.20 (CLK), J18.20 (CLK); also elsewhere on the board
GND: J3.1 (GND), J3.10 (GND), J3.31 (GND), J10.1 (GND), J10.10 (GND), J10.31 (GND), J12.1 (GND), J12.10 (GND), J12.31 (GND), J14.1 (GND), J14.10 (GND), J14.31 (GND), J16.1 (GND), J16.10 (GND), J16.31 (GND), J18.1 (GND), J18.10 (GND), J18.31 (GND), R28.2; also elsewhere on the board
unnamed: J2.2, J3.21 (IRQ7)
unnamed: J2.4, J3.22 (IRQ6)
unnamed: J2.6, J3.23 (IRQ5)
unnamed: J2.8, J3.24 (IRQ4)
unnamed: J2.10, J3.25 (IRQ3)
unnamed: J8.10, J10.25 (IRQ3)
unnamed: J8.8, J10.24 (IRQ4)
unnamed: J8.6, J10.23 (IRQ5)
unnamed: J8.4, J10.22 (IRQ6)
unnamed: J8.2, J10.21 (IRQ7)
unnamed: J11.2, J12.21 (IRQ7)
unnamed: J11.4, J12.22 (IRQ6)
unnamed: J11.6, J12.23 (IRQ5)
unnamed: J11.8, J12.24 (IRQ4)
unnamed: J11.10, J12.25 (IRQ3)
unnamed: J13.2, J14.21 (IRQ7)
unnamed: J13.4, J14.22 (IRQ6)
unnamed: J13.6, J14.23 (IRQ5)
unnamed: J13.8, J14.24 (IRQ4)
unnamed: J13.10, J14.25 (IRQ3)
unnamed: J15.2, J16.21 (IRQ7)
unnamed: J15.4, J16.22 (IRQ6)
unnamed: J15.6, J16.23 (IRQ5)
unnamed: J15.8, J16.24 (IRQ4)
unnamed: J15.10, J16.25 (IRQ3)
unnamed: J17.2, J18.21 (IRQ7)
unnamed: J17.4, J18.22 (IRQ6)
unnamed: J17.6, J18.23 (IRQ5)
unnamed: J17.8, J18.24 (IRQ4)
unnamed: J17.10, J18.25 (IRQ3)
RESET: J3.2 (RESET), J10.2 (RESET), J12.2 (RESET), J14.2 (RESET), J16.2 (RESET), J18.2 (RESET); also elsewhere on the board
VCC: J3.3 (VCC), J3.29 (VCC), J10.3 (VCC), J10.29 (VCC), J12.3 (VCC), J12.29 (VCC), J14.3 (VCC), J14.29 (VCC), J16.3 (VCC), J16.29 (VCC), J18.3 (VCC), J18.29 (VCC); also elsewhere on the board
isa_iq_1: J2.12, J3.4 (IRQ2), J8.12, J10.4 (IRQ2), J11.12, J12.4 (IRQ2), J13.12, J14.4 (IRQ2), J15.12, J16.4 (IRQ2), J17.12, J18.4 (IRQ2)
/AEN: J3.42 (AEN), J10.42 (AEN), J12.42 (AEN), J14.42 (AEN), J16.42 (AEN), J18.42 (AEN); also elsewhere on the board

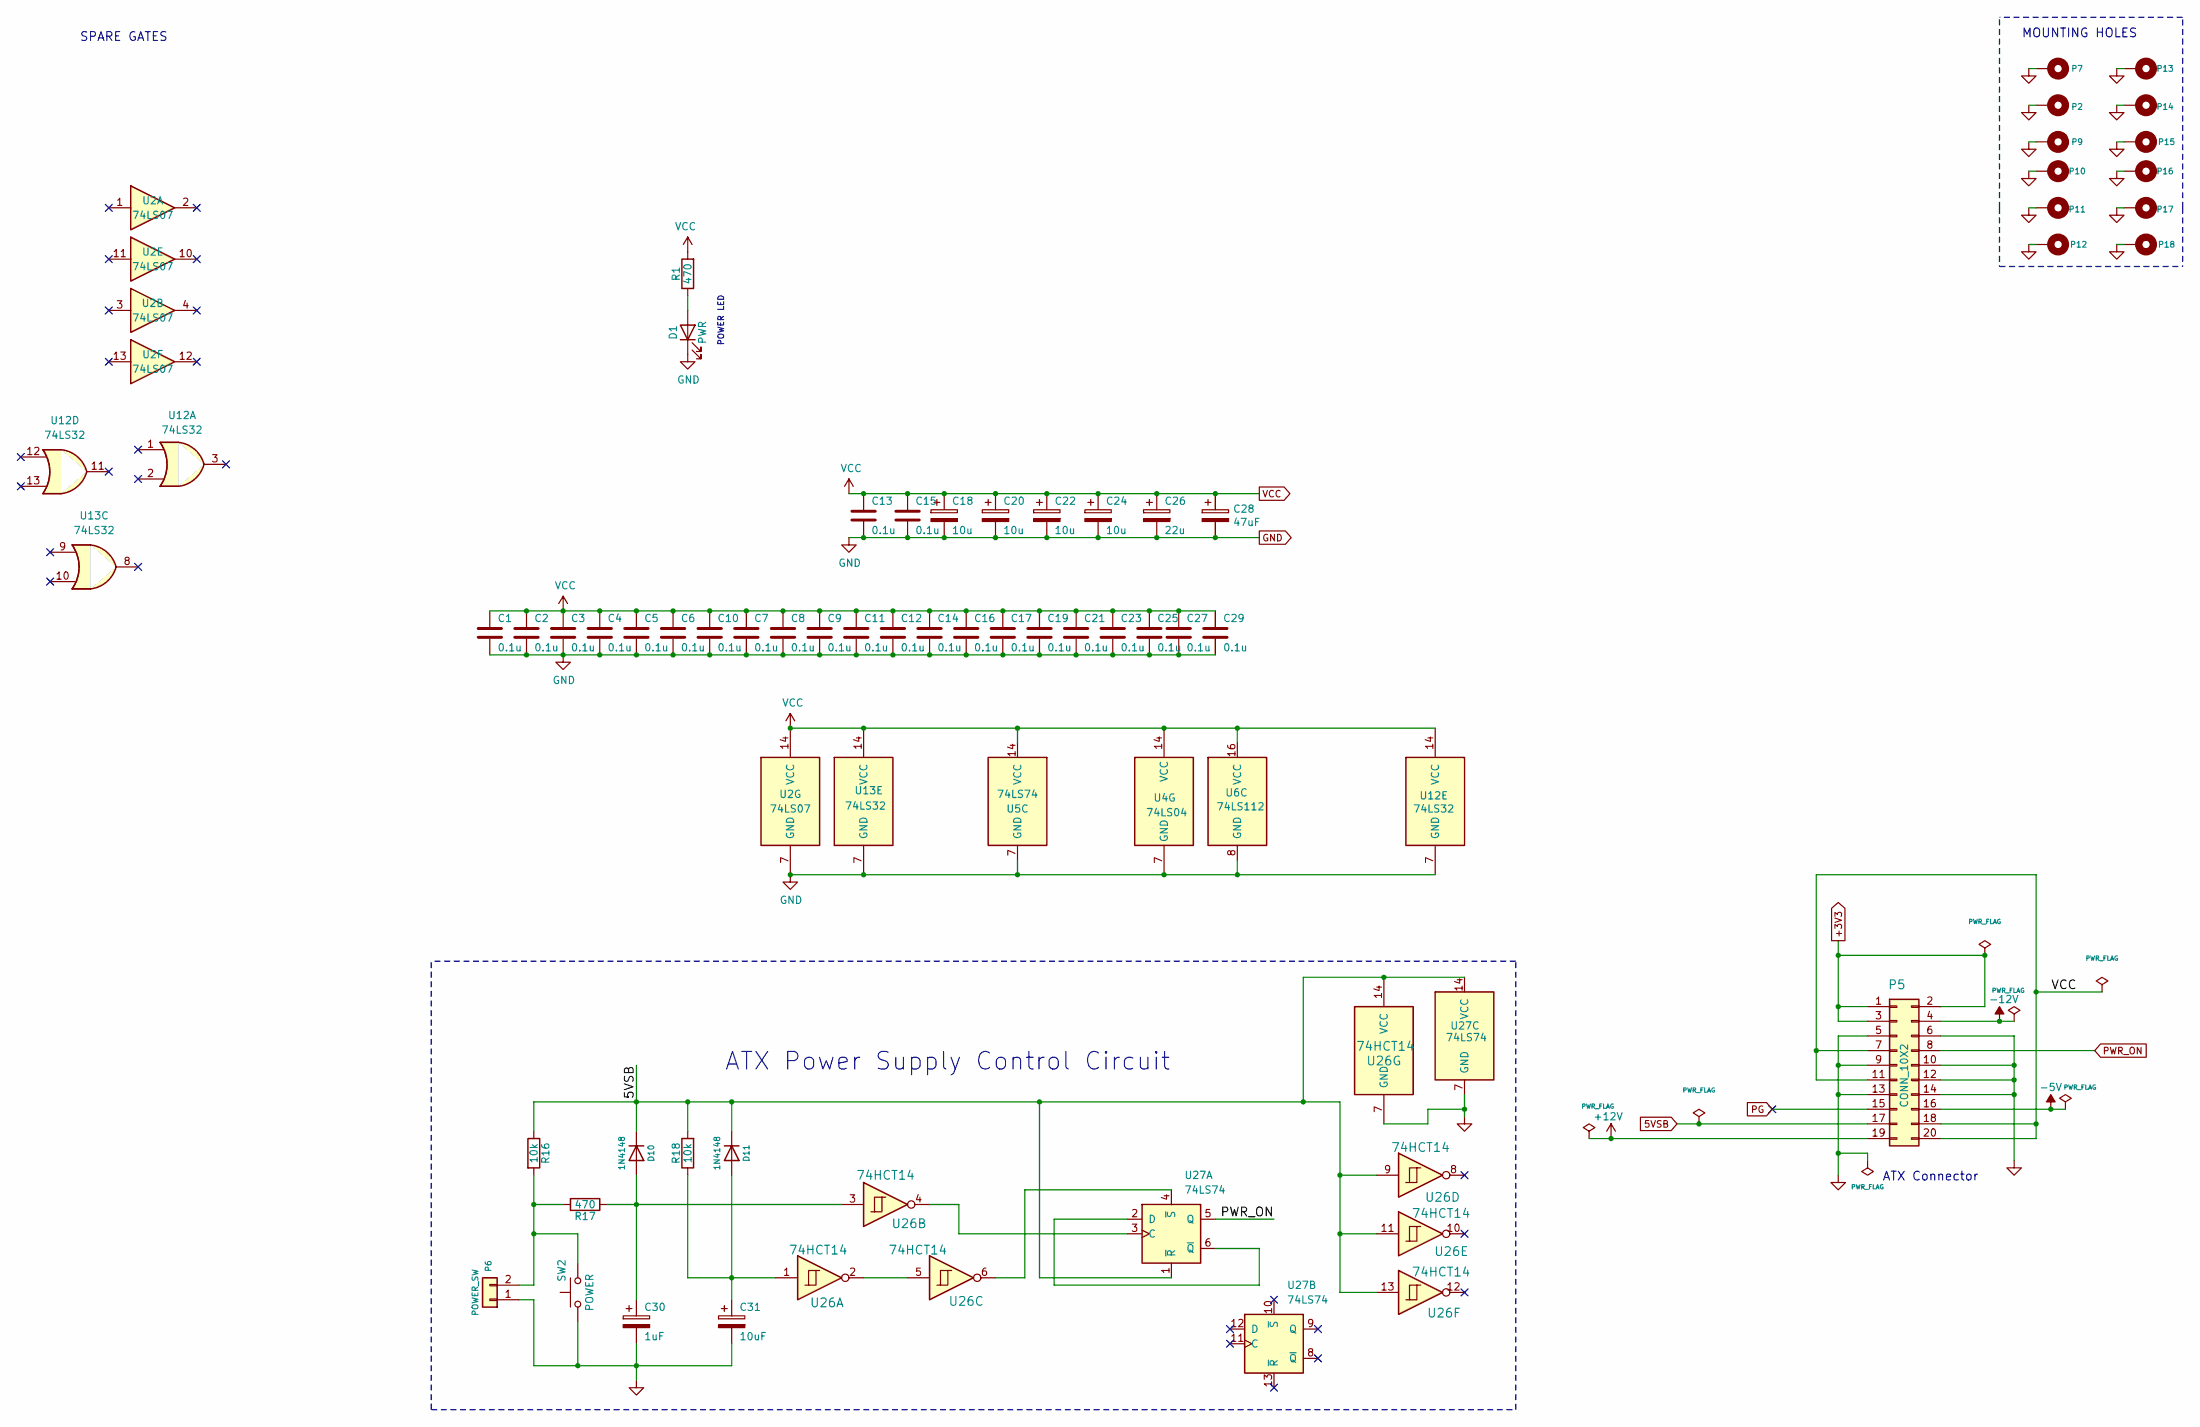
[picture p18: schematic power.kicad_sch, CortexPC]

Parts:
C1, C2, C3, C4, C5, C6, C7, C8, C9, C10, C11, C12, C13, C14, C15, C16, C17, C19, C21, C23, C25, C27, C29: 0.1u; STD_DDW_CAP
C18, C20, C22, C24: 10u; STD_DDW_PCAP
C26: 22u; STD_DDW_PCAP
C28: 47uF; STD_DDW_PCAP
C30: 1uF; STD_DDW_PCAP
C31: 10uF; STD_DDW_PCAP
D1: PWR; STD_DDW_LED5
D10, D11: 1N4148; STD_DDW_DIODE
P2, P7, P9, P10, P11, P12, P13, P14, P15, P16, P17, P18: CONN_1; MountingHole_3.2mm_M3_Pad_TopBottom
P5: CONN_10X2; ATXConnector
P6: POWER_SW; STD_DDW_PINHEAD_V_1x02
R1, R17: 470; STD_DDW_RESISTOR
R16, R18: 10k; STD_DDW_RESISTOR
SW2: POWER; STD_DDW_TACTSW
U2: 74LS07; STD_DDW_DIP14
U4: 74LS04; STD_DDW_DIP14
U5, U27: 74LS74; STD_DDW_DIP14
U6: 74LS112; STD_DDW_DIP16
U12, U13: 74LS32; STD_DDW_DIP14
U26: 74HCT14; STD_DDW_DIP14

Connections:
5VSB: D10.1 (K), D11.1 (K), P5.17, R16.1, R18.2, U26.9, U26.11, U26.13, U26.14 (VCC), U27.1 (~R), U27.14 (VCC)
+3V3: P5.1, P5.2, P5.3
+12V: P5.19; also elsewhere on the board
-5V: P5.16; also elsewhere on the board
-12V: P5.4; also elsewhere on the board
GND: C1.2, C2.2, C3.2, C4.2, C5.2, C6.2, C7.2, C8.2, C9.2, C10.2, C11.2, C12.2, C13.2, C14.2, C15.2, C16.2, C17.2, C18.2, C19.2, C20.2, C21.2, C22.2, C23.2, C24.2, C25.2, C26.2, C27.2, C28.2, C29.2, C30.2, C31.2, D1.1 (K), P2.1, P5.5, P5.6, P5.9, P5.10, P5.12, P5.13, P5.14, P6.1, P7.1, P9.1, P10.1, P11.1, P12.1, P13.1, P14.1, P15.1, P16.1, P17.1, P18.1, SW2.1, U2.7 (GND), U4.7 (GND), U5.7 (GND), U6.8 (GND), U12.7 (GND), U13.7 (GND), U26.7 (GND), U27.7 (GND); also elsewhere on the board
unnamed: D1.2 (A), R1.1
unnamed: C30.1, D10.2 (A), R17.1, U26.3
unnamed: C31.1, D11.2 (A), R18.1, U26.1
unnamed: P6.2, R16.2, R17.2, SW2.2
unnamed: U26.2, U26.5
unnamed: U26.4, U27.3 (C)
unnamed: U27.2 (D), U27.6 (~Q)
unnamed: U26.6, U27.4 (~S)
PG: P5.15
PWR_ON: P5.8, U27.5 (Q)
VCC: C1.1, C2.1, C3.1, C4.1, C5.1, C6.1, C7.1, C8.1, C9.1, C10.1, C11.1, C12.1, C13.1, C14.1, C15.1, C16.1, C17.1, C18.1, C19.1, C20.1, C21.1, C22.1, C23.1, C24.1, C25.1, C26.1, C27.1, C28.1, C29.1, P5.7, P5.11, P5.18, P5.20, R1.2, U2.14 (VCC), U4.14 (VCC), U5.14 (VCC), U6.16 (VCC), U12.14 (VCC), U13.14 (VCC); also elsewhere on the board

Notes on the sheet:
POWER LED
ATX Power Supply Control Circuit
MOUNTING HOLES
SPARE GATES
ATX Connector

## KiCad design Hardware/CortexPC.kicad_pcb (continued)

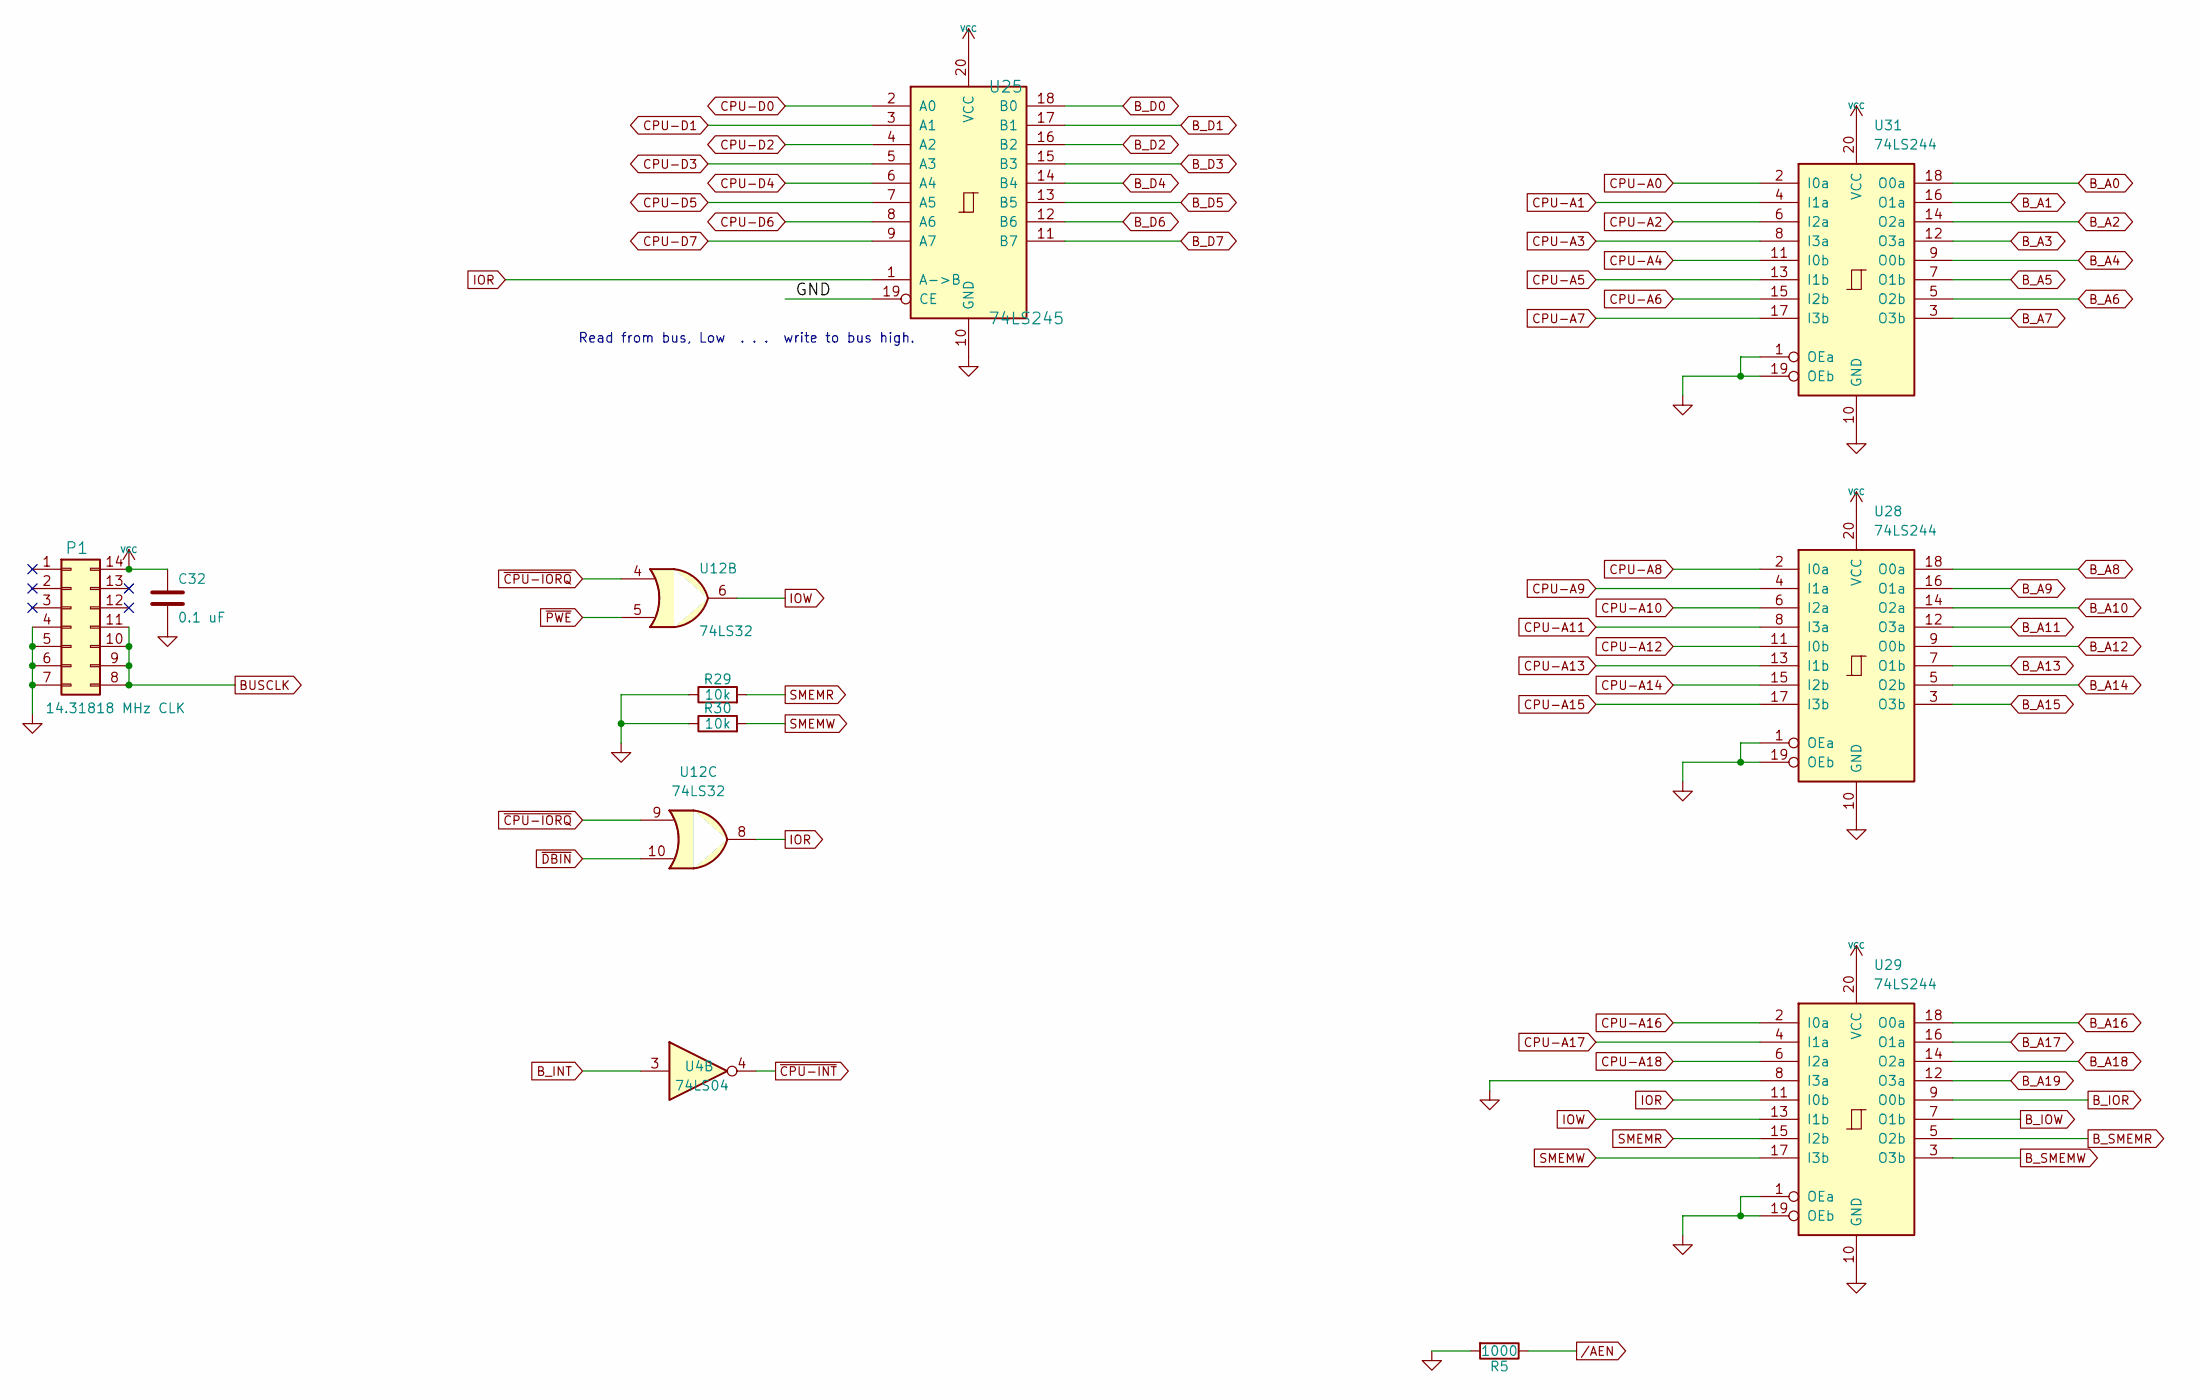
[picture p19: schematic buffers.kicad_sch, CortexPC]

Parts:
C32: 0.1 uF; STD_DDW_CAP
P1: 14.31818 MHz CLK; STD_DDW_DIP14
R5: 1000; STD_DDW_RESISTOR
R29, R30: 10k; STD_DDW_RESISTOR
U4: 74LS04; STD_DDW_DIP14
U12: 74LS32; STD_DDW_DIP14
U25: 74LS245; STD_DDW_DIP20
U28, U29, U31: 74LS244; STD_DDW_DIP20

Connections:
BUSCLK: P1.8, P1.9, P1.10, P1.11; also elsewhere on the board
B_A0: U31.18 (O0a); also elsewhere on the board
B_A1: U31.16 (O1a); also elsewhere on the board
B_A2: U31.14 (O2a); also elsewhere on the board
B_A3: U31.12 (O3a); also elsewhere on the board
B_A4: U31.9 (O0b); also elsewhere on the board
B_A5: U31.7 (O1b); also elsewhere on the board
B_A6: U31.5 (O2b); also elsewhere on the board
B_A7: U31.3 (O3b); also elsewhere on the board
B_A8: U28.18 (O0a); also elsewhere on the board
B_A9: U28.16 (O1a); also elsewhere on the board
B_A10: U28.14 (O2a); also elsewhere on the board
B_A11: U28.12 (O3a); also elsewhere on the board
B_A12: U28.9 (O0b); also elsewhere on the board
B_A13: U28.7 (O1b); also elsewhere on the board
B_A14: U28.5 (O2b); also elsewhere on the board
B_A15: U28.3 (O3b); also elsewhere on the board
B_A16: U29.18 (O0a); also elsewhere on the board
B_A17: U29.16 (O1a); also elsewhere on the board
B_A18: U29.14 (O2a); also elsewhere on the board
B_A19: U29.12 (O3a); also elsewhere on the board
B_D0: U25.18 (B0); also elsewhere on the board
B_D1: U25.17 (B1); also elsewhere on the board
B_D2: U25.16 (B2); also elsewhere on the board
B_D3: U25.15 (B3); also elsewhere on the board
B_D4: U25.14 (B4); also elsewhere on the board
B_D5: U25.13 (B5); also elsewhere on the board
B_D6: U25.12 (B6); also elsewhere on the board
B_D7: U25.11 (B7); also elsewhere on the board
B_INT: U4.3; also elsewhere on the board
B_IOR: U29.9 (O0b); also elsewhere on the board
B_IOW: U29.7 (O1b); also elsewhere on the board
B_SMEMR: U29.5 (O2b); also elsewhere on the board
B_SMEMW: U29.3 (O3b); also elsewhere on the board
CPU-A0: U31.2 (I0a); also elsewhere on the board
CPU-A1: U31.4 (I1a); also elsewhere on the board
CPU-A2: U31.6 (I2a); also elsewhere on the board
CPU-A3: U31.8 (I3a); also elsewhere on the board
CPU-A4: U31.11 (I0b); also elsewhere on the board
CPU-A5: U31.13 (I1b); also elsewhere on the board
CPU-A6: U31.15 (I2b); also elsewhere on the board
CPU-A7: U31.17 (I3b); also elsewhere on the board
CPU-A8: U28.2 (I0a); also elsewhere on the board
CPU-A9: U28.4 (I1a); also elsewhere on the board
CPU-A10: U28.6 (I2a); also elsewhere on the board
CPU-A11: U28.8 (I3a); also elsewhere on the board
CPU-A12: U28.11 (I0b); also elsewhere on the board
CPU-A13: U28.13 (I1b); also elsewhere on the board
CPU-A14: U28.15 (I2b); also elsewhere on the board
CPU-A15: U28.17 (I3b); also elsewhere on the board
CPU-A16: U29.2 (I0a); also elsewhere on the board
CPU-A17: U29.4 (I1a); also elsewhere on the board
CPU-A18: U29.6 (I2a); also elsewhere on the board
CPU-D0: U25.2 (A0); also elsewhere on the board
CPU-D1: U25.3 (A1); also elsewhere on the board
CPU-D2: U25.4 (A2); also elsewhere on the board
CPU-D3: U25.5 (A3); also elsewhere on the board
CPU-D4: U25.6 (A4); also elsewhere on the board
CPU-D5: U25.7 (A5); also elsewhere on the board
CPU-D6: U25.8 (A6); also elsewhere on the board
CPU-D7: U25.9 (A7); also elsewhere on the board
GND: C32.2, P1.4, P1.5, P1.6, P1.7, R5.2, R29.1, R30.1, U25.10 (GND), U25.19 (CE), U28.1 (OEa), U28.10 (GND), U28.19 (OEb), U29.1 (OEa), U29.8 (I3a), U29.10 (GND), U29.19 (OEb), U31.1 (OEa), U31.10 (GND), U31.19 (OEb); also elsewhere on the board
IOR: U12.8, U25.1 (A->B), U29.11 (I0b)
IOW: U12.6, U29.13 (I1b)
SMEMR: R29.2, U29.15 (I2b)
SMEMW: R30.2, U29.17 (I3b)
VCC: C32.1, P1.14, U25.20 (VCC), U28.20 (VCC), U29.20 (VCC), U31.20 (VCC); also elsewhere on the board
/AEN: R5.1; also elsewhere on the board
~CPU-INT: U4.4; also elsewhere on the board
~CPU-IORQ: U12.4, U12.9; also elsewhere on the board
~DBIN: U12.10; also elsewhere on the board
~PWE: U12.5; also elsewhere on the board

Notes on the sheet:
Read from bus, Low . . . write to bus high.

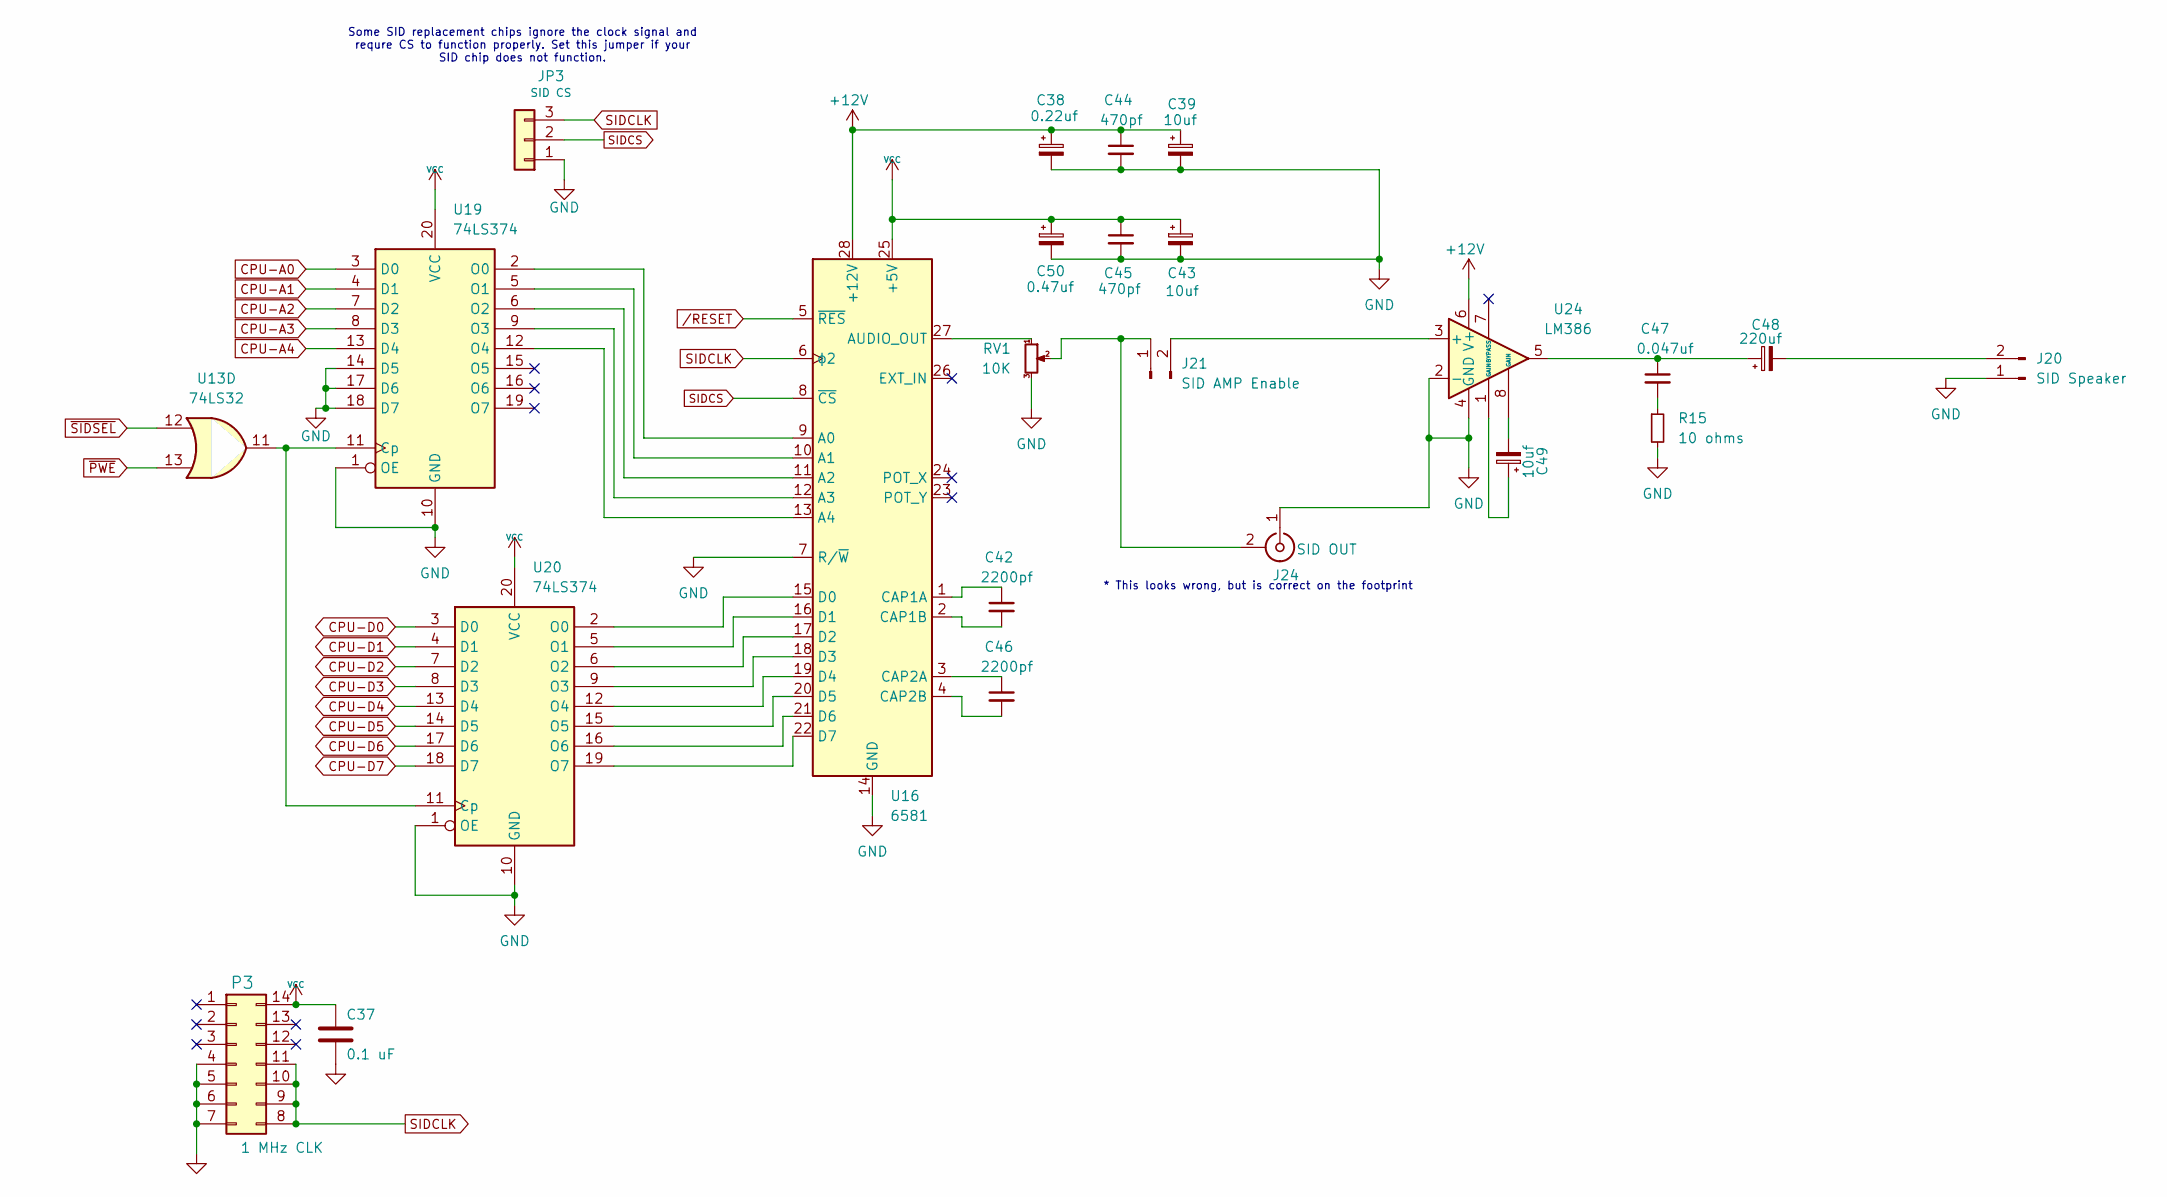
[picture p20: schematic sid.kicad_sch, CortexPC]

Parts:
C37: 0.1 uF; STD_DDW_CAP
C38: 0.22uf; STD_DDW_PCAP
C39, C43, C49: 10uf; STD_DDW_PCAP
C42, C46: 2200pf; STD_DDW_CAP
C44, C45: 470pf; STD_DDW_CAP
C47: 0.047uf; STD_DDW_CAP
C48: 220uf; STD_DDW_PCAP
C50: 0.47uf; STD_DDW_PCAP
J20: SID Speaker; STD_DDW_PINHEAD_V_1x02
J21: SID AMP Enable; STD_DDW_PINHEAD_V_1x02
J24: SID OUT; CUI_RCJ-047
JP3: SID CS; STD_DDW_PINHEAD_V_1x03
P3: 1 MHz CLK; STD_DDW_DIP14
R15: 10 ohms; STD_DDW_RESISTOR
RV1: 10K; Potentiometer_Bourns_3386F_Vertical
U13: 74LS32; STD_DDW_DIP14
U16: 6581; STD_DDW_DIP28
U19, U20: 74LS374; STD_DDW_DIP20
U24: LM386; STD_DDW_DIP8

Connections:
+12V: C38.1, C39.1, C44.1, U16.28 (+12V), U24.6 (V+); also elsewhere on the board
CPU-A0: U19.3 (D0); also elsewhere on the board
CPU-A1: U19.4 (D1); also elsewhere on the board
CPU-A2: U19.7 (D2); also elsewhere on the board
CPU-A3: U19.8 (D3); also elsewhere on the board
CPU-A4: U19.13 (D4); also elsewhere on the board
CPU-D0: U20.3 (D0); also elsewhere on the board
CPU-D1: U20.4 (D1); also elsewhere on the board
CPU-D2: U20.7 (D2); also elsewhere on the board
CPU-D3: U20.8 (D3); also elsewhere on the board
CPU-D4: U20.13 (D4); also elsewhere on the board
CPU-D5: U20.14 (D5); also elsewhere on the board
CPU-D6: U20.17 (D6); also elsewhere on the board
CPU-D7: U20.18 (D7); also elsewhere on the board
GND: C37.2, C38.2, C39.2, C43.2, C44.2, C45.2, C50.2, J20.1, J24.1 (In), JP3.1, P3.4, P3.5, P3.6, P3.7, R15.2, RV1.3, U16.7 (R/~W), U16.14 (GND), U19.1 (OE), U19.10 (GND), U19.14 (D5), U19.17 (D6), U19.18 (D7), U20.1 (OE), U20.10 (GND), U24.2 (-), U24.4 (GND); also elsewhere on the board
unnamed: C47.1, C48.1, U24.5
unnamed: C47.2, R15.1
unnamed: C49.1, U24.1 (GAIN)
unnamed: C49.2, U24.8 (GAIN)
unnamed: C48.2, J20.2
unnamed: J21.1, J24.2 (Ext), RV1.2
unnamed: J21.2, U24.3 (+)
unnamed: U16.9 (A0), U19.2 (O0)
unnamed: U16.10 (A1), U19.5 (O1)
unnamed: U16.11 (A2), U19.6 (O2)
unnamed: U16.12 (A3), U19.9 (O3)
unnamed: U16.13 (A4), U19.12 (O4)
unnamed: RV1.1, U16.27 (AUDIO_OUT)
unnamed: C42.1, U16.1 (CAP1A)
unnamed: C42.2, U16.2 (CAP1B)
unnamed: C46.1, U16.3 (CAP2A)
unnamed: C46.2, U16.4 (CAP2B)
unnamed: U16.15 (D0), U20.2 (O0)
unnamed: U16.16 (D1), U20.5 (O1)
unnamed: U16.17 (D2), U20.6 (O2)
unnamed: U16.18 (D3), U20.9 (O3)
unnamed: U16.19 (D4), U20.12 (O4)
unnamed: U16.20 (D5), U20.15 (O5)
unnamed: U16.21 (D6), U20.16 (O6)
unnamed: U16.22 (D7), U20.19 (O7)
unnamed: U13.11, U19.11 (Cp), U20.11 (Cp)
SIDCLK: JP3.3, P3.8, P3.9, P3.10, P3.11, U16.6 (ϕ2)
SIDCS: JP3.2, U16.8 (~CS)
VCC: C37.1, C43.1, C45.1, C50.1, P3.14, U16.25 (+5V), U19.20 (VCC), U20.20 (VCC); also elsewhere on the board
/RESET: U16.5 (~RES); also elsewhere on the board
~PWE: U13.13; also elsewhere on the board
~SIDSEL: U13.12; also elsewhere on the board

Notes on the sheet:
Some SID replacement chips ignore the clock signal and requre CS to function properly. Set this jumper if your SID chip does not function.
* This looks wrong, but is correct on the footprint

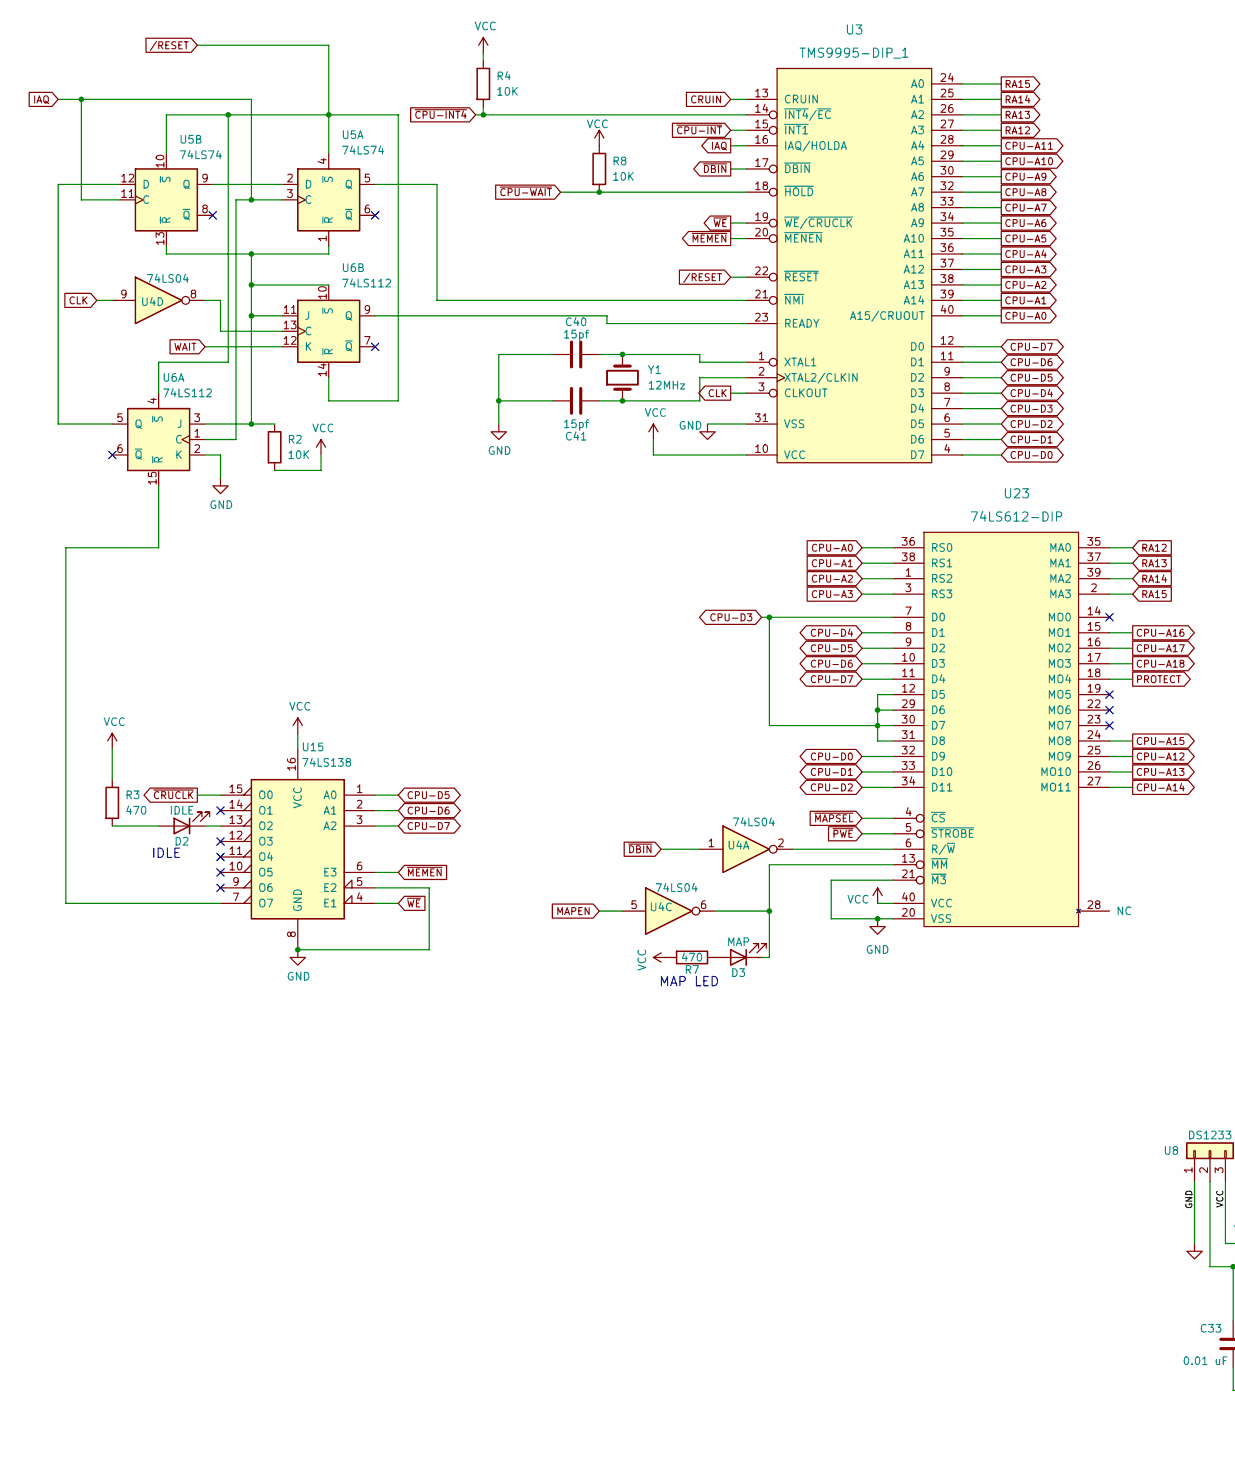
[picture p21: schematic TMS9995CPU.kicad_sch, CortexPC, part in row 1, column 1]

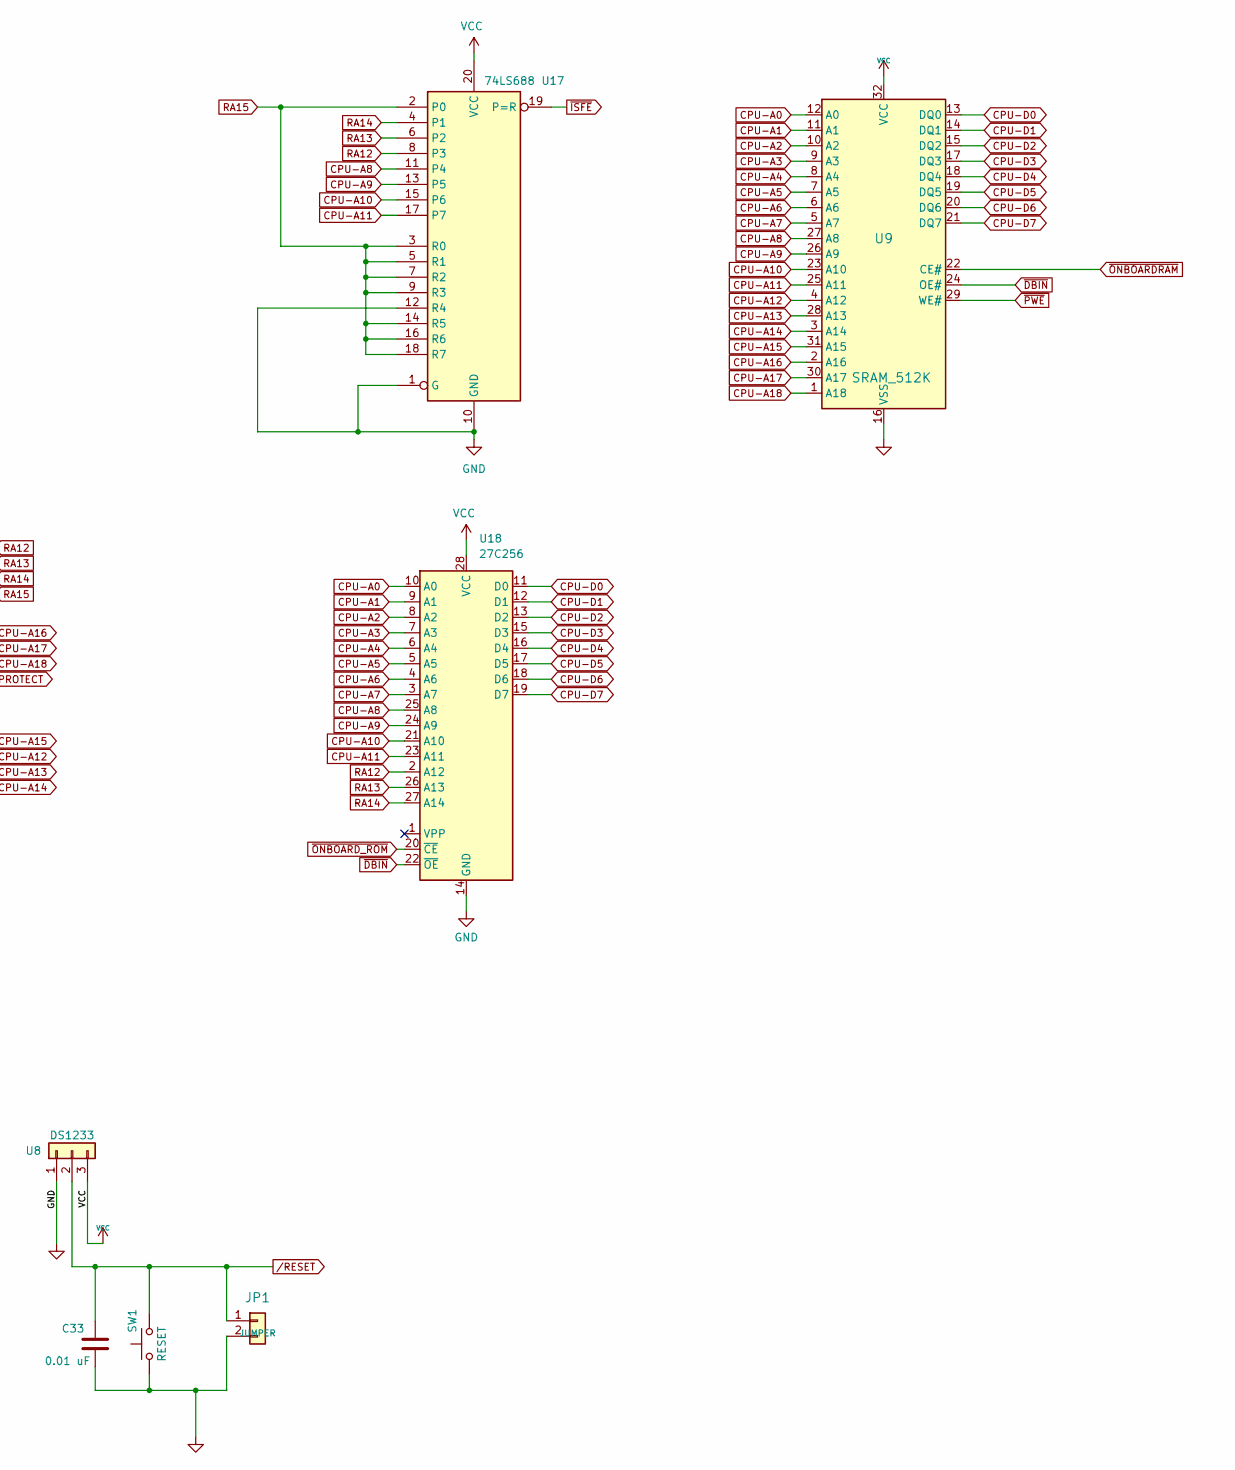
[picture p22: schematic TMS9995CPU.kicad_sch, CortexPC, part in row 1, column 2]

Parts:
C33: 0.01 uF; STD_DDW_CAP
C40, C41: 15pf; STD_DDW_CAP
D2: IDLE; STD_DDW_LED5
D3: MAP; STD_DDW_LED5
JP1: JUMPER; STD_DDW_PINHEAD_V_1x02
R2, R4, R8: 10K; STD_DDW_RESISTOR
R3, R7: 470; STD_DDW_RESISTOR
SW1: RESET; STD_DDW_TACTSW
U3: TMS9995-DIP_1; STD_DDW_DIP40
U4: 74LS04; STD_DDW_DIP14
U5: 74LS74; STD_DDW_DIP14
U6: 74LS112; STD_DDW_DIP16
U8: DS1233; STD_DDW_TO92
U9: SRAM_512K; STD_DDW_DIP32
U15: 74LS138; STD_DDW_DIP16
U17: 74LS688; STD_DDW_DIP20
U18: 27C256; STD_DDW_DIP28
U23: 74LS612-DIP; STD_DDW_DIP40
Y1: 12MHz; STD_DDW_XTAL

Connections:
CLK: U3.3 (CLKOUT), U4.9; also elsewhere on the board
CPU-A0: U3.40 (A15/CRUOUT), U9.12 (A0), U18.10 (A0), U23.36 (RS0); also elsewhere on the board
CPU-A1: U3.39 (A14), U9.11 (A1), U18.9 (A1), U23.38 (RS1); also elsewhere on the board
CPU-A2: U3.38 (A13), U9.10 (A2), U18.8 (A2), U23.1 (RS2); also elsewhere on the board
CPU-A3: U3.37 (A12), U9.9 (A3), U18.7 (A3), U23.3 (RS3); also elsewhere on the board
CPU-A4: U3.36 (A11), U9.8 (A4), U18.6 (A4); also elsewhere on the board
CPU-A5: U3.35 (A10), U9.7 (A5), U18.5 (A5); also elsewhere on the board
CPU-A6: U3.34 (A9), U9.6 (A6), U18.4 (A6); also elsewhere on the board
CPU-A7: U3.33 (A8), U9.5 (A7), U18.3 (A7); also elsewhere on the board
CPU-A8: U3.32 (A7), U9.27 (A8), U17.11 (P4), U18.25 (A8); also elsewhere on the board
CPU-A9: U3.30 (A6), U9.26 (A9), U17.13 (P5), U18.24 (A9); also elsewhere on the board
CPU-A10: U3.29 (A5), U9.23 (A10), U17.15 (P6), U18.21 (A10); also elsewhere on the board
CPU-A11: U3.28 (A4), U9.25 (A11), U17.17 (P7), U18.23 (A11); also elsewhere on the board
CPU-A12: U9.4 (A12), U23.25 (MO9); also elsewhere on the board
CPU-A13: U9.28 (A13), U23.26 (MO10); also elsewhere on the board
CPU-A14: U9.3 (A14), U23.27 (MO11); also elsewhere on the board
CPU-A15: U9.31 (A15), U23.24 (MO8); also elsewhere on the board
CPU-A16: U9.2 (A16), U23.15 (MO1); also elsewhere on the board
CPU-A17: U9.30 (A17), U23.16 (MO2); also elsewhere on the board
CPU-A18: U9.1 (A18), U23.17 (MO3); also elsewhere on the board
CPU-D0: U3.4 (D7), U9.13 (DQ0), U18.11 (D0), U23.32 (D9); also elsewhere on the board
CPU-D1: U3.5 (D6), U9.14 (DQ1), U18.12 (D1), U23.33 (D10); also elsewhere on the board
CPU-D2: U3.6 (D5), U9.15 (DQ2), U18.13 (D2), U23.34 (D11); also elsewhere on the board
CPU-D3: U3.7 (D4), U9.17 (DQ3), U18.15 (D3), U23.7 (D0), U23.12 (D5), U23.29 (D6), U23.30 (D7), U23.31 (D8); also elsewhere on the board
CPU-D4: U3.8 (D3), U9.18 (DQ4), U18.16 (D4), U23.8 (D1); also elsewhere on the board
CPU-D5: U3.9 (D2), U9.19 (DQ5), U15.1 (A0), U18.17 (D5), U23.9 (D2); also elsewhere on the board
CPU-D6: U3.11 (D1), U9.20 (DQ6), U15.2 (A1), U18.18 (D6), U23.10 (D3); also elsewhere on the board
CPU-D7: U3.12 (D0), U9.21 (DQ7), U15.3 (A2), U18.19 (D7), U23.11 (D4); also elsewhere on the board
CRUIN: U3.13 (CRUIN); also elsewhere on the board
GND: C33.2, C40.1, C41.1, JP1.2, SW1.1, U3.31 (VSS), U6.2 (K), U8.1, U9.16 (VSS), U15.5 (E2), U15.8 (GND), U17.1 (G), U17.10 (GND), U17.12 (R4), U18.14 (GND), U23.20 (VSS), U23.21 (~M3); also elsewhere on the board
IAQ: U3.16 (IAQ/HOLDA), U5.3 (C), U5.11 (C), U6.1 (C)
MAPEN: U4.5; also elsewhere on the board
unnamed: D2.2 (A), R3.2
unnamed: D2.1 (K), U15.13 (O2)
unnamed: D3.2 (A), R7.1
unnamed: D3.1 (K), U4.6, U23.13 (~MM)
unnamed: U3.23 (READY), U6.9 (Q)
unnamed: C40.2, U3.1 (XTAL1), Y1.2
unnamed: C41.2, U3.2 (XTAL2/CLKIN), Y1.1
unnamed: U3.21 (~NMI), U5.5 (Q)
unnamed: U5.2 (D), U5.9 (Q)
unnamed: R2.1, U5.1 (~R), U5.13 (~R), U6.3 (J), U6.10 (~S), U6.11 (J)
unnamed: U5.12 (D), U6.5 (Q)
unnamed: U4.8, U6.13 (C)
unnamed: U6.15 (~R), U15.7 (O7)
unnamed: U4.2, U23.6 (R/~W)
PROTECT: U23.18 (MO4); also elsewhere on the board
RA12: U3.27 (A3), U17.8 (P3), U18.2 (A12), U23.35 (MA0)
RA13: U3.26 (A2), U17.6 (P2), U18.26 (A13), U23.37 (MA1)
RA14: U3.25 (A1), U17.4 (P1), U18.27 (A14), U23.39 (MA2)
RA15: U3.24 (A0), U17.2 (P0), U17.3 (R0), U17.5 (R1), U17.7 (R2), U17.9 (R3), U17.14 (R5), U17.16 (R6), U17.18 (R7), U23.2 (MA3); also elsewhere on the board
VCC: R2.2, R3.1, R4.1, R7.2, R8.1, U3.10 (VCC), U8.3, U9.32 (VCC), U15.16 (VCC), U17.20 (VCC), U18.28 (VCC), U23.40 (VCC); also elsewhere on the board
WAIT: U6.12 (K); also elsewhere on the board
/RESET: C33.1, JP1.1, SW1.2, U3.22 (~RESET), U5.4 (~S), U5.10 (~S), U6.4 (~S), U6.14 (~R), U8.2; also elsewhere on the board
~CPU-INT4: R4.2, U3.14 (~INT4/~EC); also elsewhere on the board
~CPU-INT: U3.15 (~INT1); also elsewhere on the board
~CPU-WAIT: R8.2, U3.18 (~HOLD)
~CRUCLK: U15.15 (O0); also elsewhere on the board
~DBIN: U3.17 (~DBIN), U4.1, U9.24 (OE#), U18.22 (~OE); also elsewhere on the board
~ISFE: U17.19 (P=R); also elsewhere on the board
~MAPSEL: U23.4 (~CS); also elsewhere on the board
~MEMEN: U3.20 (~MENEN), U15.6 (E3); also elsewhere on the board
~ONBOARDRAM: U9.22 (CE#); also elsewhere on the board
~ONBOARD_ROM: U18.20 (~CE); also elsewhere on the board
~PWE: U9.29 (WE#), U23.5 (~STROBE); also elsewhere on the board
~WE: U3.19 (~WE/~CRUCLK), U15.4 (E1); also elsewhere on the board

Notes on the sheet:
MAP LED
IDLE

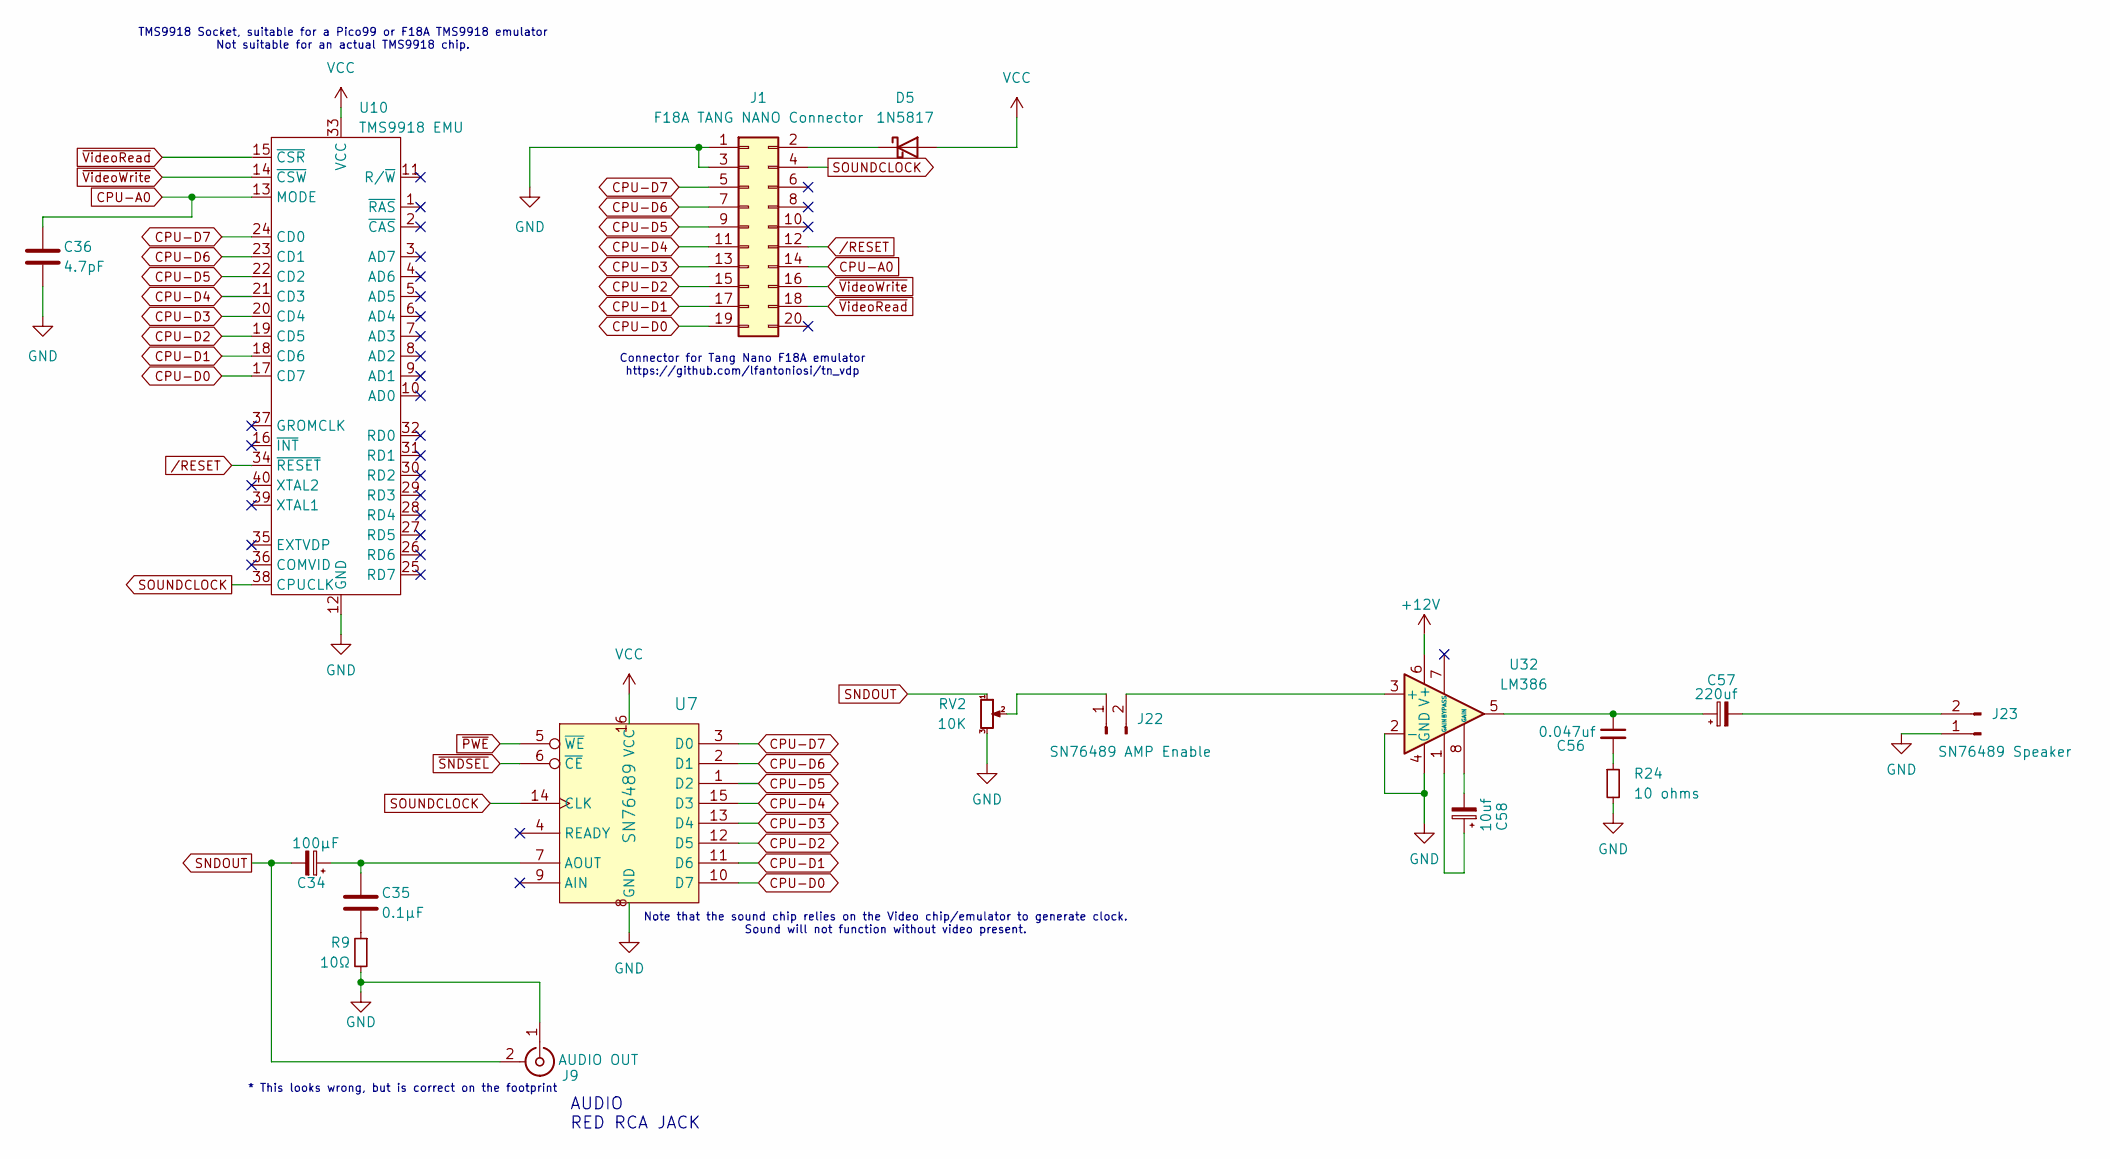
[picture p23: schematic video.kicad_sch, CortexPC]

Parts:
C34: 100µF; STD_DDW_PCAP
C35: 0.1µF; STD_DDW_CAP
C36: 4.7pF; STD_DDW_CAP
C56: 0.047uf; STD_DDW_CAP
C57: 220uf; STD_DDW_PCAP
C58: 10uf; STD_DDW_PCAP
D5: 1N5817; STD_DDW_DIODE
J1: F18A TANG NANO Connector; STD_DDW_PinHeader_2x10
J9: AUDIO OUT; CUI_RCJ-047
J22: SN76489 AMP Enable; STD_DDW_PINHEAD_V_1x02
J23: SN76489 Speaker; STD_DDW_PINHEAD_V_1x02
R9: 10Ω; STD_DDW_RESISTOR
R24: 10 ohms; STD_DDW_RESISTOR
RV2: 10K; Potentiometer_Bourns_3386F_Vertical
U7: SN76489; STD_DDW_DIP16
U10: TMS9918 EMU; STD_DDW_DIP40
U32: LM386; STD_DDW_DIP8

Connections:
+12V: U32.6 (V+); also elsewhere on the board
CPU-A0: C36.1, J1.14, U10.13 (MODE); also elsewhere on the board
CPU-D0: J1.19, U7.10 (D7), U10.17 (CD7); also elsewhere on the board
CPU-D1: J1.17, U7.11 (D6), U10.18 (CD6); also elsewhere on the board
CPU-D2: J1.15, U7.12 (D5), U10.19 (CD5); also elsewhere on the board
CPU-D3: J1.13, U7.13 (D4), U10.20 (CD4); also elsewhere on the board
CPU-D4: J1.11, U7.15 (D3), U10.21 (CD3); also elsewhere on the board
CPU-D5: J1.9, U7.1 (D2), U10.22 (CD2); also elsewhere on the board
CPU-D6: J1.7, U7.2 (D1), U10.23 (CD1); also elsewhere on the board
CPU-D7: J1.5, U7.3 (D0), U10.24 (CD0); also elsewhere on the board
GND: C36.2, J1.1, J1.3, J9.1 (In), J23.1, R9.2, R24.2, RV2.3, U7.8 (GND), U10.12 (GND), U32.2 (-), U32.4 (GND); also elsewhere on the board
unnamed: C35.2, R9.1
unnamed: C56.1, C57.1, U32.5
unnamed: C56.2, R24.1
unnamed: C58.1, U32.1 (GAIN)
unnamed: C58.2, U32.8 (GAIN)
unnamed: D5.1 (K), J1.2
unnamed: J22.1, RV2.2
unnamed: J22.2, U32.3 (+)
unnamed: C57.2, J23.2
unnamed: C34.1, C35.1, U7.7 (AOUT)
SNDOUT: C34.2, J9.2 (Ext), RV2.1
SOUNDCLOCK: J1.4, U7.14 (CLK), U10.38 (CPUCLK)
VCC: D5.2 (A), U7.16 (VCC), U10.33 (VCC); also elsewhere on the board
/RESET: J1.12, U10.34 (~RESET); also elsewhere on the board
~PWE: U7.5 (~WE); also elsewhere on the board
~SNDSEL: U7.6 (~CE); also elsewhere on the board
~VideoRead: J1.18, U10.15 (~CSR); also elsewhere on the board
~VideoWrite: J1.16, U10.14 (~CSW); also elsewhere on the board

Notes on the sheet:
AUDIO RED RCA JACK
Connector for Tang Nano F18A emulator https://github.com/lfantoniosi/tn_vdp
* This looks wrong, but is correct on the footprint
Note that the sound chip relies on the Video chip/emulator to generate clock. Sound will not function without video present.
TMS9918 Socket, suitable for a Pico99 or F18A TMS9918 emulator Not suitable for an actual TMS9918 chip.

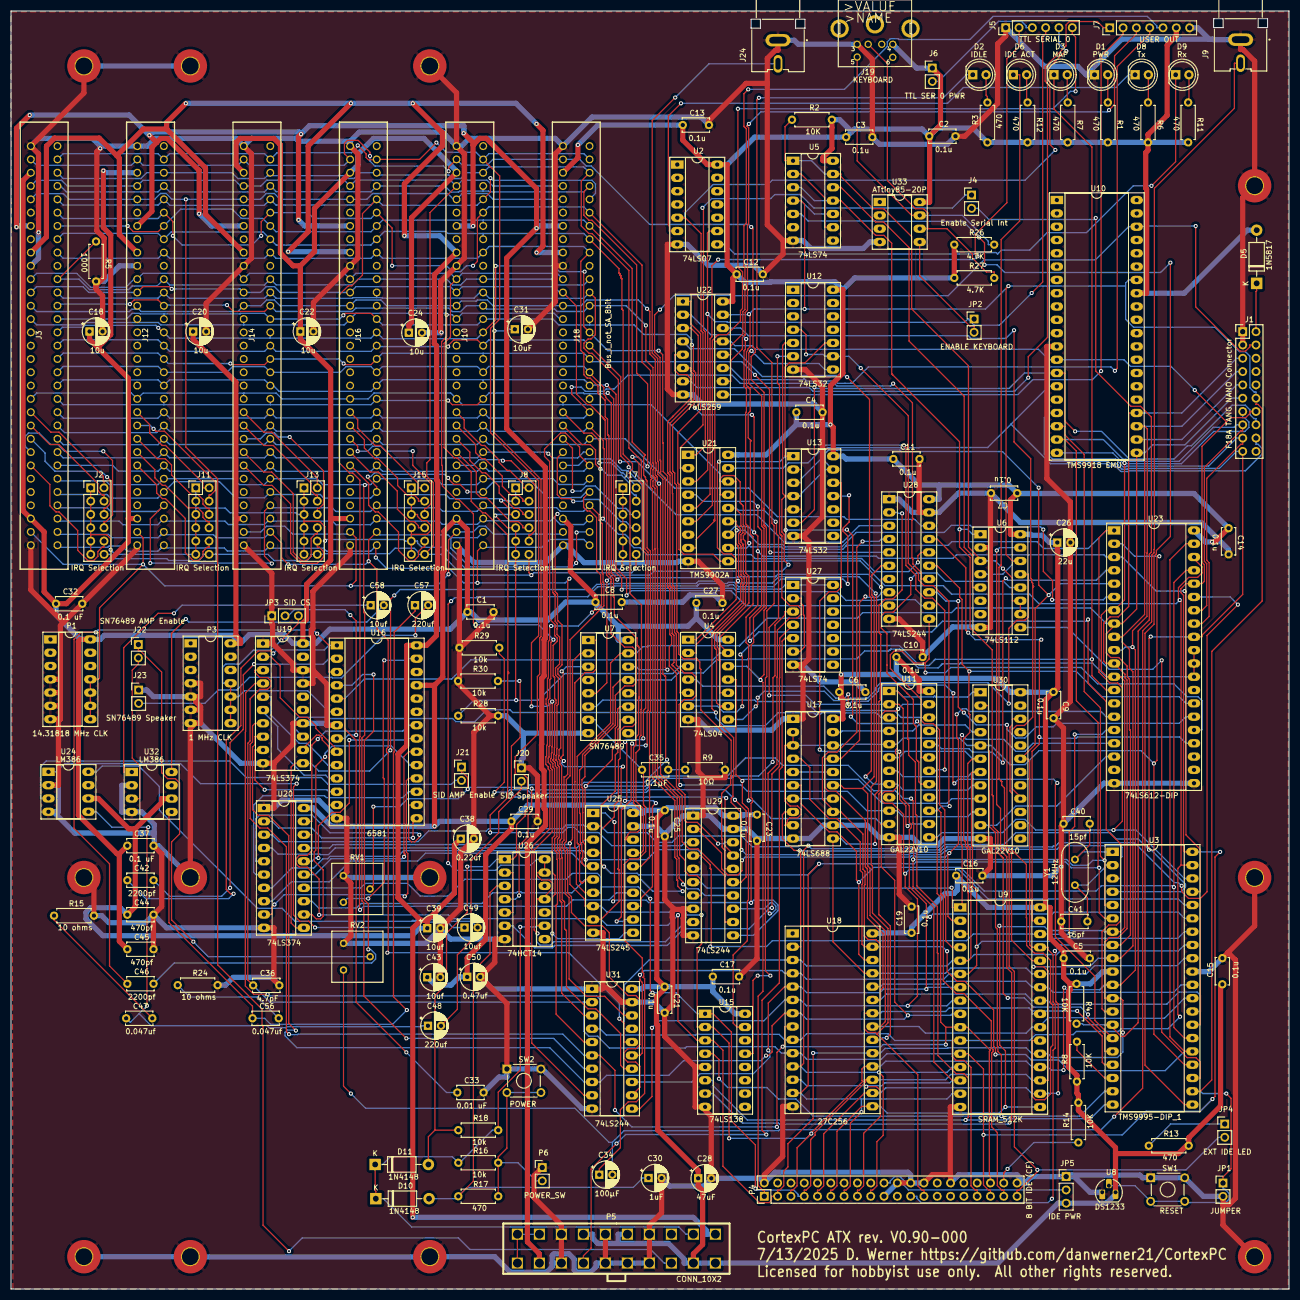
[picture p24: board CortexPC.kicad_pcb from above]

Board: 2 copper layers, 244.0 x 244.0 mm, 167 parts (0 on the bottom side), 226 nets.

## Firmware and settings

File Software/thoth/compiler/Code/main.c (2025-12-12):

#include <stdio.h>
#include <unistd.h>
#include <fcntl.h>
#include <stdlib.h>
#include <string.h>

#include "code.h"
#include "load.h"
#include "ti_opcodes.h"

#define TRUE  1
#define FALSE 0

int IFile;
int SFile;

int
Get(void)
{
    char ch;
    
    if( read(IFile, &ch, 1) <= 0 ) {
        exit(1);
    }
    return (ch & 0xff);
}

int
GetW(void)
{
    return (Get() << 8) + Get();
}

int
GetR(void)
{
    int val;
    
    val = Get();
    if( val & 0x80 ) {
        val = (val & 0x7f) + (Get() << 7);
    }
    return val;
}

void
Get_name(int id, char *name)
{
    char ch;
    int i;

    lseek(SFile, id, SEEK_SET);
    for( i = 0; i < 32; ++i ) {
        if( read(SFile, &ch, 1) < 0 )
            Error("cannot read strings file");
        if( ch == 0 ) break;
        *name++ = ch;
    }
    if( i < 32 ) *name = 0;
}

void
Error(char *msg)
{
    fprintf(stderr, "%s\n", msg);
    exit(1);
}

void
print_lstr(int str_id)
{
    char ch;
    int len, i;

    lseek(SFile, str_id, SEEK_SET);
    read(SFile, &ch, 1);
    len = ch;
    read(SFile, &ch, 1);
    len = (len << 8) + ch;
    printf("\"");
    for( i = 0; i < len - 1; ++i ) {
        read(SFile, &ch, 1);
        if( ch == 0 )
            printf("*$00");  
        else if( ch == 10 )
            printf("*n");  
        else
            printf("%c", ch);  
    }
    printf("\"");
}
    
/*====================*/

int Auto_top;
int Autovec_top;
int Temp_top;
int Framesizelocn;
int Arg_count;
extern int *Counter;

extern struct Symbol *R[];

#define WSD_AUTO 255
#define WSD_VEC  254
#define WSD_TEMP 253
#define ALIGN_EXTRN 2

struct Symbol*
Next_auto( int ref )
{
    struct Symbol *p;

    p = Sym_find( ref, TRUE );
    if( p->ref == ref )
        Error("Reference redefined");

    Arg_count++;
    Auto_top -= 2;

    p->ref = ref;
    if( Auto_top == 6 ) Auto_top = -2;
    p->value   = Auto_top;
    p->type    = AUTO_TYPE | WSD_AUTO;
    p->addrmod = AUTO_ADDRMOD;
    return( p );
}

struct Symbol *
Next_temp()
{
    struct Symbol *sym;
    
    if( Auto_top > 8 ) {
        Auto_top -= 2;
        return( &Sym_pseudo[Auto_top >> 1] );
    }
    
    Temp_top -= 2;
    sym = Sym_alloc();
    sym->value = Temp_top;
    sym->type = AUTO_TYPE | WSD_TEMP;
    sym->addrmod = AUTO_ADDRMOD;
    return( sym );
}

void
Next_autovec( struct Symbol *V, int size, int byte )
{
    struct Symbol *p;
    
    ++size; // 0 to n inclusive => n + 1 cells
    if( !byte ) size *= 2;
    if( size & 1 ) ++size; // round up to even
    Code( _MOV_, R[12], R[11] );
    Load_word( 0x22c ); // ai r12, xxxx
    Rload_word( ADDR_RELDESC, WSD_VEC, Autovec_top );
    Code( _MOV_, V, R[12] );
    Autovec_top += size;
}

void
Def_const( int ref, int const_val )
{
    struct Symbol *p;

    p = Sym_find( ref, TRUE );
    if( p->ref == ref )
        Error("Reference redefined");
    p->ref  = ref;
    p->type = CONST_TYPE;
    p->addrmod = INDEXED_MODE;
    p->const_value = (short)const_val;
}

void
Process_string( int str_id, struct Symbol *p, int type )
{
    unsigned char ch;
    int i, len, save;
    
    p->type = STRING_TYPE | (PTR_RELDESC<<8) | WSD_STRING;
    p->addrmod = INDEXED_MODE;
    p->str_id = str_id;

    // Only load regular strings, not twit strings
    if( type == '"' ) {
        lseek(SFile, str_id, SEEK_SET);
        read(SFile, &ch, 1);
        len = ch;
        read(SFile, &ch, 1);
        len = (len << 8) + ch;
        save = Set_loc( WSD_STRING );
        p->value = *Counter;
        for( i = 0; i < len; ++i ) {
            read(SFile, &ch, 1);
            Load_byte( ch );
        }
        if( *Counter & 1 ) *Counter += 1;
        Set_loc( save );
    }
}

void
Def_string( int ref, int str_id, int type )
{
    struct Symbol *p;

    p = Sym_find( ref, TRUE );
    if( p->ref == ref )
        Error("Reference redefined");
    p->ref  = ref;
    Process_string( str_id, p, type );
}

void
Def_extrn( int ref, int wsd )
{
    struct Symbol *p;

    p = Sym_find( ref, TRUE );
    if( p->ref == ref )
        Error("Reference redefined");
    p->ref  = ref;
    p->type = EXTRN_TYPE | (ADDR_RELDESC<<8) | wsd;
    p->addrmod = INDEXED_MODE;
}

void
Enable_gen(void)
{
    Code( _LIMI_, Constant(9), NULL );
}

void
Disable_gen(void)
{
    Code( _LIMI_, Constant(0), NULL );
}

int Wsd_next;

int
Wsd_index()
{
    return Wsd_next++;
}

int Prolog_done;
int Args_unbounded;
struct Symbol *R13_save_lcn = &Sym_pseudo[28];

/* Change all arguments to use R13 as base instead
 * of R11 (the frame base). Used for functions with
 * an unbounded argument count (i.e. using '?')
 */
void
Adjust_args(void)
{
    int i;
    struct Symbol *arg;
    
    for( i = 1; i <= Arg_count; ++i )
    {
        arg = Sym_find( i<<1, FALSE );
        if( !arg ) Error("argument not found");
        arg->addrmod = ARG_ADDRMOD;
    }
}

/* Determine which function prolog subroutine to call
 * based on whether the function contains an unbounded 
 * number of arguments (ie. 'questionable').
 * Generate the code to call the subroutine.
 * Save the code segment location at which to stuff the
 * stack increment via Epilog_gen.
 */
void
Prolog_gen(int nargs)
{
    /* Set up R11, new frame base. The argument
     * to "AI R11, ..." gets plugged by Epilog_gen.
     */
    Code( _STWP_, R[11], NULL );
    Load_word( _AI_ + 11 );      /* AI R11, ... */
    Framesizelocn = *Counter;
    Load_word( 0 );
    Args_unbounded = FALSE;

    /* If the function is 'questionable', save
     * R13 and replace by current WS pointer.
     * Adjust the arguments to use R13 as base.
     */
    if( nargs == 0377 ) {
        Code( _MOV_, R13_save_lcn, R[15] );
        Code( _STWP_, R[15], NULL );
        Adjust_args();
        Auto_top = 0;
        Args_unbounded = TRUE;
    }
}

/* Define 1oca1 symbo1s "..auto", "..vec", and "..temp".
 * Dump the remainder of the constant/address pool
 * Backplug the framesize location used in the prolog.
 */
void
Epilog_gen()
{
    int next_frame, frame_size;
    
    //Dump_pool();

    Auto_top = ( Auto_top > 0 ) ? 0 : -Auto_top;
//fprintf(stderr, "auto %d, vec %d, temp %d\n", Auto_top, Autovec_top, -Temp_top);
    frame_size = Auto_top + Autovec_top - Temp_top + 32 + 2;
    if( Args_unbounded ) frame_size += 2;
    next_frame = frame_size;
    Flush_load_bufs();
    
    Set_load_L_addr( WSD_CODE, Framesizelocn );
    Load_word( -next_frame ); /* stuff stack increment */
    *Counter -= 2; /* repair proper size of module; */
    
    Put_load_def( 'T', ABSOLUTE_RB, next_frame, "..auto" );
    next_frame -= Auto_top + Autovec_top;
    Put_load_def( 'T', ABSOLUTE_RB, next_frame, "..temp" );
    Put_load_def( 'T', ABSOLUTE_RB, next_frame, "..vec" );
    
    //Set_frame_size( frame_size ); /* save for stack bounding */
    Flush_load_bufs();
}

void
Return_gen()
{
    if( Args_unbounded ) {
        Code( _MOV_, R[15], R13_save_lcn );
    }
    Code( _RTWP_, NULL, NULL );
}

extern int Last_nargs;

void
Clean_tifunc(void)
{
    Auto_top = 22;
    Autovec_top = 0;
    Temp_top = 0;
    Arg_count = 0;
    Last_nargs = -1;
}

char Module_name[32];
int Code_rb;
int Data_rb;
int Strings_rb;
int In_twit;

#include "../Parse/il_opc.h"

void
Func_gen(void)
{
    int token, val, ref, i;
    int minarg, maxarg, segs, retval;
    char name[32];
    struct Symbol *sym;
    struct Expr *expr;
    static char E_rec[6] = "E\4\0\0\0\0";

    Prolog_done = FALSE;
    Set_loc( WSD_CODE );
    Flush_load_bufs();
    while( (token = Get()) != 0 ) {
        switch( token ) {
        
        /* ==== function header and declarations ==== */

        case 'a':  /* argument */
            sym = Next_auto( GetR() );
            break;

        case 'P':  /* prolog min, max, seg */
            Put_M_dir( EXTRN_RB, ALIGN_EXTRN, Module_name );
            Put_load_def( 'G', EXTRN_RB, 0, Module_name );
            minarg = Get(); maxarg = Get(); segs = Get();
            retval = FALSE;
//fprintf(stderr, "min %d, max %d, seg %d\n", minarg, maxarg, segs);
            Code_rb =  segs       & 0xf; if( Code_rb == 15 ) Code_rb = CODE_RB;
            Data_rb = (segs >> 4) & 0xf; if( Data_rb == 15 ) Data_rb = DATA_RB;
            Put_load_def( 'T', Data_rb,   0, "..data" );
            Put_load_ref( 't', WSD_DATA,   "..data" );
            Put_load_def( 'T', Code_rb,   0, "..code" );
            Put_load_ref( 't', WSD_CODE,   "..code" );
            Put_load_def( 'T', STRING_RB, 0, "..string" );
            Put_load_ref( 't', WSD_STRING, "..string" );
            Put_load_ref( 't', WSD_AUTO, "..auto" );
            Put_load_ref( 't', WSD_VEC,  "..vec"  );
            Put_load_ref( 't', WSD_TEMP, "..temp" );
            Set_loc( WSD_DATA );
            Rload_word( PTR_RELDESC, WSD_CODE, 0 );
            Set_loc( WSD_CODE );
            Prolog_gen( maxarg );
            Prolog_done = TRUE;
            break;

        case 'A':  /* auto */
            sym = Next_auto( GetR() );
            break;
        
        case 'V':  /* auto vector */
        case 'v':  /* auto string */
            sym = Next_auto( GetR() );
            val = GetW();
            Next_autovec(sym, val, token == 'v');
            break;

        case 'g':  /* external name */
            val = Wsd_index();
            Def_extrn( GetR(), val );
            Get_name( GetW(), name );
            Put_load_ref( 'g', val, name );
            break;
        
        case 'c':  /* declare constant REF */
            ref = GetR();
            val = GetW();
            Def_const( ref, val );
            break;

        case '\'': /* declare twit string */
        case '"':  /* declare string REF */
            ref = GetR();
            val = GetW();
            Def_string( ref, val, token );
            break;

        case 'H':  /* start of executable body */
            break;

        /* ===== statements ====== */

        case 'E': /* expression */
            expr = Build_tree();
            //Expr_print( expr );
            expr = Modify( expr );
            //Expr_print( expr );
            expr = Allocate_registers( expr, NULL );
            //Expr_print( expr );
            Arith_expr_gen( expr );
            break;
        
        case 'R': /* return */
            expr = Build_tree();
            if( expr ) {
                retval = TRUE;
                expr = Modify( expr );
                expr = Allocate_registers( expr, R[12] );
                Arith_expr_gen( expr );
            }
            Return_gen();
            break;
        
        case 'l':  /* label */
            sym = Sym_label( GetR() );
            Backplug_gen( sym );
            Last_nargs = -1;
            break;
            
        case 'J': /* goto label */
            sym = Sym_label( GetR() );
            Jump_gen( sym );
            Flush_load_bufs();
            break;

        case 'T': /* if  expr goto label */
        case 'F': /* if !expr goto label */
            sym = Sym_label( GetR() );
            expr = Build_tree();
            expr = Modify( expr );
            //Expr_print( expr );
            expr = Allocate_registers( expr, R[12] );
            //Expr_print( expr );
            Logical_expr_gen( expr, sym, (token == 'T') );
            break;
            
        case 'W': /* select word */        
        case 'S': /* select string */
            expr = Build_tree();
            expr = Modify( expr );
            expr = Allocate_registers( expr, R[12] );
            Arith_expr_gen( expr );
            Start_select();
            break;
        
        case 'r': /* case <const>::<const> */
            val = GetW();
            ref = GetW();
            Do_case( val, ref );
            break;
        
        case 'i': /* case <const> */
        case 'b': /* case <str> */
            val = GetW();
            Do_case( val, val );
            break;
                    
        case 'D': /* default */
            Def_case();
            break;
        
        case 'w': /* end select word */
            Wdselect_gen();
            break;

        case 's': /* end select string */
            Str_select();
            break;
            
        case 'e':
            Enable_gen();
            break;
            
        case 'd':
            Disable_gen();
            break;
                    
        case 't':
            In_twit = TRUE;
            expr = Build_tree();
            In_twit = FALSE;
            Twit_gen( expr );
            break;

        default: 
            fprintf( stderr, "unrecognised IL statement: '%c'\n", token);
        }
    }
    Set_loc( 0 );
    for( i=1; i<4; ++i) {
        ++Counter;
        Put_I_dir(i, *Counter);
    }
    Epilog_gen();
    E_rec[2] = minarg;  // minimum args
    E_rec[3] = maxarg;  // maximum args
    E_rec[4] = TRUE;    // needs arg count
    E_rec[5] = retval;  // returns value
    Put_load_dir( E_rec  );
}

void
process_cleanil(void)
{
    int token, val, ref;
    static int once = 0;

    while( (token = Get()) != 0 )
    {
        Clean();
        Sym_clean();
        Clean_tifunc();
        Wsd_next = 5;

        switch( token ) {

        case '(':  /* function def */
            Get_name( GetW(), Module_name );
            Func_gen();
            break;

        default: {
            fprintf( stderr, "unrecognised cleanil statement: '%c'\n", token);
            }
        }
    }
}

int
main()
{
    if( (IFile = open("functions", O_RDONLY)) < 0 ) {
        fprintf( stderr, "cannot open parsil functions file\n");
        exit(1);
    }
    if( (SFile = open("strings", O_RDONLY)) < 0 ) {
        fprintf( stderr, "cannot open strings file\n");
        exit(1);
    }
    OFile = 1;

    //Gen_start();
    process_cleanil();
    return(0);
}

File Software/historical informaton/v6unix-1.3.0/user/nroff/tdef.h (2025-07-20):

#define	MAXPTR	(char *)-1	/* max value of any pointer variable */
#ifdef NROFF	/*NROFF*/
#define EM t.Em
#define HOR t.Hor
#define VERT t.Vert
#define INCH 240	/*increments per inch*/
#define SPS INCH/10	/*space size*/
#define SS INCH/10	/* " */
#define TRAILER 0
#define UNPAD 0227
#define PO 0 /*page offset*/
#define ASCII 1
#define PTID 1
#define LG 0
#define DTAB 0	/*set at 8 Ems at init time*/
#define ICS 2*SPS
#define TEMP 256	/*65K*/
#endif
#ifndef NROFF	/*TROFF*/
#define INCH 432	/*troff resolution*/
#define SPS 20	/*space size at 10pt; 1/3 Em*/
#define SS 12	/*space size in 36ths of an em*/
#define TRAILER 6048	/*144*14*3 = 14 inches*/
#define UNPAD 027
#define PO 416 /*page offset 26/27ths inch*/
#define HOR 1
#define VERT 3
#define EM (6*(pts&077))
#define ASCII 0
#define PTID 0
#define LG 1
#define DTAB (INCH/2)
#define ICS 3*SPS
#define TEMP 512	/*128K*/
#endif

#include <signal.h>
#define NARSP 0177	/*narrow space*/
#define HNSP 0226	/*half narrow space*/
#define PS 10	/*default point size*/
#define FT 0	/*default font position*/
#define LL 75*INCH/10	/*line length; 39picas=6.5in*/
#define VS INCH/6	/*vert space; 12points*/
#define NN 200	/*number registers*/
/* NN changed Jan 31 from 132 */
#define NNAMES 14 /*predefined reg names*/
#define NIF 15	/*if-else nesting*/
#define NS 64	/*name buffer*/
#define NTM 256	/*tm buffer*/
#define NEV 3	/*environments*/
#define EVLSZ 10	/*size of ev stack*/
#define EVS 4*256	/*environment size in words*/
/* BWK - trying 4*256 instead of 3*256 */
#define NM 300	/*requests + macros*/
#define DELTA 512	/*delta core bytes*/
#define NHYP 10	/*max hyphens per word*/
#define NHEX 128	/*byte size of exception word list*/
#define NTAB 35	/*tab stops*/
#define NSO 5	/*"so" depth*/
#define WDSIZE 170	/*word buffer size*/
#define LNSIZE 680	/*line buffer size*/
/* BWK - changed from 480 after EVS changed */
#define NDI 5	/*number of diversions*/
#define DBL 0100000	/*double size indicator*/
#define MOT 0100000	/*motion character indicator*/
#define MOTV 0160000	/*clear for motion part*/
#define VMOT 0040000	/*vert motion bit*/
#define NMOT 0020000	/* negative motion indicator*/
#define MMASK 0100000	/*macro mask indicator*/
#define CMASK 0100377
#define ZBIT 0400	/*zero width char*/
#define BMASK 0377
#define BYTE 8
#define IMP 004	/*impossible char*/
#define FILLER 037
#define PRESC 026
#define HX 0376	/*High-order part of xlss*/
#define LX 0375	/*low-order part of xlss*/
#define CONT 025
#define COLON 013
#define XPAR 030
#define ESC 033
#define FLSS 031
#define RPT 014
#define JREG 0374
#define NTRAP 20	/*number of traps*/
#define NPN 20	/*numbers in "-o"*/
#define T_PAD 0101	/*cat padding*/
#define T_INIT 0100
#define T_IESC 16 /*initial offset*/
#define T_STOP 0111
#define NPP 10	/*pads per field*/
#define FBUFSZ 256	/*field buf size words*/
#define OBUFSZ 512	/*bytes*/
#define IBUFSZ 512	/*bytes*/
#define NC 256	/*cbuf size words*/
#define NOV 10	/*number of overstrike chars*/
#define ZONE 5	/*5hrs for EST*/
#define TDELIM 032
#define LEFT 035
#define RIGHT 036
#define LEADER 001
#define TAB 011
#define TMASK  037777
#define RTAB 0100000
#define CTAB 0040000
#define OHC 024

#define PAIR(A,B) (A|(B<<BYTE))

#define BLK  128	/*alloc block words*/
#ifdef BIG
typedef long filep;
#define NBLIST BIG	/*allocation , BIG = 256 per 65k*/
#define BLKBITS 7	/*for BLK=128*/
#endif
#ifndef BIG
typedef unsigned filep;
#define NBLIST TEMP	/*allocation list, TEMP<=512*/
/* BLK*NBLIST<=65536 words, if filep=unsigned */
#define BLKBITS 0
#endif

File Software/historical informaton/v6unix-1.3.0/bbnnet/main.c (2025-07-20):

#include <stdio.h>
#include <fcntl.h>
#include <unistd.h>
#include <string.h>
#include <errno.h>

#include "param.h"
#include "sysnet.h"

#include "inet.h"
#include "net.h"
#include "mbuf.h"
#include "ifcb.h"
#include "tcp.h"
#include "ip.h"
#include "ucb.h"
#include "fsm.h"

extern struct net netcb;
extern struct host hosts[NHOST], *host, *hostNHOST;

extern struct work works[NWORK], *workfree, *workNHOST, *workNWORK;
extern int nwork;

extern struct gway gates[NGATE], *gateway, *gateNGATE;
extern int ngate;

extern struct mbuf  mbuffers[NMBUF+1];
extern struct mbuf* mbuf_free;

#ifdef BUFSTAT
struct buf_stat bufnull = { 0 };
#endif /* BUFSTAT */

extern int usr_request();
extern int usr_reply();

/*
 * Initialize memory
 */
static void
meminit()
{
	register struct mbuf* p;
	register int i;

	p = (struct mbuf*)((int)(mbuffers+1) & ~0x7f);
	mbuf_free = p;
	for(i = 0; i < NMBUF-1; i++) {
		memset (p, 0, sizeof (struct mbuf));
		p->m_next = p+1;
		p++;
	}

	memset (&hosts, 0, sizeof (hosts));
	memset (&works, 0, sizeof (works));

	host = &hosts[0];
	hostNHOST = &hosts[NHOST-1];

	workfree = &works[0];
	workNWORK = &works[NWORK-1];

	gateway = &gates[0];
	gateNGATE = &gates[0];
	ngate = 0;
}

/*
 * Net timer routine: scheduled every second, calls ip and tcp timeout routines
 * and does any net-wide statistics.
 */
static void
net_timer ()
{
#ifdef BUFSTAT
   register struct mbuf *m, *n;
   register struct ucb *up;
   register struct tcb *tp;
   register struct th *t;
   register struct ifcb *lp;
   register struct ipq *ip;
   register struct ip *i;
   register struct host *h;
   register struct work *w;
#endif

   ip_timeo ();
   tcp_timeo ();

#ifdef BUFSTAT
   bufstat = bufnull;
   for (up = netcb.n_ucb_hd; up != NULL; up = up->uc_next)
   {
      if (up->uc_flags & UTCP)
      {
         if ((tp = up->uc_tcb) == NULL)
            continue;
         bufstat.b_tcbs++;
         if (tp->t_state != ESTAB)
            bufstat.b_cons--;
         if ((t = tp->t_rcv_next) == NULL)
            continue;
         for (; t != (struct th *) tp; t = t->t_next)
         {
            m = dtom (t);
            while (m != NULL)
            {
               bufstat.b_tseq++;
               m = m->m_next;
            }
         }
         for (m = tp->t_rcv_unack; m != NULL; m = m->m_act)
         {
            n = m;
            do
            {
               bufstat.b_tuna++;
               n = n->m_next;
            }
            while (n != NULL);
         }
      }
      bufstat.b_cons++;
      bufstat.b_useq += up->uc_rsize + up->uc_ssize;
   }
   for (ip = netcb.n_ip_head; ip != NULL; ip = ip->iq_next)
      for (i = ip->iqx.ip_next; i != (struct ip *) ip; i = i->ip_next)
      {
         m = dtom (i);
         while (m != NULL)
         {
            bufstat.b_ipfr++;
            m = m->m_next;
         }
      }
   for (lp = netcb.n_ifcb_hd; lp != NULL; lp = lp->if_next)
   {
      for (m = lp->if_outq_hd; m != NULL; m = m->m_act)
      {
         n = m;
         do
         {
            bufstat.b_devq++;
            n = n->m_next;
         }
         while (n != NULL);
      }
      for (m = lp->if_outq_cur; m != NULL; m = m->m_next)
         bufstat.b_devq++;
      for (m = lp->if_inq_hd; m != NULL; m = m->m_act)
      {
         n = m;
         do
         {
            bufstat.b_devq++;
            n = n->m_next;
         }
         while (n != NULL);
      }
      for (m = lp->if_inq_msg; m != NULL; m = m->m_next)
         bufstat.b_devq++;
   }
   for (h = host; h < hostNHOST; h++)
      if (h->h_refct > 0)
         for (m = h->h_outq; m != NULL; m = m->m_act)
         {
            n = m;
            do
            {
               bufstat.b_rfnm++;
               n = n->m_next;
            }
            while (n != NULL);
         }
   for (w = netcb.n_work; w != NULL; w = w->w_next)
      if (w->w_type == INRECV || w->w_type == IUSEND)
         for (m = dtom (w->w_dat); m != NULL; m = m->m_next)
            bufstat.b_work++;
#endif /* BUFSTAT */
}

/*
 * Generic local net reset:  clear input and output queues and call driver
 * init routine.
 */
void
netreset (ip)
     register struct ifcb *ip;
{
   register struct mbuf *m, *n;

   ip->if_avail = FALSE;

   /*
    * clear all i/f queues
    */
   for (m = ip->if_inq_hd; m != NULL; m = n)
   {
      n = m->m_act;
      m_freem (m);
   }
   ip->if_inq_hd = NULL;
   ip->if_inq_tl = NULL;

   for (m = ip->if_outq_hd; m != NULL; m = n)
   {
      n = m->m_act;
      m_freem (m);
   }
   ip->if_outq_hd = NULL;
   ip->if_outq_tl = NULL;

   if (ip->if_inq_msg != NULL)
   {
      m_freem (ip->if_inq_msg);
      ip->if_inq_msg = NULL;
      ip->if_inq_cur = NULL;
   }

   if (ip->if_outq_cur != NULL)
   {
      m_freem (ip->if_outq_cur);
      ip->if_outq_cur = NULL;
   }

   h_reset (ip->if_addr);
   ip->if_resets++;

   /*
    * now call net driver specific init routine to reinit
    */
   (*ip->if_init) (ip);
}

char *
scantok (cp, t)
     char *cp;
     char *t;
{
   *t = 0;
   while (*cp && (*cp == ' ' || *cp == '\t'))
      cp++;
   while (*cp && *cp != ' ' && *cp != '\n' && *cp != '\t')
      *t++ = *cp++;
   *t = 0;
   return (cp);
}

/*
 * Read the gateway file into the gateway table.  The file
 * contains gateway structure entries produced from the ASCII gateway
 * table.  Called from netmain or netioctl, returns number of entries
 * successfully read or -1 if error
 */
static int
gatinit ()
{
   char *cp;
   register int i;
   FILE *fd;
   register struct ifcb *lp;
   register struct gway *gp;
   struct socket ipa;
   struct gway gatent;
   char *gatefile = "/etc/gateways";
   char buff[80], token[20];

   /* set up to read the gateway file */

   if ((fd = fopen (gatefile, "r")) == NULL)
   {
      printf ("Can't open gateway file: %s: %s\n",
              gatefile, sys_errlist[errno]);
      return (-1);
   }

   /* read entries from the file into the table */

   for (gp = gateway, i = NGATE; i > 0; i--)
   {
    READ_AGAIN:
      if ((fgets (buff, sizeof (buff), fd)) == NULL)
      {
	 if (ferror (fd))
	 {
	    printf ("Can't read gateway file: %s: %s\n",
		    gatefile, sys_errlist[errno]);
	 }
         goto out;
      }

      /* Scan off gateway components */

      cp = scantok (buff, token);
      if (token[0] == '#' || token[0] == 0)
         goto READ_AGAIN;

      memset (&gatent, 0, sizeof (gatent));

      ipa.s_addr = inet_addr (token);
      gatent.g_lnet = iptonet (ipa);

      cp = scantok (cp, token);
      ipa.s_addr = inet_addr (token);
      gatent.g_fnet = iptonet (ipa);

      cp = scantok (cp, token);
      gatent.g_local.s_addr = inet_addr (token);

      cp = scantok (cp, token);
      gatent.g_flags = atoi (token);
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

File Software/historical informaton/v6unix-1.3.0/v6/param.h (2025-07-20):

/*
 * tunable variables
 */

#ifdef TI_CTX
#define	CMAPSIZ	8		/* size of core allocation area */
#else
#define	CMAPSIZ	31		/* size of core allocation area */
#endif
#define	SMAPSIZ	8		/* size of swap allocation area */

#define	NBUF	15		/* size of buffer cache */
#define	NINODE	100		/* number of in core inodes */
#define	NFILE	100		/* number of in core file structures */
#define	NMOUNT	5		/* number of mountable file systems */
#define	NEXEC	3		/* number of simultaneous exec's */
#define	MAXMEM	(56)		/* max core per process in KB */
#define	SSIZE	20		/* initial stack size (*64 bytes) */
#define	SINCR	20		/* increment of stack (*64 bytes) */
#define	NOFILE	15		/* max open files per process */
#define	CANBSIZ	256		/* max size of typewriter line */
#define	NCALL	20		/* max simultaneous time callouts */
#define	NPROC	CMAPSIZ+SMAPSIZ-1 /* max number of processes */
#define	NTEXT	40		/* max number of pure texts */
#define	NCLIST	100		/* max total clist size */
#define	HZ	60		/* Ticks/second of the clock */

#define NNETREQ	10		/* Number of outstanding network requests */

#define SWPBLKS	1024		/* number of swap area disk blocks */

#define BOTUSR 0x1000
#define TOPUSR 0xf000
#define UCORE  0xe000

#define BSHIFT 9
#define BSIZE  512

/*
 * priorities
 * probably should not be
 * altered too much
 */

#define	PSWP	-100
#define	PINOD	-90
#define	PRIBIO	-50
#define PRINET	-40
#define	PPIPE	1
#define	PWAIT	40
#define	PSLEP	90
#define	PUSER	100

#define PZERO	25

/*
 * signals
 * dont change
 */

#define	NSIG	20
#define		SIGHUP	1	/* hangup */
#define		SIGINT	2	/* interrupt (^C) */
#define		SIGQIT	3	/* quit (^\) */
#define		SIGINS	4	/* illegal instruction */
#define		SIGTRC	5	/* trace or breakpoint */
#define		SIGIOT	6	/* iot */
#define		SIGEMT	7	/* emt */
#define		SIGFPT	8	/* floating exception */
#define		SIGKIL	9	/* kill */
#define		SIGBUS	10	/* bus error */
#define		SIGSEG	11	/* segmentation violation */
#define		SIGSYS	12	/* sys */
#define		SIGPIPE	13	/* end of pipe */

/*
 * fundamental constants
 * cannot be changed
 */

#define	USIZE	1024		/* size of user block in bytes */
#ifndef NULL
#define	NULL	0
#endif
#define	NODEV	(-1)
#define	ROOTINO	1		/* i number of all roots */
#define	DIRSIZ	14		/* max characters per directory */

#define daddr_t unsigned int
#define time_t  unsigned long

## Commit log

2025-06-09 update with SID
    [CortexPC.kicad_sch, GALS.kicad_sch, power.kicad_sch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]
2025-07-20 cortex work
    [CortexPC-B_Cu.gbr, CortexPC-B_Mask.gbr, CortexPC-B_Paste.gbr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]
2025-08-11 rom source updates
    [EPROM Dump - Hex & ASCII.txt, atnf.obj, bitf.obj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]
2025-08-11 rom work
    [bootsel.obj, mdexboot.obj, monitor.obj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]
2025-12-12 add new software
    [EPROM Dump - Hex & ASCII.txt, bootsel.obj, mdexboot.obj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]
